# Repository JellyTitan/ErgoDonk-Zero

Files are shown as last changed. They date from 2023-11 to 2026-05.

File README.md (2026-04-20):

# ErgoDonk Zero Keyboard

ErgoDonk Zero is a 6×9+6 keys split ortholinear keyboard with encoder & solenoid support, hotswap sockets for MX or Choc v1 low profile switches, and uses the RP2040 "Zero" MCU.

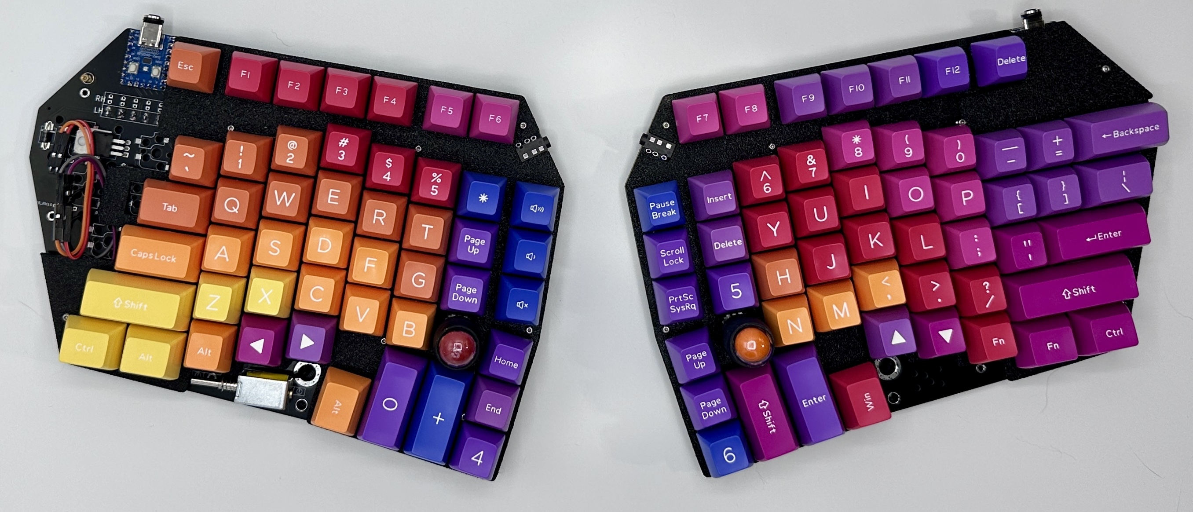
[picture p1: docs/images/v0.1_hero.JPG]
Ergodonk simple zero v0.1


> [!IMPORTANT]
> The hardware is under active development! Documentation, QMK PR, and VIA PR's are the bulk of the remaining work. The remaining tasks can be seen at [ergodonk.com/status](https://www.ergodonk.com/status)
> Build guide and other supporting documentation can be found at [ergodonk.com](https://www.ergodonk.com)

***

## BUILD GUIDE

The build guide can be found at [ergodonk.com](https://www.ergodonk.com/).

***

## PCB 

PCB ordering guide can be found at [ergodonk.com/build/pcb-ordering](https://www.ergodonk.com/build/pcb-ordering).

ErgoDonk Zero [KiCad files](https://github.com/JellyTitan/ErgoDonk-Zero/tree/main/PCB).\
ErgoDonk Zero [Gerber files](https://github.com/JellyTitan/ErgoDonk-Zero/tree/main/PCB/gerbers).

***

## CASES

3d printable case and keyplate can be found [on printables](https://www.printables.com/model/738066-ergodonk-zero-case).
Acrylic plate case can be found [here](https://github.com/JellyTitan/ErgoDonk-Zero/tree/main/Case).

***

## CREDITS

The ErgoDonk Zero was designed by [Ryan Neff](https://github.com/JellyTitan). Many of the footprints came from the well-regarded foostan [kbd library](https://github.com/foostan/kbd).

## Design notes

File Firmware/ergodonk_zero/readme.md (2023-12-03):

# ergodonk_zero

ergodonk_zero

*A short description of the keyboard/project*

* Keyboard Maintainer: [Ryan Neff](https://github.com/Ryan Neff)
* Hardware Supported: *The PCBs, controllers supported*
* Hardware Availability: *Links to where you can find this hardware*

Make example for this keyboard (after setting up your build environment):

    make ergodonk_zero:default

Flashing example for this keyboard:

    make ergodonk_zero:default:flash

See the [build environment setup](https://docs.qmk.fm/#/getting_started_build_tools) and the [make instructions](https://docs.qmk.fm/#/getting_started_make_guide) for more information. Brand new to QMK? Start with our [Complete Newbs Guide](https://docs.qmk.fm/#/newbs).

## Bootloader

Enter the bootloader in 3 ways:

* **Bootmagic reset**: Hold down the key at (0,0) in the matrix (usually the top left key or Escape) and plug in the keyboard
* **Physical reset button**: Briefly press the button on the back of the PCB - some may have pads you must short instead
* **Keycode in layout**: Press the key mapped to `QK_BOOT` if it is available

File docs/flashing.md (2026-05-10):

---
layout: page
title: Flashing QMK Firmware
description: How to flash the ErgoDonk Zero keyboard with QMK firmware. Covers drag-and-drop UF2 flashing, reset procedure, and building custom firmware.
permalink: flashing
nav_order: 3
# has_children: true
# Structured data: renders _includes/structured_data/flashing_howto.html into <head> via _includes/head_custom.html.
# Remove or rename this key to disable.
schema: flashing-howto
---

# Flashing QMK Firmware
{: .no_toc }

{: .warning}
> Earlier versions of the ErgoDonk Zero required flashing each half with unique files. As of May 2026, each hand is flashed with the same file. The left hand is now the primary side. If you want to connect your USB cable to the right side, you'll need to use a specific `.uf2` file listed below.

After the first 'drag and drop' flash, you can tweak your keymaps further using [VIA](https://www.caniusevia.com/). ErgoDonk Zero is not yet merged into the main VIA repo. Until then, you can [use the via config manually](VIA.md).

<hr>

## Table of contents
{: .no_toc .text-delta }

1. TOC
{:toc}

## Drag and drop flashing (the easy way)

The rp2040 supports 'drag and drop' flashing with a UF2 file on Mac or PC. This is the recommended approach if you're not familiar with compiling QMK firmware yourself. After the first 'drag and drop' flash, you can tweak your keymaps further using [VIA](https://www.caniusevia.com/).

These instructions are a summary of the [official explanation found in the QMK docs](https://docs.qmk.fm/#/flashing?id=raspberry-pi-rp2040-uf2).

To flash with 'drag 'n drop':
1. Make sure halves are not connected together with TRS cable.
1. Connect one half to USB.
1. Enter the bootloader using any of the following methods. These are dependent on where your RP2040 Zero came from.
    * Hold down `BOOT` and tap `RESET`.
    * Hold the `BOOT` button while plugging in the USB cable.
    * Double tapping the `RESET` button on the RP2040. ([Double tap reset is enabled by default on the RP2040](https://github.com/qmk/qmk_firmware/blob/master/docs/platformdev_rp2040.md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)).
    * **Bootmagic reset** (works after you have flashed once): Hold down the `d` key when plugging in the left half, or hold `j` when plugging in the right half. This will also clear the EEPROM.
1. Copy the .uf2 file to the new USB disk. The files can be found in the [ErgoDonk Zero repo](https://github.com/JellyTitan/ErgoDonk-Zero/tree/main/Firmware/drag_and_drop). *Each hand will be flashed with the same file.* There are a few different variants you have to choose from when starting out:
    * [`ergodonk_zero_via.uf2`](https://github.com/JellyTitan/ErgoDonk-Zero/blob/main/Firmware/drag_and_drop/ergodonk_zero_via.uf2){:target="_blank"} Default configuration with VIA support included. Choose this if this is your first time.
    * [`ergodonk_zero_default.uf2`](https://github.com/JellyTitan/ErgoDonk-Zero/blob/main/Firmware/drag_and_drop/ergodonk_zero_default.uf2){:target="_blank"} Default configuration, the same as in QMK. No VIA support.
    * [`ergodonk_zero_jellytitan.uf2`](https://github.com/JellyTitan/ErgoDonk-Zero/blob/main/Firmware/drag_and_drop/ergodonk_zero_jellytitan.uf2){:target="_blank"} My personal configuration, has VIA support and some fancy macros.
    * [`ergodonk_zero_via_rh.uf2`](https://github.com/JellyTitan/ErgoDonk-Zero/blob/main/Firmware/drag_and_drop/ergodonk_zero_via_rh.uf2){:target="_blank"} Default QMK configuration with VIA support and right hand set as primary. Solenoid not supported with right hand as primary.
    * On Mac after the file is dropped, the 'Keyboard setup assistant' may be triggered. You can ignore and quit the assistant.
1. Unplug the side you just flashed, and repeat the process with the other side.
1. Disconnect both halves from USB. 
1. Connect both halves together using the TRS cable. 
1. Connect the left half to USB. (If you chose a right hand variant, connect the right half to USB).
1. Test everything using VIA. (Earlier versions of VIA were downloaded and installed. The latest version, VIA 3, is accessed through the web interface).

## Compile QMK for flashing (the hard way)

If you want to build your own firmware, ErgoDonk Zero uses [QMK Firmware][qmk_firmware]. Support is not in the main QMK repository yet. **@todo: Update this url with official PR**. Instead use the [jellytitan/qmk_firmware](https://github.com/JellyTitan/qmk_firmware/tree/ergodonk_zero){:target="_blank"} fork and the `ergodonk_zero` branch.

To flash:
- Clone [https://github.com/jellytitan/qmk_firmware](https://github.com/jellytitan/qmk_firmware){:target="_blank"}
- Switch to the `ergodonk_zero` branch with `git checkout ergodonk_zero`
- Make sure your QMK environment [is set up][qmkintro].
- Make sure halves are _not_ connected together with TRS cable.
- Connect one half to USB, flash the firmware. Always follow the current instructions in the QMK documentation! The command might look something like this: `make ergodonk_zero:default:flash`. Use the reset button to reset the keyboard when you are asked to in console. 
- Connect the second half and flash it in the same way as the previous one.
- Disconnect the USB cable. Connect both halves together with TRS cable.
- Connect USB cable to the **left** side.
- Enjoy!

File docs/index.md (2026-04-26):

---
layout: page
title: ErgoDonk Zero Keyboard
description: ErgoDonk Zero is an open source split ortholinear keyboard with hotswap MX/Choc support, solenoid, encoder, and RP2040 Zero MCU. A great first ergo build.
nav_order: 1
image: /images/v0.1_hero-1200w.webp
# Structured data: renders _includes/structured_data/home_creativework.html into <head> via _includes/head_custom.html.
# Remove or rename this key to disable.
schema: home-creativework
---

{% comment %}
  Local build command: bundle exec jekyll serve 
  Image aspect ratio should be 3:5 unless there is an intentional deviation.
  Adds lightbox to links around images:
  https://jekyllcodex.org/without-plugin/lightbox/

  The images are in a non-markdown format to create responsive image variants at build time. 
  You can use markdown syntax, it will work fine. It's just not as performant.

{% endcomment %}

{% assign img1 = site.data.image_manifest["images/v0.1_hero.JPG"] %}
{% assign img2 = site.data.image_manifest["images/sa_heights.png"] %}
{% assign img3 = site.data.image_manifest["images/ErgoDonk_row_heights.png"] %}

# ErgoDonk Zero Keyboard

ErgoDonk Zero is a 6×9+6 keys split ortholinear keyboard with encoder & solenoid support, hotswap sockets for MX or Choc v1 low profile switches, and uses the RP2040 "Zero" MCU.

The ErgoDonk Zero was designed by [Ryan Neff](https://github.com/JellyTitan). Many of the footprints came from the well-regarded foostan [kbd library](https://github.com/foostan/kbd). 
<figure>
  {% include slider_img_srcset.html 
    src="images/v0.1_hero.JPG" 
    alt="ErgoDonk Zero split keyboard v0.1 hero image" 
    manifest=img1
    eager=true
    fetchpriority="high" 
  %}
</figure>

## Overview
The ErgoDonk Zero was designed to be a good first split ortholinear keyboard. It is inexpensive, the parts are accessible, it's easy to build, and it has a key layout that is still familiar to non-split Qwerty users. 

It can be used with any MX [keycap profile](https://www.reddit.com/r/MechanicalKeyboards/comments/j484j5/keycap_profiles_i_compiled_a_direct_comparison/), but is designed specifically for the ergonomic SA keycap profile. The E0 has been designed to use off-the-shelf keycap sets. The layout leverages the variable height profile of SA keycaps. 

<figure>
  {% include slider_img_srcset.html 
    src="images/sa_heights.png" 
    alt="SA Keycap row heights" 
    manifest=img2 
  %}
</figure>

{% comment %}
@todo get image of the SA profiles from the thumb and sides.
{% endcomment %}

<div>
  <a href="http://www.keyboard-layout-editor.com/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" target="_blank" rel="noopener noreferrer" aria-label="ErgoDonk Zero row heights on keyboard-layout-editor.com (opens in new tab)">
    {% 
        include img_srcset.html 
        src="images/ErgoDonk_row_heights.png" 
        alt="ErgoDonk Zero row heights represented by keyboard-layout-editor.com" 
        manifest=img3
      %}
  </a>
</div>

## Design philosophy
The ErgoDonk Zero is designed with the following goals:
* Comfort & ergonomics
  * Ortholinear.
  * Split.
  * Tiltable. Has tenting puck mounting holes. [SplitKB](https://splitkb.com/products/tenting-puck) or 3d print your own: design by [
Bubbleology](https://www.printables.com/model/235433-tenting-puck-for-keyboard-tripod-mount/comments/943096).
  * Thumb clusters designed to use SA variable height keycaps
* Accessible
  * Uses standard key cap sets. 
  * Can use either MX or Choc V1 low profile key switches.
  * Through-hole components used for easy soldering.
  * "Drag and drop" MCU flashing.
  * Uses VIA for easy customization.
  * [Supports more keys](http://www.keyboard-layout-editor.com/#/gists/ac776db3b0deef94de51943c384cfdfc) than a traditional split ergo, making it a good transition to a smaller split, or for those who really like their "F" keys.
* Low cost
  * The PCB is reversible to reduce manufacturing costs.
  * Uses RP2040 Zero. (Inexpensive clones are readily available for ~$3USD)
  * Does not require expensive split-specific key cap sets.

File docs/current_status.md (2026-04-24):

---
layout: page
title: Current Project Status
description: Current development status for the ErgoDonk Zero keyboard. Hardware is stable at v0.2 — see open punch list items for QMK, VIA, and documentation tasks.
permalink: /status
nav_order: 2
has_children: true
---

# Current Project status

UPDATE: April 2026. After a break, I'm back at it.
While the current hardware iteration is stable and functional, (v0.2) there are some supporting tasks still in progress. Specifically, QMK & VIA commits, documenting case variants. 

## Punch list

### Hardware
* ☐ Create a new logo 
* ☐ Consider creating a choc key plate variant with cutouts for the diodes on the front?
* ☐ Validate the new and old tenting puck holes are good.
* ☐ Try putting a smaller 3v Solenoid on each hand.
* ☐ ~~Create~~ Validate a tip120 bending jig.
* ☐ When using PCBA, all the matrix intersections will get a diode. I think this is what's breaking the handedness by matrix intersection setting in QMK. Consider add a jumper for the RH Backspace key, so that even if PCBA is used, the handedness detection by matrix intersection will still work.
* ☐ Use the Zero LED as a layer indicator. Example qmk_firmware/keyboards/handwired/alcor_dactyl
* ☐ Update case to include hole above layer indicator LED. 
* ☐ Improve Acrylic keyplates. (Maybe one for each hand)?
* ☐ Adjust key labels before production. (There are a few under holes)
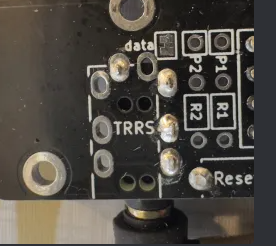
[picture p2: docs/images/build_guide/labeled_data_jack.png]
labeled data jack
* ☐ Add data label to the TRS/TRRS jack for easier debugging. <br>
* ☐ Add dimensions to Acrylic case file names. (Elecrow doesn't autodetect the dimensions).

### Documentation
* ☐ Use the new logo to generate the Favicon
* ☐ Add a page detailing the differences between ErgoDonk and ErgoDonk Zero
* ☐ Document more appealing default key layout.
* ☐ Add notes to the build guide, about how the symbols on the key cap should not correspond to the actual key presses, and the default layout is an adaptation of the Ergodox.
* ☐ Add note about how great those magnetic data cables are.
* ☐ Add note in the build guide about the key layout using the ergonomic height of the SA keys and add images demonstrating. 
* ☐ Add note about the merits of AliExpress vs other vendors.
* ☐ fix hot swap socket graphic with iconography. (Currently two red arrows - maybe a green check and a red 'no')?
* ☐ Strip GEO metadata from all images.
* ☐ Add diode punch outs for the bending jig
* ☐ Add gem to open images in modal. (There are hq images that are presented small-ish).
  
### QMK 
* ☐ Before submitting QMK PR, update version number in `info.json`

### VIA
* ☐ Refactor VIA PR to match the new simplified QMK base keymap
* ☐ [Draft PR](https://github.com/the-via/keyboards/pull/2208) created, blocked by QMK merge.

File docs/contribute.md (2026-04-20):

---
layout: page
title: Contributing
description: How to contribute to the ErgoDonk Zero open source keyboard project. Guidelines for submitting PCB variants, new cases, firmware changes, and documentation updates.
permalink: /contributing
nav_order: 7
# has_children: true
---

# ErgoDonk Zero is open source - feel free to help out!
{: .no_toc }
**The ErgoDonk Zero's PCB & schematics have been intentionally designed to make it easy to swap in alternative switch footprints. Modifications and variants are encouraged!**

## Table of contents
{: .no_toc .text-delta }

1. TOC
{:toc}

## License
* Hardware source files are licensed under [MIT license](https://raw.githubusercontent.com/JellyTitan/ErgoDonk-Zero/main/LICENSE).
* The documentation is licensed under [Creative Commons Attribution 4.0 International (CC BY 4.0) license](https://creativecommons.org/licenses/by/4.0/). This includes all photos and images in this repository and on the website.
* Firmware is part of [QMK firmware](https://qmk.fm/) and has the same license (GPL v2)

## Contribution guidelines

When making hardware contributions, please use "[Semantic versioning](https://semver.org/)".

To avoid 'breaking changes' when creating ErgoDonk Zero variants, please keep the following in mind:
- Changing the outline or moving the locations of the PCB, jack, knob, or switches would break compatibility between cases.
- Changing the schematic pinout would require a different QMK & VIA build and _may_ be considered a breaking change. However, there are several unused pins, please use those for adding new stuff. Currently QMK is migrating to a .json based keyboard config, so pinout changes may be easier in the future.
- Please prototype the variant before making a PR.
- Please create a case if the variant is not compatible with existing cases.
- Please include all footprints, symbols, and 3d models in the repo.
- If you use open source work, please attribute.
- Update the README / documentation of your changes as necessary.

## ErgoDonk Zero Future feature wish list
There are some features that I would like to add if time permits. Open to contributions.
* [ ] Plate mount stabilizers. Currently has PCB mount only, but would like to support both types.
* [ ] Write a PCBA ordering walk through. I pulled images for the process with the ErgoDonk Zero - but never wrote a guide.

## Features to add to future keyboards
* Space 2mm and 4mm case holes evenly around the perimeter for monoblock type cases.
* Consider moving TRS and Zero jack back a bit so they sit flush with the edge of the board. This would make it easier to use 'monoblock' cases.
* Be sure to rotate the thumb cluster keys when building a LED variant.

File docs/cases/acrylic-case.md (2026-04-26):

---
layout: page
title: Acrylic
description: Acrylic sandwich case for the ErgoDonk Zero keyboard. Includes BOM with standoff sizes, DXF files for laser cutting, and sourcing notes for Elecrow orders.
parent: Case Options
permalink: /cases/acrylic-case
nav_order: 1
image: /images/acrylic_case/acrylic_tilted_hero-1200w.webp
---

{% assign img1 = site.data.image_manifest["images/acrylic_case/acrylic_tilted_hero.jpeg"] %}
{% assign img2 = site.data.image_manifest["images/acrylic_case/knob_close_up.jpeg"] %}
{% assign img3 = site.data.image_manifest["images/acrylic_case/acrylic_handsome_stack.jpeg"] %}
{% comment %}
  Tables on this page use static HTML instead of markdown pipe syntax because
  kramdown does not process Liquid includes ({% include %}) inside markdown table cells.

  When multiple images appear together in a single <td>, they must be wrapped in a <p>
  tag. The slider lightbox identifies image groups by their shared parent element —
  without the wrapper, left/right navigation between adjacent images will not work.
{% endcomment %}
{% assign img4 = site.data.image_manifest["images/acrylic_case/keyplate.png"] %}
{% assign img5 = site.data.image_manifest["images/acrylic_case/backplate.png"] %}
{% assign img6 = site.data.image_manifest["images/acrylic_case/solenoid_cover_plate_LH.jpeg"] %}
{% assign img7 = site.data.image_manifest["images/acrylic_case/solenoid_blank_cover_plate_RH.jpeg"] %}
{% assign img8 = site.data.image_manifest["images/acrylic_case/solenoid_cover.png"] %}
{% assign img9 = site.data.image_manifest["images/acrylic_case/acrylic_lh_mcu_cover.jpeg"] %}
{% assign img10 = site.data.image_manifest["images/acrylic_case/LH_MCU_cover.png"] %}
{% assign img11 = site.data.image_manifest["images/acrylic_case/acrylic_rh_mcu_cover.jpeg"] %}
{% assign img12 = site.data.image_manifest["images/acrylic_case/RH_MCU_cover.png"] %}
{% assign img13 = site.data.image_manifest["images/acrylic_case/m2_6mm_standoff.JPG"] %}
{% assign img14 = site.data.image_manifest["images/acrylic_case/m2_12mm_standoff.JPG"] %}
{% assign img15 = site.data.image_manifest["images/acrylic_case/m2_16mm_standoff.png"] %}
{% assign img16 = site.data.image_manifest["images/acrylic_case/m2_9mm_standoff.png"] %}
{% assign img17 = site.data.image_manifest["images/acrylic_case/bumper_locations.JPG"] %}

# Acrylic case

{: .info}
>  Files are in the [GitHub repo (Cases/Acrylic/production_ready)](https://github.com/JellyTitan/ErgoDonk-Zero/tree/main/Cases/Acrylic/production_ready).

<hr>
<p class="image-grid-3">
{% include slider_img_srcset.html src="images/acrylic_case/acrylic_tilted_hero.jpeg" alt="Acrylic ErgoDonk Zero case, tilted hero shot" manifest=img1 eager=true fetchpriority="high" %} 
{% include slider_img_srcset.html src="images/acrylic_case/knob_close_up.jpeg" alt="Acrylic ErgoDonk Zero case, close-up of the rotary encoder knob" manifest=img2 eager=true fetchpriority="low" %} 
{% include slider_img_srcset.html src="images/acrylic_case/acrylic_handsome_stack.jpeg" alt="Acrylic ErgoDonk Zero case, both halves stacked" manifest=img3 eager=true fetchpriority="low"  %}   
</p>

<hr>

## Details

These don't retain the switches as tightly as the 3d printed cases, but they look fantastic. 

Rather than purchase multiple size female-female 2mm standoffs, using an '[assortment box](https://www.amazon.com/gp/product/B07B9X1KY6)' is much easier.

The production ready files for upload can be found in the "production_ready" folder. They are zipped .dxf files. I recommend 3mm thickness. Some online vendors ask you to manually input the dimensions for pricing. Dimensions can be found in the BOM remarks below.

<hr>

## BOM

<table>
  <thead>
    <tr>
      <th scope="col">Name</th>
      <th scope="col">Count</th>
      <th scope="col">Remarks</th>
      <th scope="col">Potential Storefront</th>
      <th scope="col">Image</th>
    </tr>
  </thead>
  <tbody>
    <tr>
      <td>keyplates</td>
      <td>2</td>
      <td>Use the same file for both sides: <code>Ergodonk_Zero_v0.2_keyplate.dxf.zip</code><br> Dimensions: <code>217mm x 157mm</code></td>
      <td><a href="https://www.elecrow.com/">Elecrow</a></td>
      <td>
        {% include slider_img_srcset_thumb.html
            src="images/acrylic_case/keyplate.png"
            alt="Acrylic ErgoDonk Zero key plate"
            manifest=img4
        %}
      </td>
    </tr>
    <tr>
      <td>backplates</td>
      <td>2</td>
      <td>Use the same file for both sides: <code>Ergodonk_Zero_v0.2.1_bottom_plate.dxf.zip</code><br> Dimensions: <code>217mm x 157mm</code></td>
      <td><a href="https://www.elecrow.com/">Elecrow</a></td>
      <td>
        {% include slider_img_srcset_thumb.html
            src="images/acrylic_case/backplate.png"
            alt="Acrylic ErgoDonk Zero back plate"
            manifest=img5
        %}
      </td>
    </tr>
    <tr>
      <td>Solenoid cover</td>
      <td>2</td>
      <td>Use the same file for both sides: <code>Ergodonk_Zero_v0.2_Solenoid_cover.dxf.zip</code><br> Dimensions: <code>55mm x 25mm</code></td>
      <td><a href="https://www.elecrow.com/">Elecrow</a></td>
      <td>
        <p>
          {% include slider_img_srcset_thumb.html
              src="images/acrylic_case/solenoid_cover_plate_LH.jpeg"
              alt="Left hand acrylic ErgoDonk Zero solenoid cover plate"
              manifest=img6
          %}
          {% include slider_img_srcset_thumb.html
              src="images/acrylic_case/solenoid_blank_cover_plate_RH.jpeg"
              alt="Right hand acrylic ErgoDonk Zero blank solenoid cover plate"
              manifest=img7
          %}
          {% include slider_img_srcset_thumb.html
              src="images/acrylic_case/solenoid_cover.png"
              alt="Acrylic ErgoDonk Zero solenoid cover plate diagram"
              manifest=img8
          %}
        </p>
      </td>
    </tr>
    <tr>
      <td>Left Hand MCU cover</td>
      <td>1</td>
      <td>Left hand only. Notice this covers empty sockets that are not used on the left hand. If you don't like seeing those, select an opaque acrylic. <br> <code>Ergodonk_Zero_v0.2_LH_MCU_Cover.dxf.zip</code><br> Dimensions: <code>78mm x 97mm</code></td>
      <td><a href="https://www.elecrow.com/">Elecrow</a></td>
      <td>
        <p>
          {% include slider_img_srcset_thumb.html
              src="images/acrylic_case/acrylic_lh_mcu_cover.jpeg"
              alt="Left hand Acrylic ErgoDonk Zero MCU cover plate"
              manifest=img9
          %}
          {% include slider_img_srcset_thumb.html
              src="images/acrylic_case/LH_MCU_cover.png"
              alt="Left hand Acrylic ErgoDonk Zero MCU cover plate"
              manifest=img10
          %}
        </p>
      </td>
    </tr>
    <tr>
      <td>Right Hand MCU cover</td>
      <td>1</td>
      <td>Right hand only: <code>Ergodonk_Zero_v0.2_RH_MCU_Cover.dxf.zip</code><br> Dimensions: <code>78mm x 40mm</code></td>
      <td><a href="https://www.elecrow.com/">Elecrow</a></td>
      <td>
        <p>
          {% include slider_img_srcset_thumb.html
              src="images/acrylic_case/acrylic_rh_mcu_cover.jpeg"
              alt="Right hand Acrylic ErgoDonk Zero MCU cover plate"
              manifest=img11
          %}
          {% include slider_img_srcset_thumb.html
              src="images/acrylic_case/RH_MCU_cover.png"
              alt="Right hand Acrylic ErgoDonk Zero MCU cover plate"
              manifest=img12
          %}
        </p>
      </td>
    </tr>
    <tr>
      <td>M2 5mm screws</td>
      <td>56</td>
      <td>Any old M2 will do. I prefer 'button head' for aesthetics. 4mm or 6mm works too, but 6mm may bottom out.</td>
      <td><a href="https://www.amazon.com/gp/product/B07ZH6GRK2">Amazon</a><br><a href="https://www.aliexpress.us/item/3256805706765925.html">AliExpress</a></td>
      <td>X</td>
    </tr>
    <tr>
      <td>M2 6mm female-female standoffs</td>
      <td>16</td>
      <td>Connects the front plate to the back plate, runs <em>through</em> the pcb. Aluminum versions are available, but I've found they tend to arrive 'greasy' or oxidized, so I recommend the brass versions. Left hand uses 7, right hand uses 9.</td>
      <td><a href="https://www.amazon.com/gp/product/B07B9X1KY6">Amazon</a><br><a href="https://www.aliexpress.us/item/3256804317893173.html">AliExpress</a></td>
      <td>
        {% include slider_img_srcset_thumb.html
            src="images/acrylic_case/m2_6mm_standoff.JPG"
            alt="Acrylic ErgoDonk Zero MCU key plate attached to back plate with 6mm M2 female-female standoffs"
            manifest=img13
        %}
      </td>
    </tr>
    <tr>
      <td>M2 12mm female-female standoffs</td>
      <td>6</td>
      <td>Connects the MCU cover plate to the back plate, runs <em>through</em> the pcb and the key plate. Left hand uses 4, right hand uses 2.</td>
      <td><a href="https://www.amazon.com/gp/product/B07B9X1KY6">Amazon</a><br><a href="https://www.aliexpress.us/item/3256804317893173.html">AliExpress</a></td>
      <td>
        {% include slider_img_srcset_thumb.html
            src="images/acrylic_case/m2_12mm_standoff.JPG"
            alt="Acrylic ErgoDonk Zero MCU cover plate attached with 12mm M2 female-female standoffs"
            manifest=img14
        %}
      </td>
    </tr>
    <tr>
      <td>M2 16mm female-female standoffs</td>
      <td>3</td>
      <td>Connects the left hand solenoid cover plate to the back plate, runs <em>through</em> the pcb and the key plate.</td>
      <td><a href="https://www.amazon.com/gp/product/B07B9X1KY6">Amazon</a><br><a href="https://www.aliexpress.us/item/3256804317893173.html">AliExpress</a></td>
      <td>
        {% include slider_img_srcset_thumb.html
            src="images/acrylic_case/m2_16mm_standoff.png"
            alt="Left hand Acrylic ErgoDonk Zero solenoid cover plate attached with 16mm M2 female-female standoffs"
            manifest=img15
        %}
      </td>
    </tr>
    <tr>
      <td>M2 9mm female-female standoffs</td>
      <td>3</td>
      <td>Connects the right hand solenoid cover plate to the back plate, runs <em>through</em> the pcb and the key plate. 10mm is fine too.</td>
      <td><a href="https://www.amazon.com/gp/product/B07B9X1KY6">Amazon</a><br><a href="https://www.aliexpress.us/item/3256804317893173.html">AliExpress</a></td>
      <td>
        {% include slider_img_srcset_thumb.html
            src="images/acrylic_case/m2_9mm_standoff.png"
            alt="Right hand Acrylic ErgoDonk Zero solenoid cover plate attached with 16mm M2 female-female standoffs"
            manifest=img16
        %}
      </td>
    </tr>
    <tr>
      <td>2mm adhesive Rubber bumper feet.</td>
      <td>10</td>
      <td>These keep the board from sliding on the desk. Put 5 on the bottom side of each hand to keep from sliding on the desk.</td>
      <td><a href="https://www.amazon.com/ROCHU-Self-Adhesive-Rubber-Bumpons-Furniture/dp/B073SVKFYJ">Amazon</a></td>
      <td>
        {% include slider_img_srcset_thumb.html
            src="images/acrylic_case/bumper_locations.JPG"
            alt="Bumper feet locations"
            manifest=img17
        %}
      </td>
    </tr>
  </tbody>
</table>

<hr>

## About these plates
This case was created by exporting svg layers directly from KiCad. The Svg's were imported into Fusion360 with a 3.7795% scale. (Not sure why the KiCad exports are so small - but that multiplier seems to get them where they need to go). From Fusion360, the outlines are exported as a .dxf. The .dxf's have been zipped because the only vendor I've tested these with is Elecrow. If you need another file type, you can find the initial svg's in the 'source' folder.

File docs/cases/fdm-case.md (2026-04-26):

---
layout: page
title: 3D Printable FDM Case
parent: Case Options
permalink: /cases/fdm-case
description: 3D printable FDM case for the ErgoDonk Zero keyboard. STL files for MX switches with keyplate, monobody cover, and optional backplate. Also available on Printables.
nav_order: 3
image: /images/fdm_case/fdm_donk_1.webp
# published: false
---

{% assign img1 = site.data.image_manifest["images/fdm_case/fdm_donk_1.webp"] %}
{% assign img2 = site.data.image_manifest["images/fdm_case/fdm_donk_2.webp"] %}
{% assign img3 = site.data.image_manifest["images/fdm_case/fdm_donk_3.webp"] %}

# 3d printable ErgoDonk Zero case

{: .info}
> Files are in the [GitHub repo (Cases/3d_printable_case)](https://github.com/JellyTitan/ErgoDonk-Zero/tree/main/Cases/3d_printable_case).
> This is also posted on [Printables](https://www.printables.com/model/738066-ergodonk-zero-case). You'll find the latest discussion there.

<hr>
<p class="image-grid-3">
{% include slider_img_srcset.html src="images/fdm_case/fdm_donk_1.webp" alt="3d printed ErgoDonk Zero case" manifest=img1 eager=true fetchpriority="high" %}
{% include slider_img_srcset.html src="images/fdm_case/fdm_donk_2.webp" alt="Close up of right hand ErgoDonk Zero 3d printed case" manifest=img2 eager=true fetchpriority="low" %}
{% include slider_img_srcset.html src="images/fdm_case/fdm_donk_3.webp" alt="Back of 3d printed ErgoDonk Zero case without the optional back plate." manifest=img3 eager=true fetchpriority="low" %}
</p>

<hr>

## Details
Designed for use with MX switches. 

Right and Left hand cases are unique and not interchangeable. 

The keyplate is mirrored for the right and left hand. They are split into separate files with a LH/RH suffix to prevent any confusion. They should be printed with the notches up, and the side that shows through the keys is against the build plate. They are oriented that way in the .stl & gcode files.

You can add print helper objects to keep the edges from curling. There is a ‘sacrificial’ support below the bridge that connects the island in the middle of the thumb cluster. Snap that off by hand. (It's highlighted in the image with the yellow arrow).

The backplate of the case is optional.

Use 8mm screws if the backplate is used. If no back plate is used, go with 4mm screws.

The fusion 360 source files for the ErgoDonk-Zero can be found on [printables](https://www.printables.com/model/738066-ergodonk-zero-case/files). 

<hr>

## About these plates
The key plates for this case were created by exporting svg layers directly from KiCad. The Svg's were imported into Fusion360 with a 3.7795% scale. (Not sure why the KiCad exports are so small - but that multiplier seems to get them where they need to go). The svg sketches were fixed up, then extruded to 3mm.

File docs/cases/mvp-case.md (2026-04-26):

---
layout: page
title: Minimalist Keyplate Case
description: Minimalist ErgoDonk Zero case using only a 3D-printed keyplate. Works with or without a backplate — great for showing off a bare PCB with minimal hardware.
parent: Case Options
permalink: /cases/mvp-case
nav_order: 4
image: /images/mvp_case/mvp_case_both-1200w.webp
# published: false
---

{% assign img1 = site.data.image_manifest["images/acrylic_case/keyplate.png"] %}
{% assign img2 = site.data.image_manifest["images/acrylic_case/bumper_locations.JPG"] %}
{% comment %}
  Local build command: bundle exec jekyll serve 
  Image aspect ratio should be 3:5
  Adds lightbox to links around images:
  https://jekyllcodex.org/without-plugin/lightbox/

   - @todo - need to optimize images - way too big.

  Tables on this page use static HTML instead of markdown pipe syntax because
  kramdown does not process Liquid includes ({% include %}) inside markdown table cells.

  When multiple images appear together in a single <td>, they must be wrapped in a <p>
  tag. The slider lightbox identifies image groups by their shared parent element —
  without the wrapper, left/right navigation between adjacent images will not work.
{% endcomment %}

# Minimalist ErgoDonk Zero case

For those that like the look of a bare pcb with the minimum viable case. Also known as a "naked case".

{: .warning}
>  Beware - this case collects cat hair like it's going out of style. Expect a tear-down cleaning at least yearly. 
<hr>
{% assign p1 = site.data.image_manifest["images/mvp_case/mvp_case_both.JPG"] %}
{% assign p2 = site.data.image_manifest["images/mvp_case/mvp_case_left_closeup.JPG"] %}
{% assign p3 = site.data.image_manifest["images/mvp_case/mvp_case_back.JPG"] %}
<p class="image-grid-3">
{% include slider_img_srcset.html
   src="images/mvp_case/mvp_case_both.JPG"
   alt="ErgoDonk Zero minimalist case, both hands"
   eager=true
   fetchpriority="high" 
   manifest=p1 %}

   {% include slider_img_srcset.html
   src="images/mvp_case/mvp_case_left_closeup.JPG"
   alt="ErgoDonk Zero minimalist case, left hand close-up"
   eager=true
   fetchpriority="low"
   manifest=p2 %}

   {% include slider_img_srcset.html
   src="images/mvp_case/mvp_case_back.JPG"
   alt="Minimal ErgoDonk case with only a keyplate"
   eager=true
   fetchpriority="low"
   manifest=p3 %}
</p>
<hr>

## Details

You can get away with only a 3d printed keyplate. You can add some rubber bumpers on the underside of the pcb if you're feeling fancy. You could even get away without the key plate, but the switches will likely rock in their sockets. This setup has been my daily driver for the last year, and it's been lovely. In the pictures above, the left hand is the 'thickaronie' keyplate, while the right hand is a 3d print of the acrylic keyplate. I didn't bother with bumpers on the underside because I'm on a non-conductive desk. I'm happy to report that no keys popped out, and nothing short circuited.

The 3d printed keyplate is the easiest method. You can find the source files for the keyplates in [this repo](https://github.com/JellyTitan/ErgoDonk-Zero/tree/main/Cases/3d_printable_case) or on [printables](https://www.printables.com/model/738066-ergodonk-zero-case). 

You could also print the source file for the acrylic key plate, and use it as a template to cut a keyplate from cardboard.[8.5x11 & A4 pdf's of the keyplate](https://github.com/JellyTitan/ErgoDonk-Zero/tree/main/Cases/mvp_case) can be found in the github repo. Be sure to print at 100%, and test one key hole before cutting out the whole thing. Many printers default to 96% to offset the printer margins.
<figure>
{% assign p4 = site.data.image_manifest["images/mvp_case/mvp_case_print_settings.png"] %}
{% include img_srcset.html
   src="images/mvp_case/mvp_case_print_settings.png"
   alt="Print dialog with scale percentage highlighted"
   manifest=p4
%}
<figcaption>Don't forget to check print size!</figcaption>
</figure>
Rubber bumpers on the bottom can be subbed out for bumps of hot glue, or omitted entirely if you're using a desk mat that isn't conductive. If you go that route, you might want to clean up your flux and nip your solder joints flat so you don't tear up your desk.

## BOM

<table>
  <thead>
    <tr>
      <th scope="col">Name</th>
      <th scope="col">Count</th>
      <th scope="col">Remarks</th>
      <th scope="col">Potential Storefront</th>
      <th scope="col">Image</th>
    </tr>
  </thead>
  <tbody>
    <tr>
      <td>Left &amp; right hand keyplates</td>
      <td>1</td>
      <td>Use the 2 <a href="https://www.printables.com/model/738066-ergodonk-zero-case">ErgoDonk Zero keyplate files found on printables</a>.</td>
      <td></td>
      <td>
        {% include slider_img_srcset_thumb.html
            src="images/acrylic_case/keyplate.png"
            alt="Acrylic ErgoDonk Zero key plate"
            manifest=img1
        %}
      </td>
    </tr>
    <tr>
      <td>2mm adhesive Rubber bumper feet.</td>
      <td>10</td>
      <td>These keep the board from sliding on the desk. Put 5 on the bottom side of each hand to keep from sliding on the desk.</td>
      <td><a href="https://www.amazon.com/ROCHU-Self-Adhesive-Rubber-Bumpons-Furniture/dp/B073SVKFYJ">Amazon</a></td>
      <td>
        {% include slider_img_srcset_thumb.html
            src="images/acrylic_case/bumper_locations.JPG"
            alt="Bumper feet locations"
            manifest=img2
        %}
      </td>
    </tr>
  </tbody>
</table>

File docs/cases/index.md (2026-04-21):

---
layout: page
title: Case Options
permalink: /cases
description: "ErgoDonk Zero case options: acrylic sandwich, FDM 3D-printed, or bare PCB with keyplate."
nav_order: 6
has_children: true
image: /images/acrylic_case/acrylic_tilted_hero-1200w.webp
---

{% assign img1 = site.data.image_manifest["images/acrylic_case/acrylic_tilted_hero.jpeg"] %}
{% assign img2 = site.data.image_manifest["images/fdm_case/fdm_donk_cases_hero.jpeg"] %}
{% assign img3 = site.data.image_manifest["images/mvp_case/mvp_case_both.JPG"] %}

# ErgoDonk Zero Cases

<p class="image-grid-3">
{% include slider_img_srcset.html src="images/acrylic_case/acrylic_tilted_hero.jpeg" alt="Acrylic ErgoDonk Zero case" manifest=img1 eager=true fetchpriority="high" %} 
{% include slider_img_srcset.html src="images/fdm_case/fdm_donk_cases_hero.jpeg" alt="Ergodonk zero 3d printed case" manifest=img2 eager=true fetchpriority="low" %}
{% include slider_img_srcset.html src="images/mvp_case/mvp_case_both.JPG" alt="ErgoDonk with a naked minimalist case" manifest=img3 eager=true fetchpriority="low" %}
</p>
 - Key plates are strongly recommended, but not technically required. If you use 3 pin MX keys, the thumb keys tend to fall out if you don't use a key plate.
 - Plates can be made from acrylic, or 3d printed.
 - The 3d printed or acrylic key plates combined with a backplate make a nice 'sandwich' case. 
 - You can cover up the sandwich case with the 3d printed 'monobody' cover.
 - Spacers are intended to pass through the main pcb and screw onto the bottom plates, top plates, and MCU & Solenoid plates. 
 - Having a standoff kit is helpful when assembling the keyplates. [M2 Brass Standoff Kit](https://www.amazon.com/gp/product/B07B9X1KY6)
 - Acrylic key plates should only be used for MX switches. (The choc switches retention nubs only allow 1.5mm or 1.6mm plates, which aren't recommended with acrylic).

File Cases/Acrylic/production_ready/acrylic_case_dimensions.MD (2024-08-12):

# ErgoDonk Zero Acrylic case

Ordering and assembly instructions can be found [here](https://www.ergodonk.com/cases/acrylic-case).

Plate dimensions for quick reference:

 | Name | Count | Remarks | Potential Storefront |
|-|-|-|-|
| keyplates   | 2 | Use the same file for both sides: `Ergodonk_Zero_v0.2_keyplate.dxf.zip`<br> Dimensions: `217mm x 157mm` |[Elecrow](https://www.elecrow.com/)|
| backplates  | 2 | Use the same file for both sides: `Ergodonk_Zero_v0.2.1_bottom_plate.dxf.zip`<br> Dimensions: `217mm x 157mm` |[Elecrow](https://www.elecrow.com/)|
| Solenoid cover | 2 | Use the same file for both sides: `Ergodonk_Zero_v0.2_Solenoid_cover.dxf.zip`<br> Dimensions: `55mm x 25mm` |[Elecrow](https://www.elecrow.com/)|
| Left Hand MCU cover | 1 | Left hand only: `Ergodonk_Zero_v0.2_LH_MCU_Cover.dxf.zip`<br> Dimensions: `78mm x 97mm` |[Elecrow](https://www.elecrow.com/)|
|Right Hand MCU cover | 1 | Right hand only: `Ergodonk_Zero_v0.2_RH_MCU_Cover.dxf.zip`<br> Dimensions: `78mm x 40mm` |[Elecrow](https://www.elecrow.com/)|

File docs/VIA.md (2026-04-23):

---
layout: page
title: VIA Keymap Configuration
description: How to configure ErgoDonk Zero keymaps using VIA. Covers loading the custom JSON definition, authorizing your device, and remapping keys without reflashing firmware.
permalink: via
nav_order: 5
image: /images/VIA/via_3-878w.webp
# Structured data: renders _includes/structured_data/via_howto.html into <head> via _includes/head_custom.html.
# Remove or rename this key to disable.
schema: via-howto
---

{% assign img1 = site.data.image_manifest["images/VIA/via_1.png"] %}
{% assign img2 = site.data.image_manifest["images/VIA/via_2.png"] %}
{% assign img3 = site.data.image_manifest["images/VIA/via_3.png"] %}
{% assign img4 = site.data.image_manifest["images/VIA/via_4.png"] %}

# VIA

Until the ErgoDonk Zero layout is merged into the official VIA repo, you'll need to load the VIA definition manually.

{: .warning}

> Editing with VIA will only work after you've flashed the ErgoDonk Zero at least once. See [flashing](flashing.md) for first flash instructions.

<ol markdown="1">
<li markdown="1">
Visit https://usevia.app/
</li>
<li markdown="1">
Open the "Settings" tab by clicking on the gear icon at the top of the page.
</li>
<li markdown="1">
Enable "Show Design tab".
<figure>
{% include img_srcset.html src="images/VIA/via_1.png" alt="VIA show design tab switch" eager=true fetchpriority="high" manifest=img1 %}
</figure>
</li>
<li markdown="1">
Now you should see a paintbrush icon at the top of the screen. Click on that to open the "Design tab".
</li>
<li markdown="1">
Download the ErgoDonk Zero via config file: [ergodonk_zero.json](https://raw.githubusercontent.com/JellyTitan/ErgoDonk-Zero/main/Firmware/via/ergodonk_zero.json). (Right click and 'Save As' to download the .json file).<br>
Once you have the file locally, Click "Load" to upload `ergodonk_zero.json`.<br> (The ErgoDonk Zero PR for VIA can't be submitted until the QMK PR is submitted and approved. That PR is waiting and ready to go: [VIA PR for ErgoDonk Zero](https://github.com/JellyTitan/via-keyboards/tree/ergodonk_zero)).
<figure>
{% include img_srcset.html src="images/VIA/via_2.png" alt="VIA uploading config" eager=true fetchpriority="high" manifest=img2 %}
</figure>
</li>
<li markdown="1">
After the definition is loaded, you may be asked to authorize a connection to your device. If the auth request doesn't pop up automatically, click on the 'configure' icon at the top of the page, then click on 'Authorize Device +'.
<figure>
{% include img_srcset.html src="images/VIA/via_3.png" alt="VIA device authorization" manifest=img3 %}
</figure>
</li>
<li markdown="1">
Clicking on the "Configure" tab will let you modify your layout.
<figure>
{% include img_srcset.html src="images/VIA/via_4.png" alt="VIA Configure tab" manifest=img4 %}
</figure>
</li>
</ol>

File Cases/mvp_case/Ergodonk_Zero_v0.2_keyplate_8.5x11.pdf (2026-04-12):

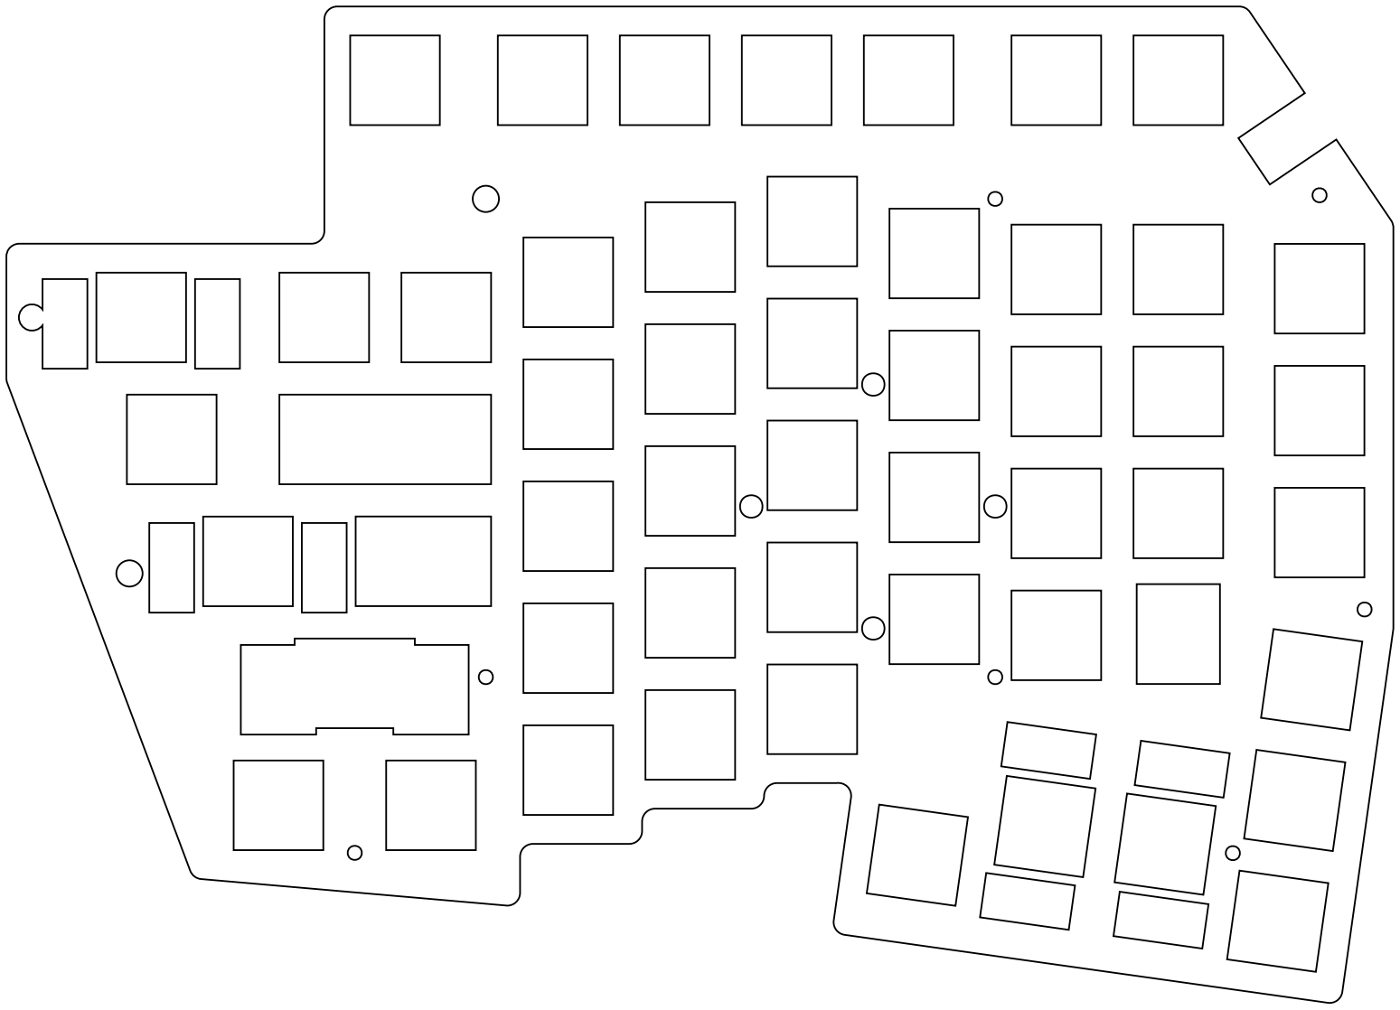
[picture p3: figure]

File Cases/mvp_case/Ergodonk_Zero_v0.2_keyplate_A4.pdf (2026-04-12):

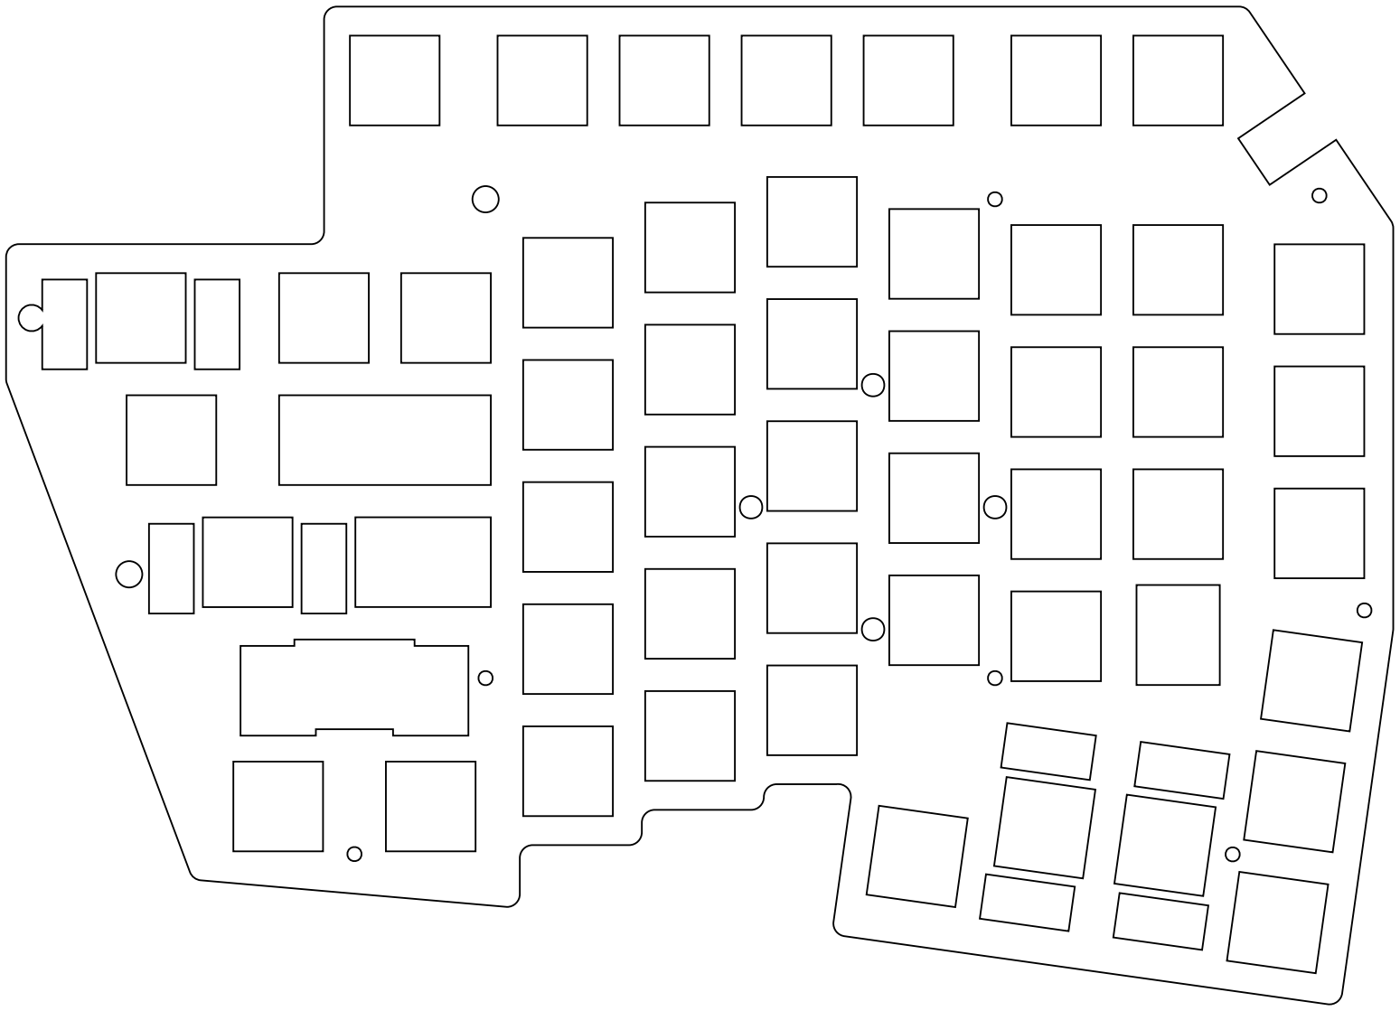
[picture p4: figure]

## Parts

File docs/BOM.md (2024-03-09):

---
layout: page
title: BOM
description: Bill of Materials and sourcing notes
# parent: Build
nav_order: 3
---

## Bill of materials (BOM)

### Required Parts

| Name | Count | Remarks | Potential Storefront | Image |
| ---- | ----- | --- | --- | ----- |
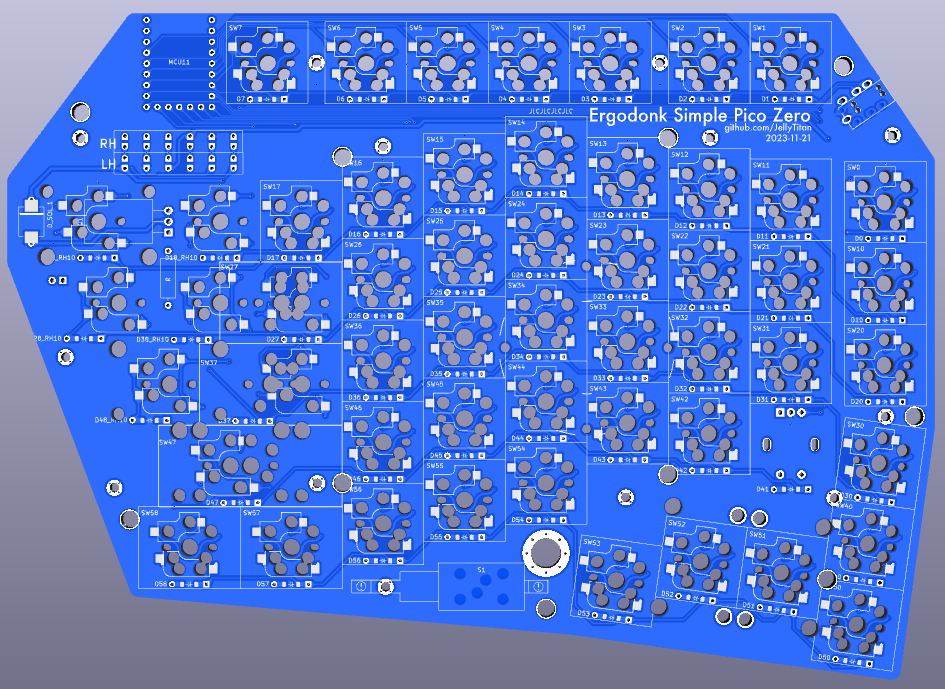
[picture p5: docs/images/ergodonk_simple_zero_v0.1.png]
| PCB | 2 | The PCB should be 1.6mm thick. I used JLCPCB's default settings only customizing the PCB color, and selecting 'lead free'. | Manufacturers such as JLCPCB, PCBWay, and Elecrow. [Price comparison tool](https://pcbshopper.com/) |  |
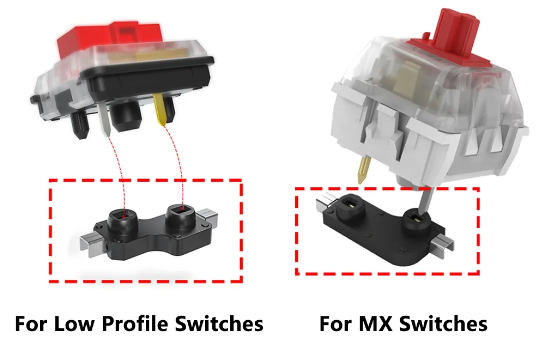
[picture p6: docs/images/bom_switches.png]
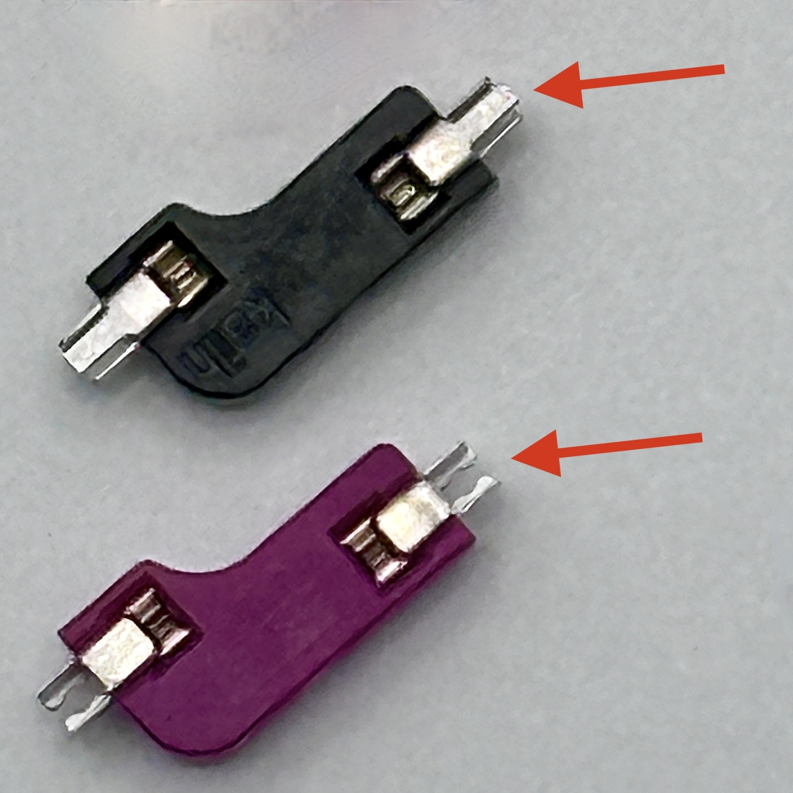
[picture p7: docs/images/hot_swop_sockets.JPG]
troublesome tab on kailh hot swop sockets
| Hot-swap Sockets | 101 | The PCB requires sockets. Switches cannot be soldered directly to the board. <br> Either MX or Choc low profile sockets.  <br> When shopping for MX sockets, try to avoid the variant that has a metal tab in the center of the socket. This makes it harder to get the soldering iron in there. I've only encountered this tab when buying black MX sockets in bulk (500+) from AliExpress. I've _not_ encountered that problem with Kailh & Durock colored sockets. In the image to the right, the black socket has the troublesome tab. | [Amazon MX]( https://www.amazon.com/DUROCK-Mechanical-Keyboard-Switches-Hot-Swap/dp/B0B4WCKWLZ/ )  <br> [Aliexpress MX & Choc](https://www.aliexpress.us/item/3256803687338432.html) |  <br>  |
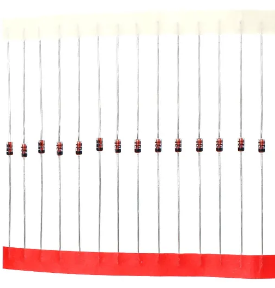
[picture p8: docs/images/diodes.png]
| Diodes | 103 | Surface mount SOD-123 1N4148, or through-hole 1N4148 diode. These are common, any old one should do. Through hole is usually easier to solder. | SMD:  <br> [AliExpress](https://www.aliexpress.us/item/2251832663565152.html) <br> [JLCPCB](https://jlcpcb.com/partdetail/3368026-1N4148SOD123/C2972760) <br> Through-hole: [AliExpress](https://www.aliexpress.us/item/2251832473773777.html) <br> [Amazon](https://www.amazon.com/100-Pieces-1N4148-Switching-High-Speed/dp/B079KJ91JZ) |  |
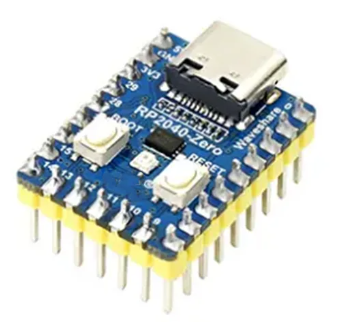
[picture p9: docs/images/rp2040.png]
| Raspberry Pi Zero | 2 | There's tons of clones available. Getting the version with the header pins pre-soldered saves you some time, but the pins are long so you'll have to nip off the excess and the pins may bend during shipping. Consider getting the versions without the soldered pins, and using [low profile header pins](#optional---low-profile-header-pins) instead of the header pins it comes with. | [Amazon](https://www.amazon.com/RP2040-Zero-High-Performance-Microcontroller-Castellated-Boards-2pcs/dp/B0B2Z3YWB9/) <br> [AliExpress](https://www.aliexpress.us/item/3256805808673201.html) |  
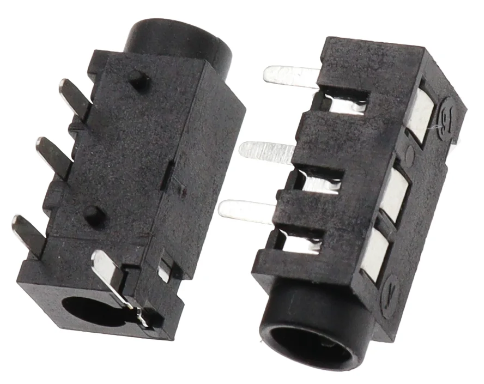
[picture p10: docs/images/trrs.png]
| TRRS Jacks | 2 | PJ-320A | [AliExpress](https://www.aliexpress.us/item/2255800474897706.html) |   |
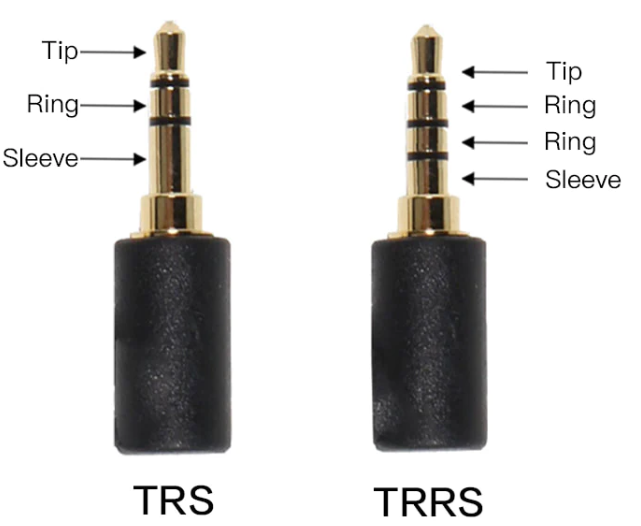
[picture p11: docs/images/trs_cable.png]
| TRRS or TRS (3.5mm "Headphone" Cable) | 1 | Either TRRS "4 pole" or TRS "3 pole" will work. These are often referred to as 3.5mm audio cables, or 'aux' cables.  | [Aliexpress](https://www.aliexpress.us/item/3256804197001011.html) <br> [Amazon](https://www.amazon.com/gp/product/B072TYSV61)|   | 
| MX Style Switches or Choc V1 low profile switches. | 101 | For MX switches, 3-pin or 5-pin will work. For the Choc low profile switches, only V1 is supported.| |
| Key Caps | 101 | Look for keycap sets for "[100% full size](https://thegamingsetup.com/wp-content/uploads/Keyboard-Size-Guide-The-Gaming-Setup-scaled.webp)" keyboards. <br> <br> **Choc V1 Switches**: Choc Switches don't have many keycap options available. <br> <br> **MX swtiches**: The ErgoDonk Zero was designed with the SA [keycap profile](https://www.reddit.com/media?url=https%3A%2F%2Fi.redd.it%2Fkld2wynulsq51.png) in mind. The default switch layout on the PCB makes use of the different SA row heights. If you intend to move the keys about, XDA profile is recommended.  | [Choc V1 AliExpress](https://www.aliexpress.us/item/2251832794671800.html) <br> [MX 'SA' AliExpress](https://www.aliexpress.us/item/3256805853319024.html) <br> [MX SA Amazon](https://www.amazon.com/Ducky-Doubleshot-Keyboards-Compatible-Standard/dp/B08WXBVQ4W/?th=1) <br> [MX XDA AliExpress](https://www.aliexpress.us/w/wholesale-xda-keycaps.html)|
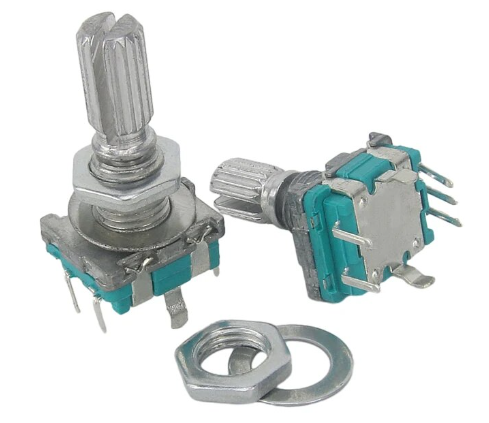
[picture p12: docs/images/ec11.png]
| Rotary Encoders and Caps | 2 | EC-11 Rotary Encoder. 20mm stem is the most common, and a 6mm shaft is standard. Either "D" shaft or round shaft will work. If you're partial to fancy knobs, you should pick a shaft that matches your knob. 6mm shafts are used for guitar knobs, so you've got plenty of options. SA Profile keycaps can be quite tall, so you may want to use tall knobs as well. Some EC11's include a washer and nut, but you won't be using either the washer or nut. | [Amazon](https://www.amazon.com/gp/product/B07D3DF8TK) <br> [AliExpress 20mm](https://www.aliexpress.us/item/3256802171959870.html) |   |
| M2 8mm FF spacers @todo - these heights & qty are outdated. | 12 | Connects the bottom plate to the key plate, running through the PCB | |
| M2 12mm FF spacers | 6 | Connects the bottom plate to the OLED plate, running through the PCB and the keyplate. @todo - is it really 12mm? | |
| M2x5mm screws | 52 | M2 screws. | |
| Case | 1 Left Set, 1 Right Set | Case files are located in the [case folder](./Case). | @todo - regenerate after next prototype validated |
| USB-C Cable | 1 | USB cable for connecting the keyboard to your computer. | | 

<hr>

### Optional - PCB screw in Stabilizers 
Supports up to 8 PCB mounted screw in stabilizers that are 2u in length. Stabilizers often come in sets based on keyboard sizes. A full size 104 key set will usually have 7 2u bars. Note, "PCB mount stabilizers" are not the same as "plate mount stabilizers". Stabilizers can rattle. [There's plenty of mods to 'tune' the stabilizers](https://www.youtube.com/watch?v=4XCErBcn5lc) - but I've given up fighting the rattle and just skip them. YMMV. 

<hr>

### Optional - Solenoid
The solenoid attaches to the PCB below the left palm. It's lovely and loud. Will only work on the left hand.
Based on this [diagram by Adafruit](https://cdn-shop.adafruit.com/product-files/412/solenoid_driver.pdf). 
[QMK Docs for solenoid.](https://docs.qmk.fm/#/feature_haptic_feedback?id=solenoids) 
| Name | Count | Remarks | Potential Storefront |
| - | - |-|-|
| Solenoid | 1 | 4.5v Solenoid - the Amazon Uxcell solenoid is the most reliable one I've found.<br>Some [3V Solenoids](https://www.aliexpress.us/item/3256802092636163.html) from AliExpress will work - but the 'thunk' is not nearly as satisfying. Go with the 4.5v if you can. | [Amazon](https://www.amazon.com/dp/B013DR655A)<br> [AliExpress](https://www.aliexpress.us/item/3256805711149774.html)
 1k Resistor | 1 |   A 2.2k resistor should work as well, but I've not tried it.| [Amazon](https://www.amazon.com/gp/product/B08FHPKF9V)<br>[Aliexpress](https://www.aliexpress.us/item/3256805483572082.html) |
 1N4001 Diode | 1 |  | [Amazon](https://www.amazon.com/gp/product/B079JPMW9H), [AliExpress](https://www.aliexpress.us/item/3256802685977811.html)|
 TIP 120 | 1 | Heatsinks are available for these, but aren't needed.  | [Amazon](https://www.amazon.com/gp/product/B083TQN12B/), [Aliexpress](https://www.aliexpress.us/item/3256803429634601.html) | 
 | M2 4mm screws | 2 | Attaches the Solenoid to the PCB | @todo use the same source as case screws in teh required section. |

<hr>

### Optional - Case plates
 - Key plates are strongly recommended with 3-pin MX switches, but not technically required. The thumb keys tend to fall out if you don't use a key plate. If you're using choc switches or 5-pin MX switches, they stay put well enough to skip the key plate entirely. Key plates should be made from PCB or 3d printed. Acrylic is not recommended becasue the ErgoDonk is so large the acrylic can flex, making it difficult to seat the keys properly. 3d printable keyplates can be found [here]((https://www.printables.com/model/738066-ergodonk-zero-open-back-case)).
 - Bottom plates pair nicely with key plates and can be connected with M2 standoff posts. These are not strictly necessary, as you could use [adhesive rubber bumpers](https://www.amazon.com/gp/product/B074C2XKXH) on the underside of the pcb instead. Acrylic, PCB or 3d prints are good for these.
 - The MCU's and the Solenoid are taller than the key plate, so they have their own separate taller plataes cover plates. Acrylic, PCB or 3d prints are good for these.
 - The left MCU cover plate is different from the right MCU cover plate, because the left MCU cover plate also hides empty keyholes. 
 @todo add images here.
 - Spacers are intended to pass through the main pcb and screw onto the bottom plates, key plates, and MCU cover plates.

### Optional - 3d printed case
This [3d printable ErgoDonk Zero case](https://www.printables.com/model/738066-ergodonk-zero-open-back-case) includes a key plate and a "monobody" case that covers the front of the board and screws onto the back. The Solenoid acoustics on this case are not great. YMMV.<br>
ErgoDonk Zero Monobody case hero shot<br>
ErgoDonk Zero 3d printable monobody case back side ErgoDonk Zero 3d printable key plate ErgoDonk Zero 3d printable monobody case
<hr>

### Optional - low profile header pins
- The header pins that come with the Zero are usually too long. You can either clip them off after soldering, or use [8.5mm low profile header pins ](https://www.aliexpress.us/item/3256805874707460.html) instead.

low profile header pins

<hr>

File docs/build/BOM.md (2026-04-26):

---
layout: page
title: Bill of Materials
description: "Complete bill of materials for the ErgoDonk Zero keyboard. Sourcing notes, quantities, and links for switches, hotswap sockets, diodes, MCU, solenoid, and more."
parent: Build
permalink: build/bom
nav_order: 1
schema: bom-howto
---

{% assign img1 = site.data.image_manifest["images/ergodonk_zero_3d_printable_case.jpeg"] %}
{% assign img2 = site.data.image_manifest["images/ergodonk_zero_3d_printable_case_backside.jpeg"] %}
{% assign img3 = site.data.image_manifest["images/ergodonk_zero_keyplate.jpeg"] %}
{% assign img4 = site.data.image_manifest["images/ergodonk_monobody_case.jpeg"] %}
{% assign img5 = site.data.image_manifest["images/sofle_pico_luxury_pins.png"] %}
{% comment %}
  Tables on this page use static HTML instead of markdown pipe syntax because
  kramdown does not process Liquid includes ({% include %}) inside markdown table cells.

  When multiple images appear together in a single <td>, they must be wrapped in a <p>
  tag. The slider lightbox identifies image groups by their shared parent element —
  without the wrapper, left/right navigation between adjacent images will not work.
{% endcomment %}
{% assign img6 = site.data.image_manifest["images/ergodonk_simple_zero_v0.1.png"] %}
{% assign img7 = site.data.image_manifest["images/bom_switches.png"] %}
{% assign img8 = site.data.image_manifest["images/hot_swop_sockets.JPG"] %}
{% assign img9 = site.data.image_manifest["images/diodes.png"] %}
{% assign img10 = site.data.image_manifest["images/rp2040.png"] %}
{% assign img11 = site.data.image_manifest["images/trrs.png"] %}
{% assign img12 = site.data.image_manifest["images/trs_cable.png"] %}
{% assign img13 = site.data.image_manifest["images/ec11.png"] %}
{% assign img14 = site.data.image_manifest["images/ec11_knob.png"] %}

# Bill of materials (BOM)
{: .no_toc }

## Table of contents
{: .no_toc .text-delta }

1. TOC
{:toc}

## Required Parts

<table>
  <thead>
    <tr>
      <th scope="col">Name</th>
      <th scope="col">Count</th>
      <th scope="col">Remarks</th>
      <th scope="col">Potential Storefront</th>
      <th scope="col">Image</th>
    </tr>
  </thead>
  <tbody>
    <tr>
      <td>PCB</td>
      <td>2</td>
      <td>The PCB should be 1.6mm thick. I used JLCPCB's default settings, only customizing the PCB color, and selecting 'lead free'.</td>
      <td>Manufacturers such as JLCPCB, PCBWay, and Elecrow. <a href="https://pcbshopper.com/">Price comparison tool</a></td>
      <td>
        {% include slider_img_srcset_thumb.html
            src="images/ergodonk_simple_zero_v0.1.png"
            alt="Ergodonk Zero PCB 3d rendering"
            manifest=img6
        %}
      </td>
    </tr>
    <tr>
      <td>Hot-swap Sockets</td>
      <td>101</td>
      <td>The PCB requires sockets. Switches cannot be soldered directly to the board. <br> Either MX or Choc low profile sockets. <br> When shopping for MX sockets, try to avoid the variant that has a metal tab in the center of the socket. This makes it harder to get the soldering iron in there. I've only encountered this tab when buying black MX sockets in bulk (500+) from AliExpress. I've <em>not</em> encountered that problem with Kailh &amp; Durock colored sockets. In the image to the right, the black socket has the troublesome tab.</td>
      <td><a href="https://www.amazon.com/DUROCK-Mechanical-Keyboard-Switches-Hot-Swap/dp/B0B4WCKWLZ/">Amazon MX</a> <br> <a href="https://www.aliexpress.us/item/3256803687338432.html">Aliexpress MX &amp; Choc</a></td>
      <td>
        <p>
          {% include slider_img_srcset_thumb.html
              src="images/bom_switches.png"
              alt="Choc and MX switches with their respective sockets"
              manifest=img7
          %}
          {% include slider_img_srcset_thumb.html
              src="images/hot_swop_sockets.JPG"
              alt="troublesome tab on kailh hot swap sockets"
              manifest=img8
          %}
        </p>
      </td>
    </tr>
    <tr>
      <td>Diodes</td>
      <td>103</td>
      <td>Surface mount SOD-123 1N4148, or through-hole 1N4148 diode. These are common; any old one should do. Through hole is usually easier to solder.</td>
      <td>SMD: <br> <a href="https://www.aliexpress.us/item/2251832663565152.html">AliExpress</a> <br> <a href="https://jlcpcb.com/partdetail/3368026-1N4148SOD123/C2972760">JLCPCB</a> <br> Through-hole: <a href="https://www.aliexpress.us/item/2251832473773777.html">AliExpress</a> <br> <a href="https://www.amazon.com/100-Pieces-1N4148-Switching-High-Speed/dp/B079KJ91JZ">Amazon</a></td>
      <td>
        {% include slider_img_srcset_thumb.html
            src="images/diodes.png"
            alt="through hole diodes"
            manifest=img9
        %}
      </td>
    </tr>
    <tr>
      <td>RP2040 Zero</td>
      <td>2</td>
      <td>There are tons of clones available. Getting the version with the header pins pre-soldered saves you some time, but the pins are long, so you'll have to nip off the excess and the pins may bend during shipping. Consider getting the versions without the soldered pins, and using <a href="#optional---low-profile-header-pins">low profile header pins</a> instead of the header pins it comes with.</td>
      <td><a href="https://www.amazon.com/RP2040-Zero-High-Performance-Microcontroller-Castellated-Boards-2pcs/dp/B0B2Z3YWB9/">Amazon</a> <br> <a href="https://www.aliexpress.us/item/3256805808673201.html">AliExpress</a></td>
      <td>
        {% include slider_img_srcset_thumb.html
            src="images/rp2040.png"
            alt="RP2040 Zero Microcontroller"
            manifest=img10
        %}
      </td>
    </tr>
    <tr>
      <td>TRRS Jacks</td>
      <td>2</td>
      <td>PJ-320A</td>
      <td><a href="https://www.aliexpress.us/item/2255800474897706.html">AliExpress</a></td>
      <td>
        {% include slider_img_srcset_thumb.html
            src="images/trrs.png"
            alt="TRRS jacks"
            manifest=img11
        %}
      </td>
    </tr>
    <tr>
      <td>TRRS or TRS (3.5mm "Headphone" Cable)</td>
      <td>1</td>
      <td>Either TRRS "4 pole" or TRS "3 pole" will work. These are often referred to as 3.5mm audio cables, or 'aux' cables.</td>
      <td><a href="https://www.aliexpress.us/item/3256804197001011.html">Aliexpress</a> <br> <a href="https://www.amazon.com/gp/product/B072TYSV61">Amazon</a></td>
      <td>
        {% include slider_img_srcset_thumb.html
            src="images/trs_cable.png"
            alt="Tip ring sleeve (TRS) cable"
            manifest=img12
        %}
      </td>
    </tr>
    <tr>
      <td>MX Style Switches or Choc V1 low profile switches.</td>
      <td>101</td>
      <td>For MX switches, 3-pin or 5-pin will work. For the Choc low profile switches, only V1 is supported.</td>
      <td></td>
      <td></td>
    </tr>
    <tr>
      <td>Key Caps</td>
      <td>101</td>
      <td>Look for keycap sets for "<a href="https://thegamingsetup.com/wp-content/uploads/Keyboard-Size-Guide-The-Gaming-Setup-scaled.webp">100% full size</a>" keyboards. <br><br> <strong>Choc V1 Switches</strong>: Choc Switches don't have many keycap options available. <br><br> <strong>MX switches</strong>: The ErgoDonk Zero was designed with the SA <a href="https://www.reddit.com/media?url=https%3A%2F%2Fi.redd.it%2Fkld2wynulsq51.png">keycap profile</a> in mind. The default switch layout on the PCB makes use of the different SA row heights. If you intend to move the keys about, XDA profile is recommended.</td>
      <td><a href="https://www.aliexpress.us/item/2251832794671800.html">Choc V1 AliExpress</a> <br> <a href="https://www.aliexpress.us/item/3256805853319024.html">MX 'SA' AliExpress</a> <br> <a href="https://www.amazon.com/Ducky-Doubleshot-Keyboards-Compatible-Standard/dp/B08WXBVQ4W/?th=1">MX SA Amazon</a> <br> <a href="https://www.aliexpress.us/w/wholesale-xda-keycaps.html">MX XDA AliExpress</a></td>
      <td></td>
    </tr>
    <tr>
      <td>Rotary Encoders and Caps</td>
      <td>2</td>
      <td>EC-11 Rotary Encoder. The 20mm stem is the most common, and a 6mm shaft is standard. Either "D" shaft or round shaft will work. If you're partial to fancy knobs, you should pick a shaft that matches your knob. 6mm shafts are used for guitar knobs, so you've got plenty of options. SA Profile keycaps can be quite tall, so you may want to use tall knobs as well. Some EC11s include a washer and nut, but you won't be using either the washer or nut.</td>
      <td><a href="https://www.amazon.com/gp/product/B07D3DF8TK">Amazon</a> <br> <a href="https://www.aliexpress.us/item/3256802171959870.html">AliExpress 20mm</a></td>
      <td>
        <p>
          {% include slider_img_srcset_thumb.html
              src="images/ec11.png"
              alt="ec11 rotary encoder"
              manifest=img13
          %}
          {% include slider_img_srcset_thumb.html
              src="images/ec11_knob.png"
              alt="ec11 rotary encoder knob"
              manifest=img14
          %}
        </p>
      </td>
    </tr>
    <tr>
      <td>USB-C Cable</td>
      <td>1</td>
      <td>USB cable for connecting the keyboard to your computer.</td>
      <td></td>
      <td></td>
    </tr>
  </tbody>
</table>

<hr>

## Optional parts

### Optional - PCB screw in Stabilizers 
Supports up to 8 PCB mounted screw-in stabilizers that are 2u in length. Stabilizers often come in sets based on keyboard sizes. A full-size, 104-key set will usually have 7 2u bars. Note: "PCB mount stabilizers" are not the same as "plate mount stabilizers". Stabilizers can rattle. [There are plenty of mods to 'tune' the stabilizers](https://www.youtube.com/watch?v=4XCErBcn5lc) - but I've given up fighting the rattle and just skip them. YMMV. 

<hr>

### Optional - Solenoid
The solenoid attaches to the PCB below the left palm. It's lovely and loud. Will only work on the left hand.
Based on this [diagram by Adafruit](https://cdn-shop.adafruit.com/product-files/412/solenoid_driver.pdf). 
[QMK Docs for solenoid.](https://docs.qmk.fm/#/feature_haptic_feedback?id=solenoids) 

<table>
  <thead>
    <tr>
      <th scope="col">Name</th>
      <th scope="col">Count</th>
      <th scope="col">Remarks</th>
      <th scope="col">Potential Storefront</th>
    </tr>
  </thead>
  <tbody>
    <tr>
      <td>Solenoid</td>
      <td>1</td>
      <td>4.5v Solenoid - the Amazon Uxcell solenoid is the most reliable one I've found.<br>Some <a href="https://www.aliexpress.us/item/3256802092636163.html">3V Solenoids</a> from AliExpress will work - but the 'thunk' is not nearly as satisfying. Go with the 4.5v if you can.</td>
      <td><a href="https://www.amazon.com/dp/B013DR655A">Amazon</a><br> <a href="https://www.aliexpress.us/item/3256805711149774.html">AliExpress</a></td>
    </tr>
    <tr>
      <td>1k Resistor</td>
      <td>1</td>
      <td>A 2.2k resistor should work as well, but I've not tried it.</td>
      <td><a href="https://www.amazon.com/gp/product/B08FHPKF9V">Amazon</a><br><a href="https://www.aliexpress.us/item/3256805483572082.html">Aliexpress</a></td>
    </tr>
    <tr>
      <td>1N4001 Diode</td>
      <td>1</td>
      <td></td>
      <td><a href="https://www.amazon.com/gp/product/B079JPMW9H">Amazon</a>, <a href="https://www.aliexpress.us/item/3256802685977811.html">AliExpress</a></td>
    </tr>
    <tr>
      <td>TIP 120</td>
      <td>1</td>
      <td>Heatsinks are available for these, but aren't needed.</td>
      <td><a href="https://www.amazon.com/gp/product/B083TQN12B/">Amazon</a>, <a href="https://www.aliexpress.us/item/3256803429634601.html">Aliexpress</a></td>
    </tr>
    <tr>
      <td>M2 4mm screws</td>
      <td>2</td>
      <td>Attaches the Solenoid to the PCB</td>
      <td></td>
    </tr>
  </tbody>
</table>

<hr>

### Optional - Case plates
 - Key plates are strongly recommended with 3-pin MX switches, but not technically required. The thumb keys tend to fall out if you don't use a key plate. If you're using choc switches or 5-pin MX switches, they stay put well enough to skip the key plate entirely. Key plates should be made from PCB or 3d printed. Acrylic is not recommended because the ErgoDonk is so large, the acrylic can flex, making it difficult to seat the keys properly. 3d printable keyplates can be found on [Printables](https://www.printables.com/model/738066-ergodonk-zero-open-back-case).
 - Bottom plates pair nicely with key plates and can be connected with M2 standoff posts. These are not strictly necessary, as you could use [adhesive rubber bumpers](https://www.amazon.com/gp/product/B074C2XKXH) on the underside of the PCB instead. Acrylic, PCB or 3d prints are good for these.
 - The MCUs and the solenoid are taller than the key plate, so they have their own separate taller cover plates. Acrylic, PCB or 3d prints are good for these.
 - The left MCU cover plate is different from the right MCU cover plate, because the left MCU cover plate also hides empty keyholes. 
 {% comment %}
 @todo add images here.
 {% endcomment %}
 - Spacers are intended to pass through the main pcb and screw onto the bottom plates, key plates, and MCU cover plates.

### Optional - 3d printed case
This [3d printable ErgoDonk Zero case](https://www.printables.com/model/738066-ergodonk-zero-open-back-case) includes a key plate and a "monobody" case that covers the front of the board and screws onto the back. The solenoid acoustics on this case are not great. YMMV.
<p>
{% include slider_img_srcset.html src="images/ergodonk_zero_3d_printable_case.jpeg" alt="ErgoDonk Zero Monobody case hero shot" manifest=img1 %}
</p>
<p class="image-grid-3">
    {% include slider_img_srcset.html 
        src="images/ergodonk_zero_3d_printable_case_backside.jpeg" 
        alt="ErgoDonk Zero 3d printable monobody case back side" 
        manifest=img2
    %}
    {% include slider_img_srcset.html 
        src="images/ergodonk_zero_keyplate.jpeg" 
        alt="ErgoDonk Zero 3d printed 'thickaronie' keyplate" 
        manifest=img3
    %}
    {% include slider_img_srcset.html 
        src="images/ergodonk_monobody_case.jpeg" 
        alt="ErgoDonk Zero 3d printable monobody case" 
        manifest=img4
    %}
</p>

### Optional - low profile header pins
- The header pins that come with the Zero are usually too long. You can either clip them off after soldering, clip them flush before soldering, or use [8.5mm low profile header pins ](https://www.aliexpress.us/item/3256805874707460.html) instead.

<figure>
{% include img_srcset.html src="images/sofle_pico_luxury_pins.png" alt="low profile header pins" manifest=img5 %}
<figcaption>Optional low-profile header pins.</figcaption>
</figure>

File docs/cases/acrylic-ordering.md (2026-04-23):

---
layout: page
title: Acrylic Case Ordering Guide
description: How to order the ErgoDonk Zero acrylic case from Elecrow. Step-by-step guide with DXF downloads, dimensions for each plate, pricing notes, and quantity recommendations.
parent: Case Options
permalink: /cases/acrylic-ordering-guide
nav_order: 2
# published: false
# Structured data: renders _includes/structured_data/acrylic_ordering_howto.html into <head> via _includes/head_custom.html.
# Remove or rename this key to disable.
schema: acrylic-ordering-howto
---

# Acrylic case ordering guide

How to order a custom cut acrylic case from a vendor. This is helpful info if it's your first time ordering a laser cut acrylic. Keep in mind, nobody can guarantee that there are not going to be some problems. If this is your first time, it might be more difficult to deal with any issues along the way.

Most custom fabrication vendors have a similar ordering process. For acrylic I use [Elecrow](https://www.elecrow.com/acrylic-cutting.html) because they are usually the most cost effective. The minimum order quantity (MOQ) is 5 pieces. Pricing is based on dimensions. Some vendors will auto-detect the dimensions when you upload a file for production, and some don't. Anything under 100x100mm is often eligible for 'promotional pricing'. This _should_ apply to the MCU covers. Some acrylic colors cost more than others. 
As of July 2024, it was ~$65 total to get 1 MOQ (5) of each plate. (That's 2.5 ErgoDonk Zero sets). That breaks down to about $5 each for the 2 MCU covers, $5 for the Solenoid covers, and $50 for the key plate and the back plate, all in 3mm transparent acrylic.

| Case part | Width | Height| Download |
| ----:  |  :----:  |  :----: | :-----  |
|Key plate |217mm |157mm | [Ergodonk_Zero_v0.2_keyplate.dxf.zip](https://github.com/JellyTitan/ErgoDonk-Zero/blob/main/Cases/Acrylic/production_ready/Ergodonk_Zero_v0.2_keyplate.dxf.zip) |
|Back plate |217mm |157mm |[Ergodonk_Zero_v0.2.1_bottom_plate.dxf.zip](https://github.com/JellyTitan/ErgoDonk-Zero/blob/main/Cases/Acrylic/production_ready/Ergodonk_Zero_v0.2.1_bottom_plate.dxf.zip)|
|Solenoid cover |55mm |25mm |[Ergodonk_Zero_v0.2_Solenoid_cover.dxf.zip](https://github.com/JellyTitan/ErgoDonk-Zero/blob/main/Cases/Acrylic/production_ready/Ergodonk_Zero_v0.2_Solenoid_cover.dxf.zip)|
|Left Hand MCU cover |78mm |97mm |[Ergodonk_Zero_v0.2_LH_MCU_Cover.dxf.zip](https://github.com/JellyTitan/ErgoDonk-Zero/blob/main/Cases/Acrylic/production_ready/Ergodonk_Zero_v0.2_LH_MCU_Cover.dxf.zip)|
|Right Hand MCU cover |78mm |40mm |[Ergodonk_Zero_v0.2_RH_MCU_Cover.dxf.zip](https://github.com/JellyTitan/ErgoDonk-Zero/blob/main/Cases/Acrylic/production_ready/Ergodonk_Zero_v0.2_RH_MCU_Cover.dxf.zip)|

<small>*If the download links aren't working, check [the repo](https://github.com/JellyTitan/Sofle-Pico/tree/main/Sofle_Pico/Case/Acrylic_case) for the latest version*</small>

Elecrow requests zipped `.dxf` files and a .`pdf`. You can ignore the request for `pdf`. 

1. Download the acrylic case zipped `.dxf` files from the links above or directly from [the repo](https://github.com/JellyTitan/ErgoDonk-Zero/tree/main/Cases/Acrylic/production_ready).
2. Start at the [elecrow acrylic ordering page](https://www.elecrow.com/acrylic-cutting.html), and upload or drag and drop the `dxf.zip` file. (You'll have to add each plate to the order separately, there is no bulk upload option.)
3. Manually enter the dimensions to update pricing.
4. Adjust quantity, or leave at the default of 5.
5. Select 3mm for the acrylic.
6. The remainder of the checkout process is standard ecommerce stuff. 
   
elecrow acrylic order page

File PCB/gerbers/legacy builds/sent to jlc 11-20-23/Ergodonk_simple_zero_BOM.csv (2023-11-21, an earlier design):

Comment | Designator | Footprint | JLCPCB Part #（optional）
D | D58,D17,D55,D46,D40,D15,D54,D56,D5,D13,D32,D26,D7,D2,D21,D37,D42,D33,D11,D27,D12,D25,D34,D4,D50,D51,D0,D1,D47,D6,D24,D3,D16,D35,D43,D45,D22,D48_RH10,D20,D38_RH10,D14,D31,D44,D52,D36,D41,D28_RH10,D23,D18_RH10,D08_RH10,D30,D10,D57,D53 | D_SOD-123_DO-35_Hybrid_DoubleSided_ergodonk_simple_zero | C2972760

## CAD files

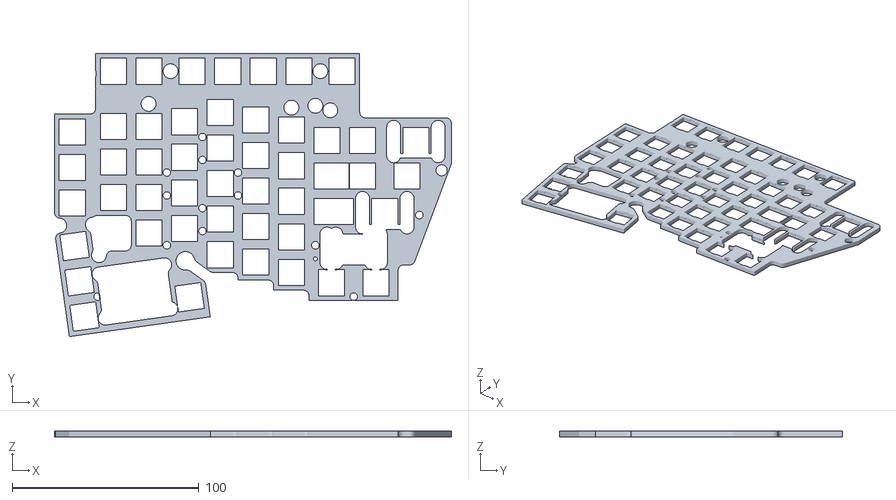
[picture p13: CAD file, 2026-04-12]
Cases/3d_printable_case/Thickaronie_keyplate_LH.stl
212.5 x 151.6 x 3.00

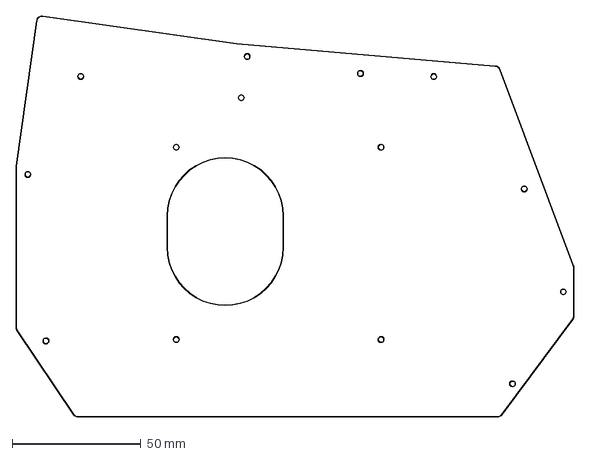
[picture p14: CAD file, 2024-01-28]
Cases/Acrylic/source/Ergodonk_Zero_v0.2.1_bottom_plate.dxf
216.6 x 155.7 mm

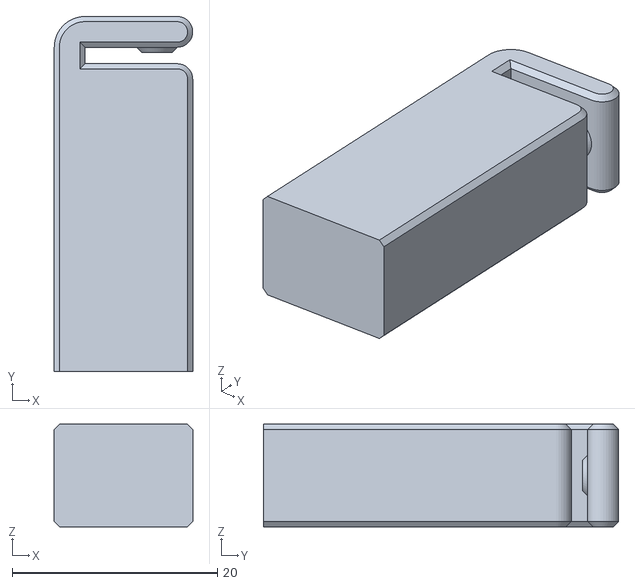
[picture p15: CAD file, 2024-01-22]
workholding_feet/ergodonk_zero_workholding_feet.stl
13.5 x 34.6 x 10.0

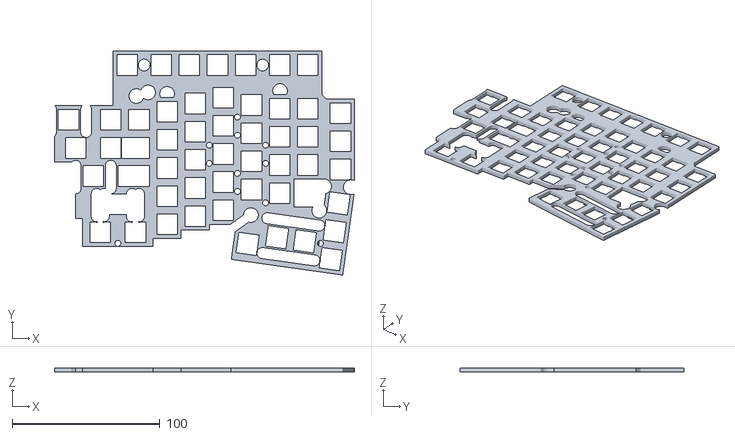
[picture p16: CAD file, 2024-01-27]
Cases/Acrylic/source/Thickaronie_keyplate.stl
203.0 x 151.6 x 3.00

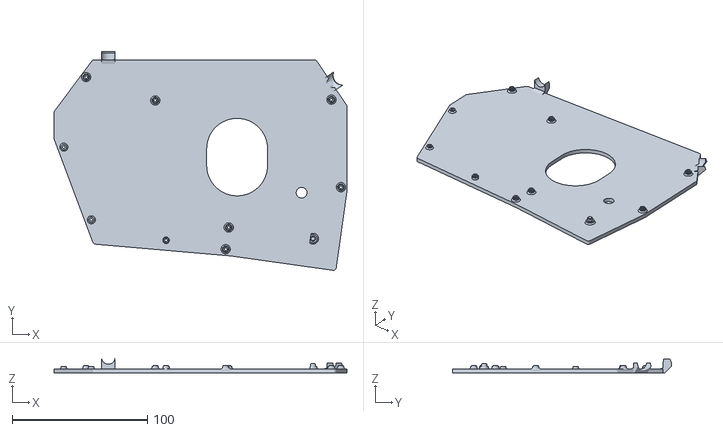
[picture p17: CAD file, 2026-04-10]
Cases/3d_printable_case/lh_bottom_plate.stl
216.5 x 161.6 x 10.6

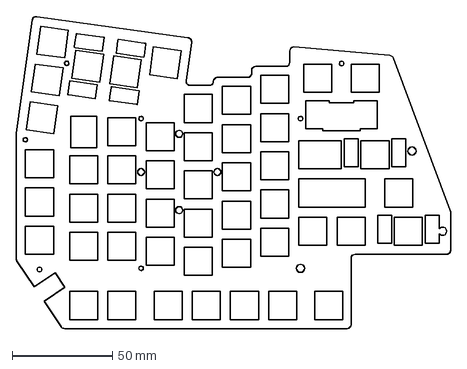
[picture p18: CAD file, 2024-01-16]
Cases/Acrylic/source/Ergodonk_Zero_v0.2_keyplate.dxf
216.5 x 155.7 mm

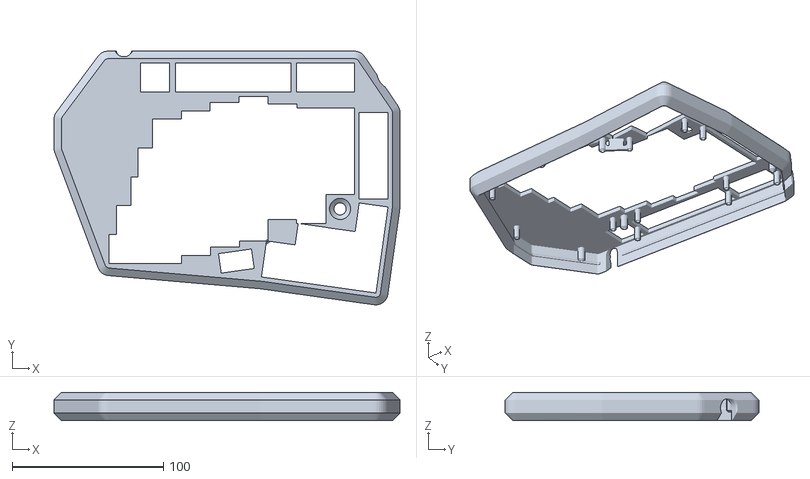
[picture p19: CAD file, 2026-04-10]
Cases/3d_printable_case/lh-ergodonk-monobody.stl
228.5 x 167.6 x 18.6

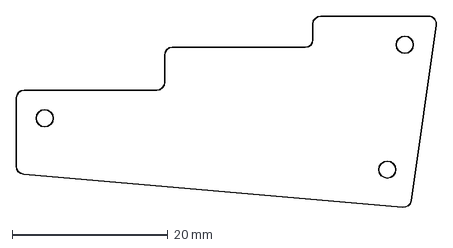
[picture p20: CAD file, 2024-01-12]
Cases/Acrylic/source/Ergodonk_Zero_v0.2_Solenoid_cover.dxf
54.0 x 24.6 mm

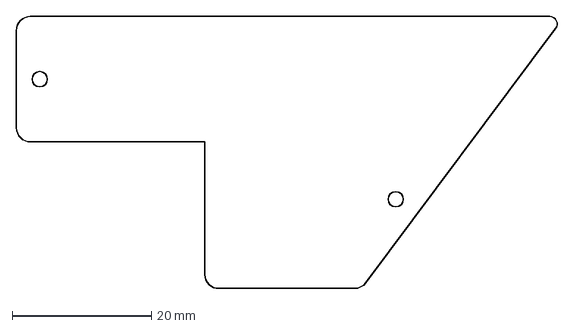
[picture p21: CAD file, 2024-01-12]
Cases/Acrylic/source/Ergodonk_Zero_v0.2_RH_MCU_Cover.dxf
77.7 x 39.1 mm

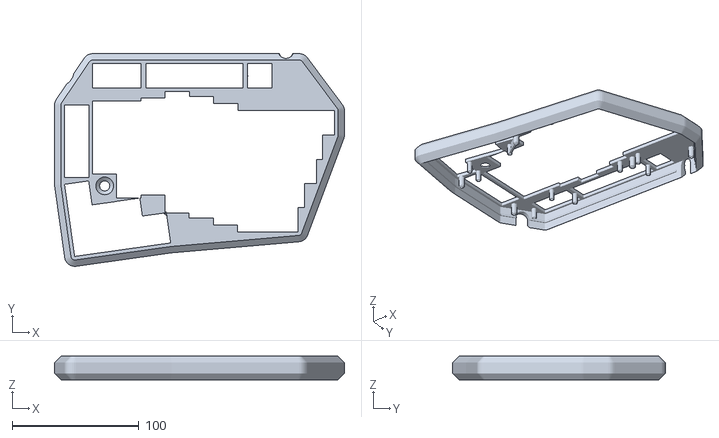
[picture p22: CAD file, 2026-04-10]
Cases/3d_printable_case/rh-ergodonk-monobody.stl
228.5 x 167.6 x 18.6

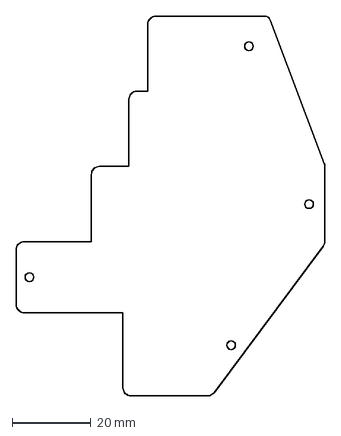
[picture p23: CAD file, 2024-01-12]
Cases/Acrylic/source/Ergodonk_Zero_v0.2_LH_MCU_Cover.dxf
78.2 x 96.2 mm

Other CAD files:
Cases/3d_printable_case/Thickaronie_keyplate_RH.stl
Cases/3d_printable_case/rh_bottom_plate.stl
workholding_feet/ErgoDonk Solering jig v19.f3d

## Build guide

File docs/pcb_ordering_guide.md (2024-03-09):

---
layout: page
title: PCB Ordering
# permalink: /pcb-ordering
description: ErgoDonk Zero PCB ordering guide
# parent: Build
nav_order: 4
---
# PCB Ordering Guide.

How to order this board from a PCB vendor - helpful info if it's your first time ordering a PCB.

Most PCB vendors have a similar ordering process. I use [JLCPCB](https://jlcpcb.com/) because they are usually the most cost effective. I've had good luck with [Elecrow](https://www.elecrow.com/) too. [You can find PCB price comparison tools online.](https://pcbshopper.com/) When comparing pricing, be sure to enter the board dimensions, and set the minimum quantity to 5. The ErgoDonk zero is 217mm X 156mm. Usually anything under 100x100mm is really inexpensive - so be sure to use actual dimensions when pricing. Most manufacturers have a 5 board minimum, so this is a safe quantity to start with.

Usually the minimum quantity to order is 5 boards. The ErgoDonk Zero been designed to be double sided, so a batch of 5 boards gets you 2 & 1/2 sets.

The production files are known as "gerbers", and they are usually uploaded as a `.zip` file. (It's essentially a collection of files for each layer of the board, like holes, graphics, traces etc.) 

The Gerbers for the ErgoDonk Zero can be found as a zipped file in the "Releases" section on the right hand side of the [Github repo](https://github.com/JellyTitan/ErgoDonk-Zero). 

@todo add image and name of release

The homepage of JLCPCB has a drag & drop upload. Drag the gerber `.zip` and drop it on the "add gerber file" box.

JLCPCB Home

While the file is uploading, it will take you to an options screen. Once the board size is detected<sup>1</sup>, the price<sup>2</sup> will update accordingly.
Changing the pcb color<sup>3</sup> may impact production time and price.
Shipping estimates<sup>4</sup> can vary widely, so be sure to check those. (You'll see these options again during checkout).

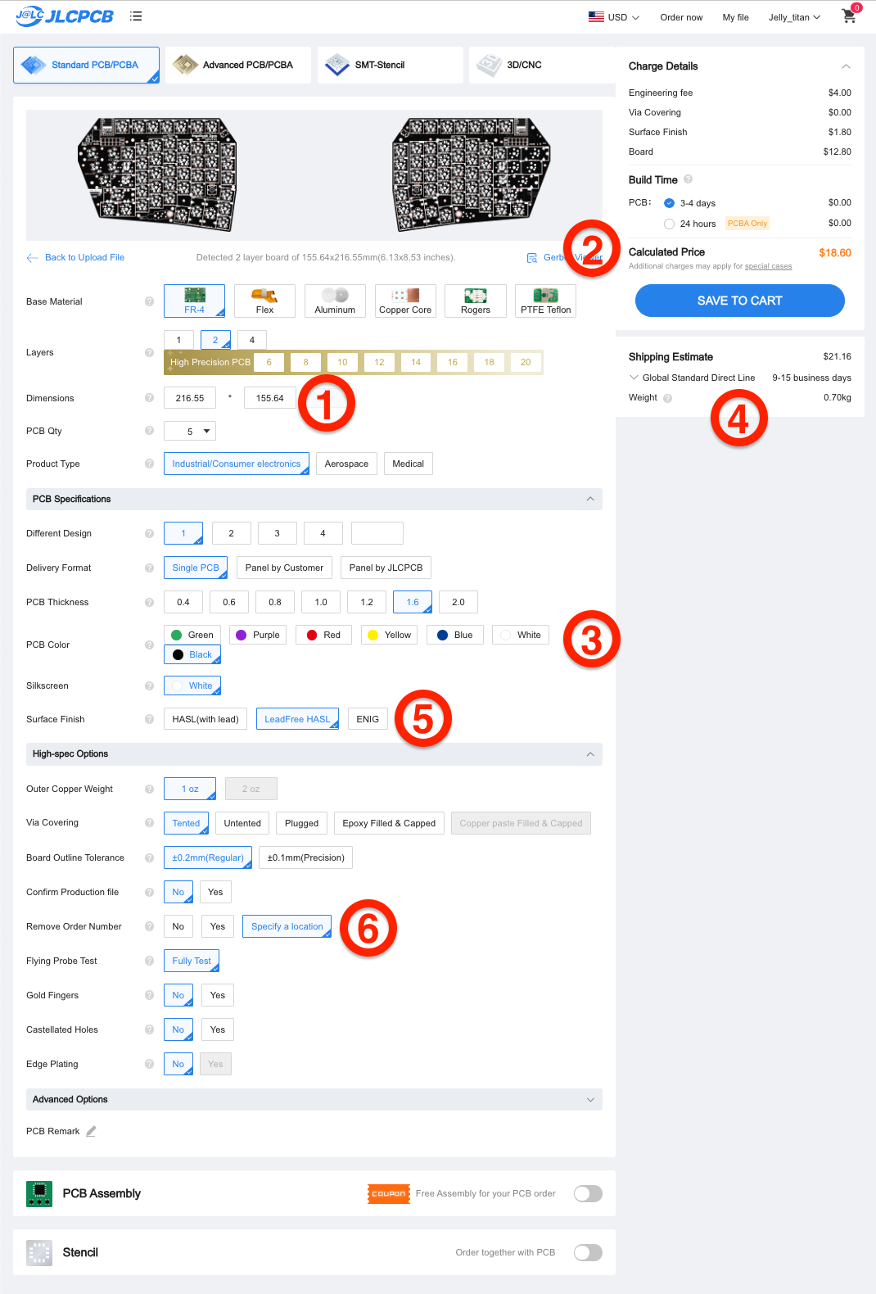
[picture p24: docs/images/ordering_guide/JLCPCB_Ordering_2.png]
JLCPCB Home


It's worth noting, the default pcb surface finish contains Lead. For boards in cases, this is usually not a problem. If you're going to rock a naked board, consider going with "lead free"<sup>5</sup> for a few bucks more. The more popular colors like green and black tend to cost less for the lead free option.

By default, all JLC boards have a part number printed on them. (Most people won't notice them unless your looking for them). You can pay extra to have them removed. ErgoDonk Zero supports the option to "Specify a location"<sup>6</sup>. (Essentially this is a line of text on the PCB that will JLC will substitute with their part number.) There is no additional charge for specifying the location. 

The remainder of the checkout process is standard e-commerce stuff. After you pay for your order, it will be reviewed before going into production. They will let you know if the file has any issues.

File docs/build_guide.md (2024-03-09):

---
layout: page
title: Build Guide
description: ErgoDonk Zero keyboard build guide.
# permalink: /build
parent: Build
nav_order: 5
# image: /images/build_guide_pico/sofle_pico_MCU_heroshot.png
---

## Tools and materials

- soldering iron and solder
- no-clean flux makes soldering easier
- solder wick or desoldering pump to correct mistakes
- good tweezers
- flush cutters to trim diode legs
- masking, kapton or electrical tape
- isopropyl-alcohol for cleaning
- Optional - magnetic 'third hand' PCB work holding fixture. (I'm partial to the little cones) 
- Optional - multimeter for troubleshooting. 
- Optional - [magnifier headband](https://www.amazon.com/Headband-Magnifier-eSynic-Rechargeable-Detachable/dp/B08W55R47Z).

## Build Guide / Assembly steps
This guide includes all optional components. 

There's a few common soldering methods used with through-hole components. In this guide, we'll be using the third method - "work holding". Accordingly, the docs will not reference flipping the PCB over for soldering legs.

1. **The bendy method**: Push the legs through the holes, then bend the legs slightly outward on the bottom side to keep the component in the hole when the PCB is flipped over. Solder on the side of the board opposite from the side the component was inserted.
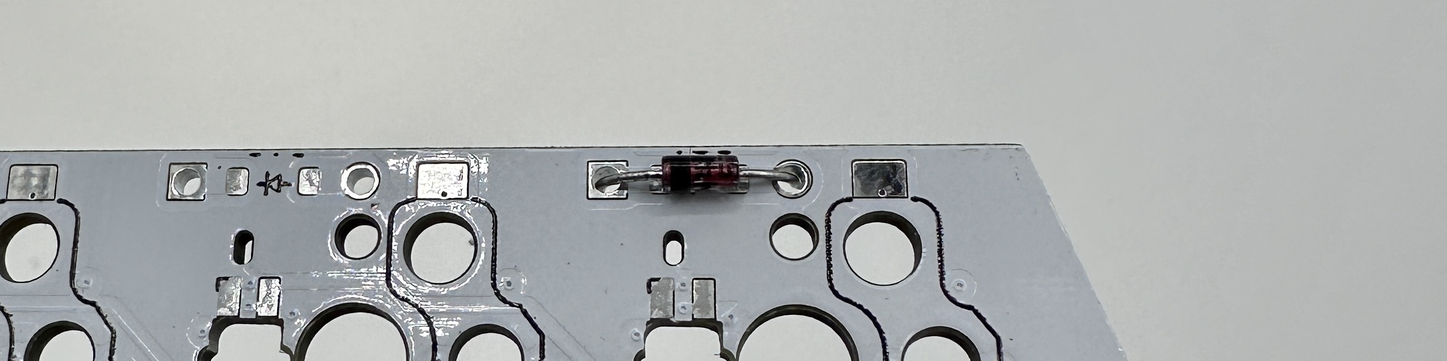
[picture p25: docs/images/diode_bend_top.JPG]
pcb with diode inserted from the top
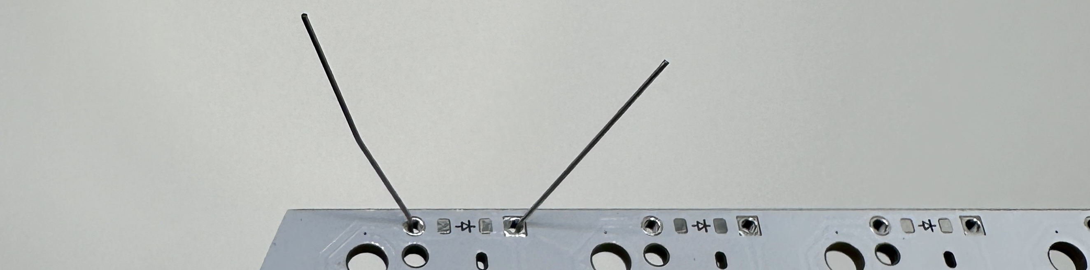
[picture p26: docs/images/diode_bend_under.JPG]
pcb with bent diode legs
<br>  
1. **The tape method**: Push the legs through the holes and put a piece of kapton tape over the component to keep it in place when the board is flipped. Solder on the side of the board opposite from the side the component was inserted.
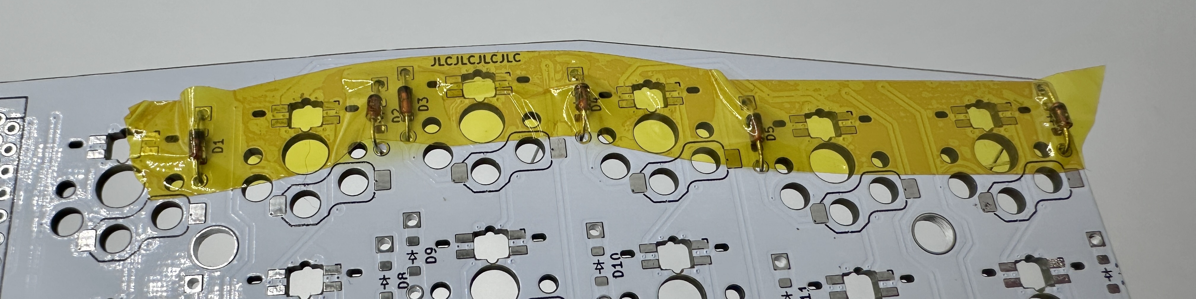
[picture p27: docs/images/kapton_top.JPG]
pcb with diodes held in place by kapton tape
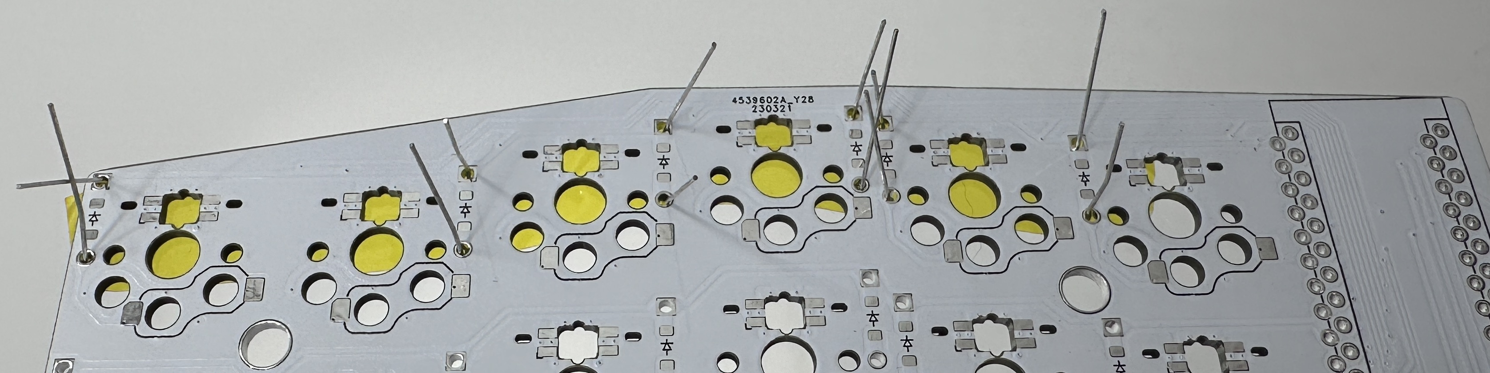
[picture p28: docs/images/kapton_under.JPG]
underside of pcb with diodes held in place by kapton tape
<br>  
1. **Work holding**: Use helping hands or work holding jig to keep the PCB lifted off the work surface. Insert components through the holes, _do not_ flip the pcb, and solder on the side the components are inserted. <br> This is the recommended method.<br>If you have access to a 3d printer, you can print disposable [work holding legs designed specifically for the ErgoDonk Zero PCB](https://www.printables.com/model/733164-ergodonk-zero-pcb-holding-feet). <br> <Br>
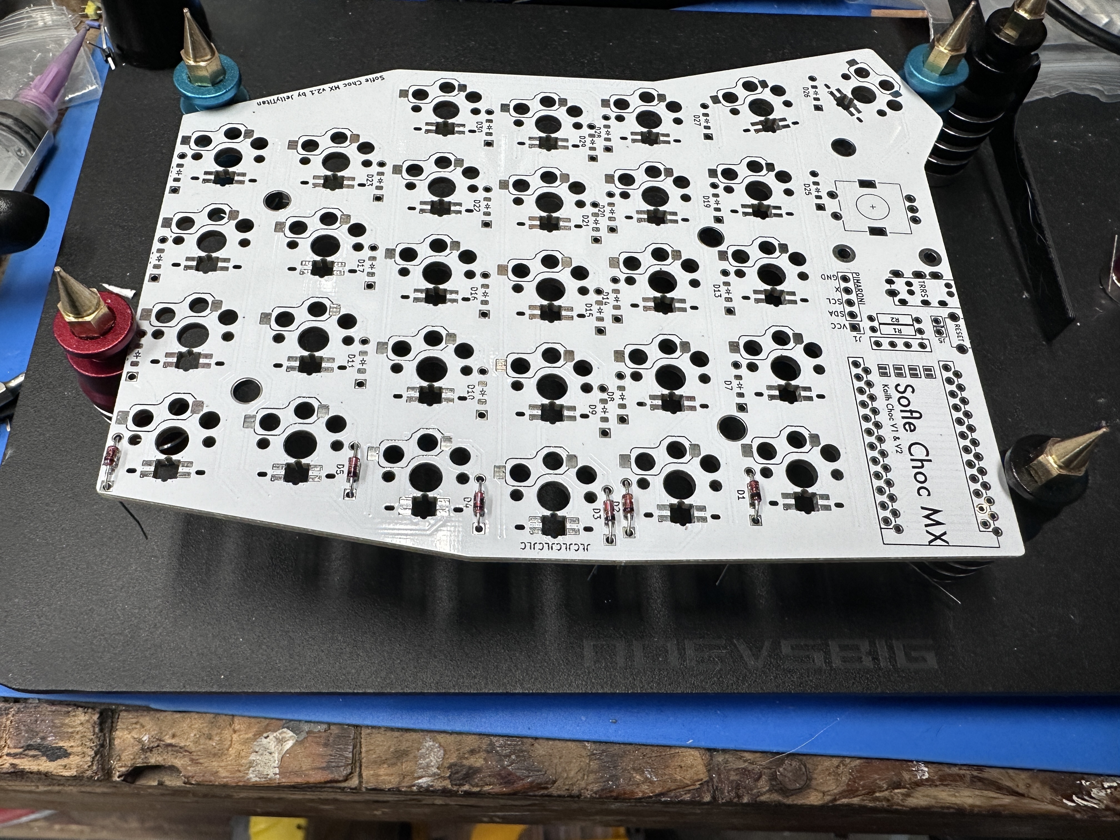
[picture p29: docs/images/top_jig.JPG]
pcb in workholding jigs with diodes inserted from the top
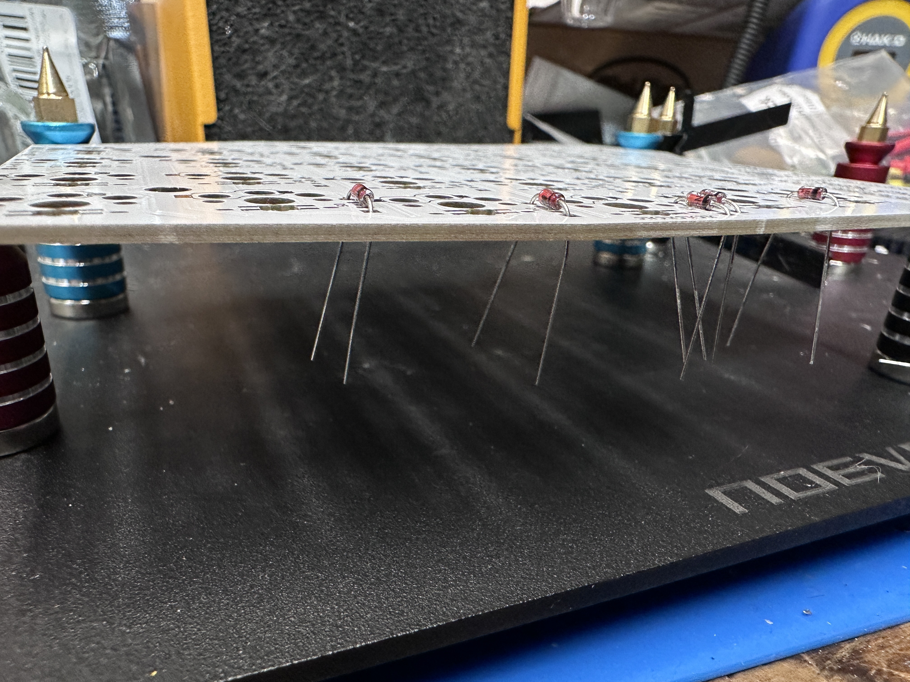
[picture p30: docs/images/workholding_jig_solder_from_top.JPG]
pcb in workholding jigs with diodes protruding
**[Magnetic work holding thingies](https://www.aliexpress.us/item/2255800735314797.html)** <br> <br> <br>**[3d Printable work holding feet](https://www.printables.com/model/733164-ergodonk-zero-pcb-holding-feet)**<br>
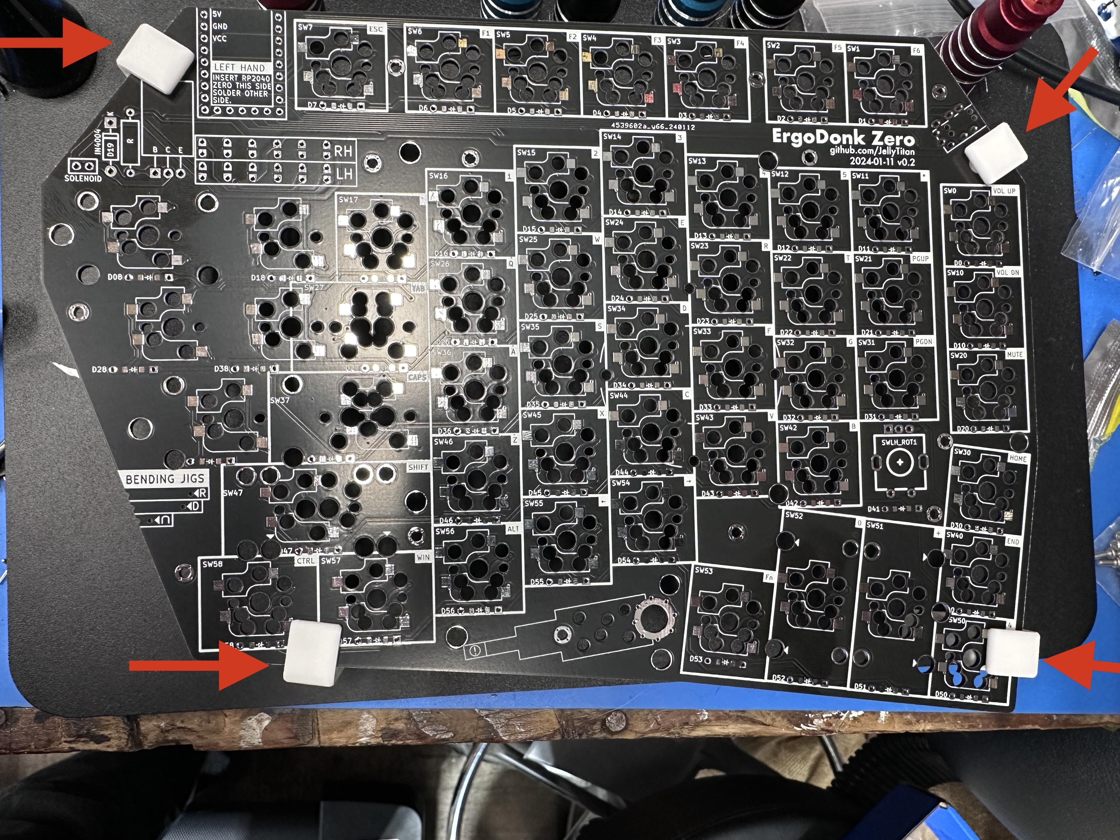
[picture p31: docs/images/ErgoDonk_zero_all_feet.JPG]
Disposable 3d printable work holding legs for the ErgoDonk Zero
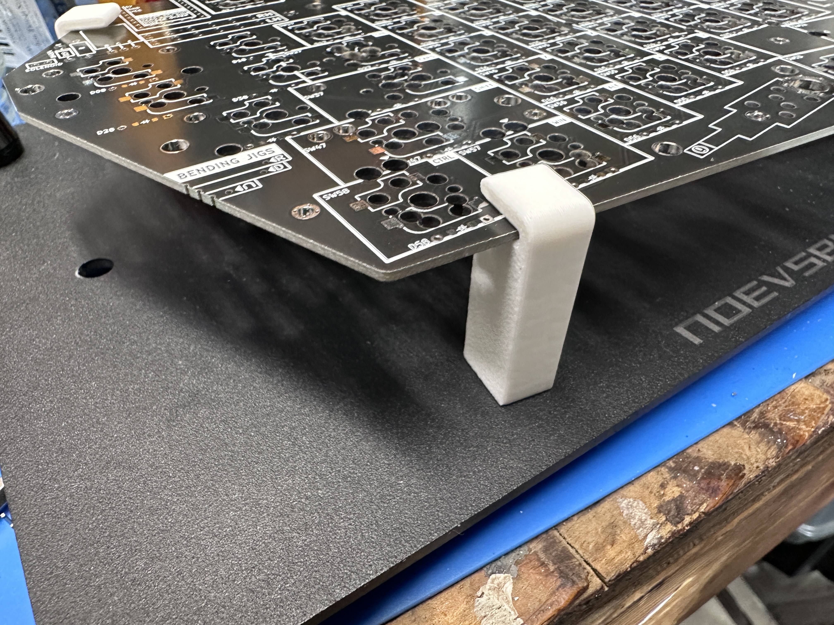
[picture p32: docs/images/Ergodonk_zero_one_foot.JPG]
Close up of a disposable 3d printable work holding leg for the ErgoDonk Zero
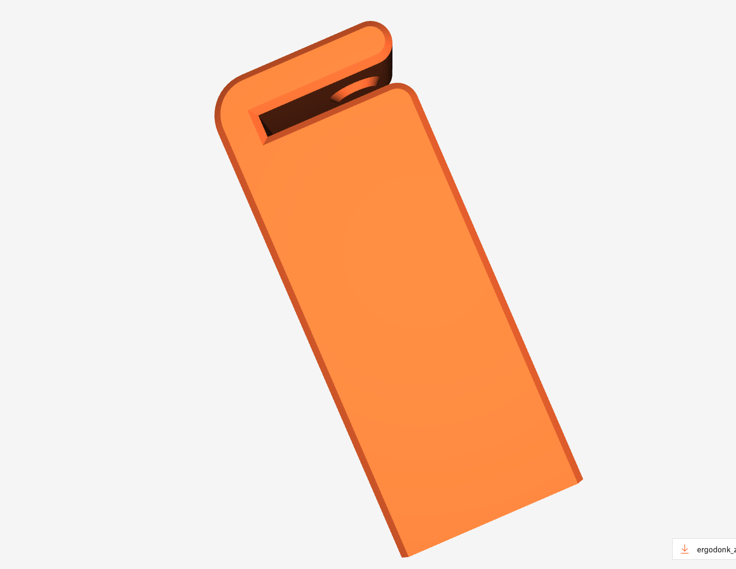
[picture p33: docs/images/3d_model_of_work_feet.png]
3d model of a disposable 3d printable work holding leg for the ErgoDonk Zero
  

<hr>

### Prepare

Make sure you know which side you are working on, and don't make two left hand sides by mistake. Stick a piece of tape on the front side of both PCBs to help remember.
@todo Update image.
Sofle V3

The assembly order does not matter. This guide is written in the order I like to install components, starting with the components on the back, shortest to tallest:
 - diodes
 - switch sockets

Then install the components on the front:
 - Jumpers
 - RP2040 Zero MCU
 - TRRS connector
 - Solenoid components
 - Rotary encoder

<hr>

### Diodes

Diodes, surface mount or through-hole, should be installed on the back of the board. This allows for easy access after the keyplate is installed, and allows for the use of choc keyplates and stabilizers.

If you are hand soldering, through hole diodes are recommended because they are easier. If you damage a pad on one side, you can install the diode on the opposite side.

If you are using PCBA with surface mount diodes, either the front or the back will technically work, but surface mount diodes on the front will prevent the use of a choc keyplate.

There is one diode per key, and one for the rotary encoder. The right hand has more than the left hand.

When inserting diodes into the backs of the boards, you only need to insert diodes into the footprints that have an accompanying switch socket outline. For example, in this image, we are looking at the backside of the left hand board. The left hand does not have a switch 18, so there is no socket outline, and so no diode would be needed. If you do add a diode where it is not needed, there is no negative impact.<br>
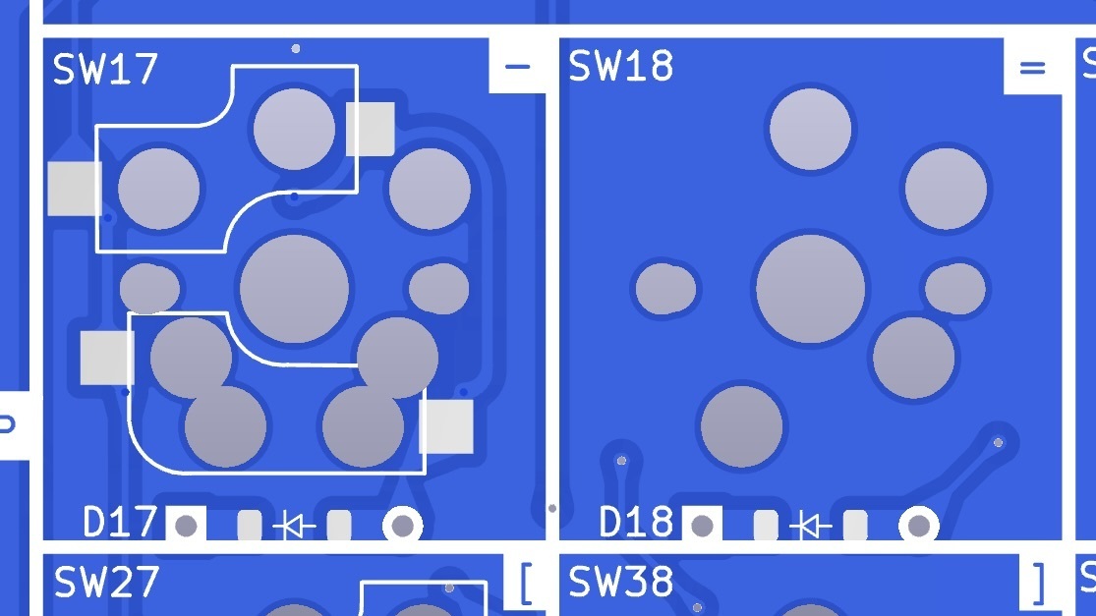
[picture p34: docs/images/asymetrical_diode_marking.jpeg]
Through hole diode orientation
<br>

For surface mount diodes, a common soldering method method is to tin one pad, place the diode on, apply the soldering iron to the diode leg until it melts the solder underneath and sinks flush with the PCB. Then come back and solder the other leg. Alternately, you can use a rework station heat gun and solder paste. (I prefer this method for smds).
<br>SMD Orientation:<br>
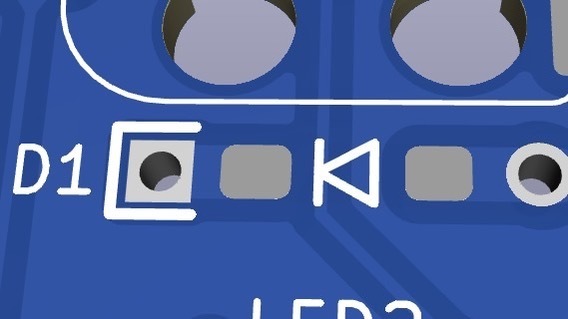
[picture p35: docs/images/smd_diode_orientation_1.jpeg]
SMD orientation marking example

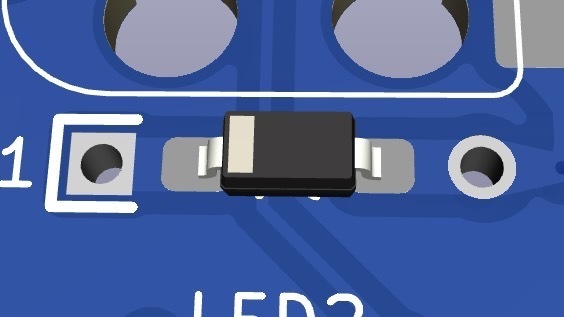
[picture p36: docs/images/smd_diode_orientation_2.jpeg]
SMD orientation example


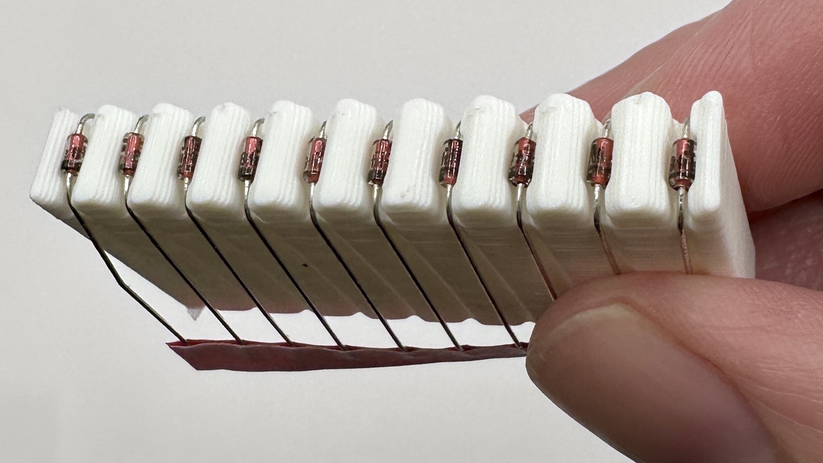
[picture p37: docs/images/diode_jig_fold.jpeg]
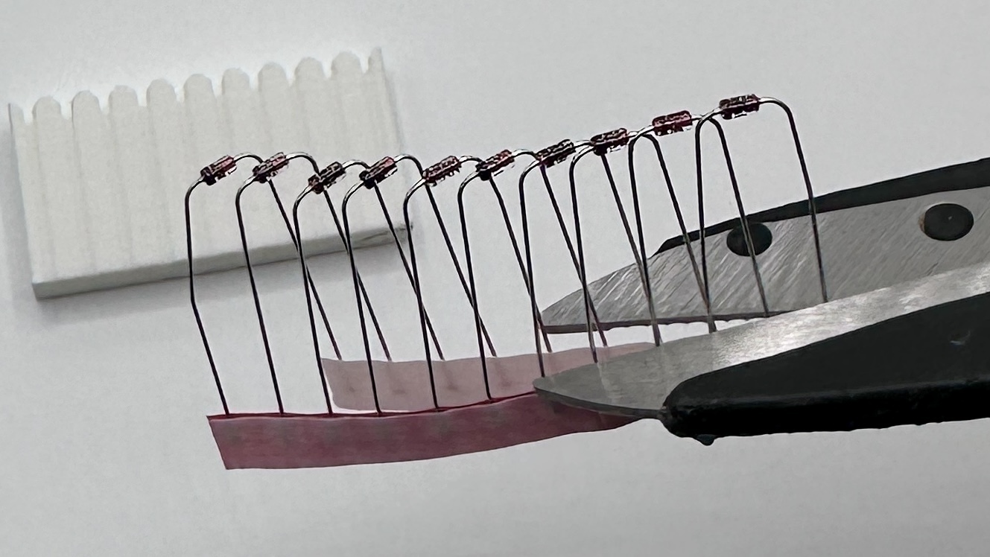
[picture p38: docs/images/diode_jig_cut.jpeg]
For through-hole diodes, pre bending the legs while they are still on the paper strip makes inserting them much easier. You can use a 3d printed diode [bending jig](https://www.printables.com/model/734696-diode-bending-jig-8mm) to make quick uniform bends.<br> 

Alternately, a carpenters pencil is roughly the right size. (The diode holes are 8mm apart, wooden pencils are often 7mm - 8mm).
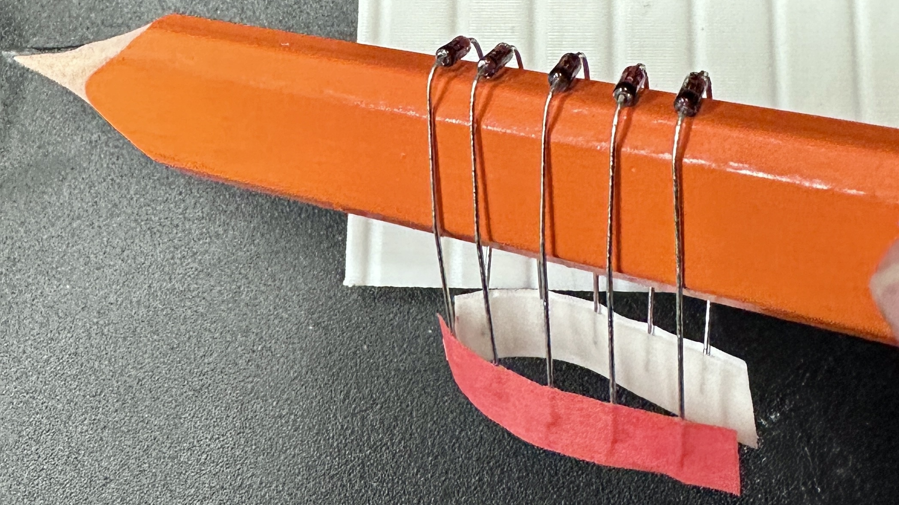
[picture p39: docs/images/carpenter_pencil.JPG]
Using a carpenters pencil as a bending jig


With the PCB eleveated via workholding, insert the bent diodes into the holes on the back of the board. 
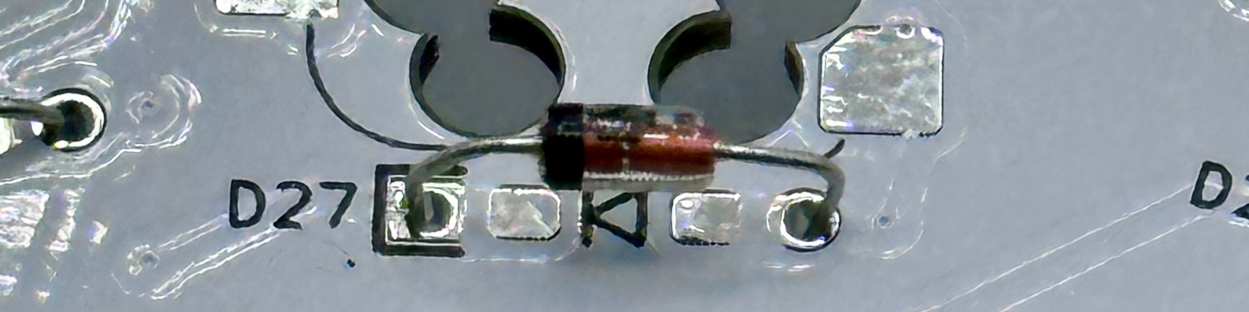
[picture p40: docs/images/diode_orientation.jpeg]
Through hole diode orientation
Diodes _must_ be oriented with the black band in the direction of the "arrow" symbol on the PCB. There is also a black outline around the pad to make it easy to check the diode orientation is correct after the diode has been soldered in place.<br>

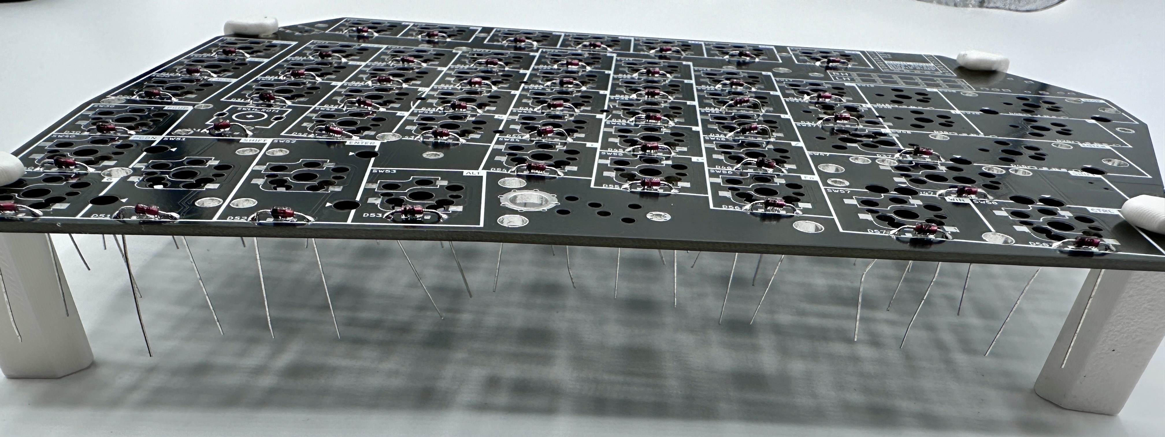
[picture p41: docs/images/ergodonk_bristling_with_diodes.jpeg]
Through hole diode orientation
 
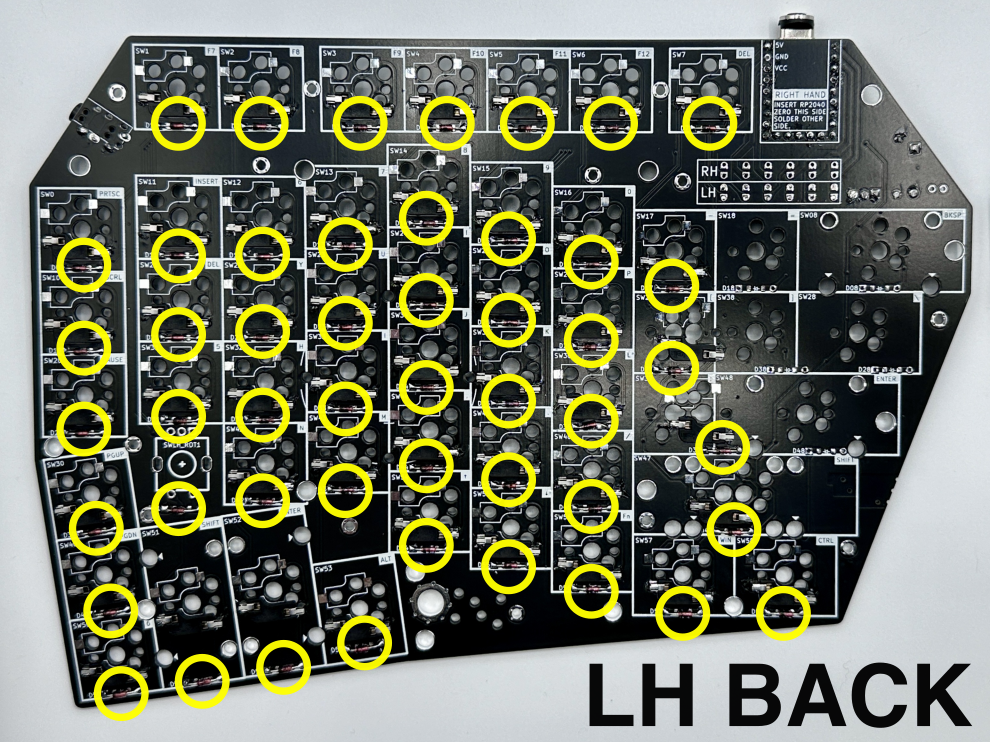
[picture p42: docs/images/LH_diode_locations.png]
Left hand diode locations on the back of the ErgoDonk zero keyboar
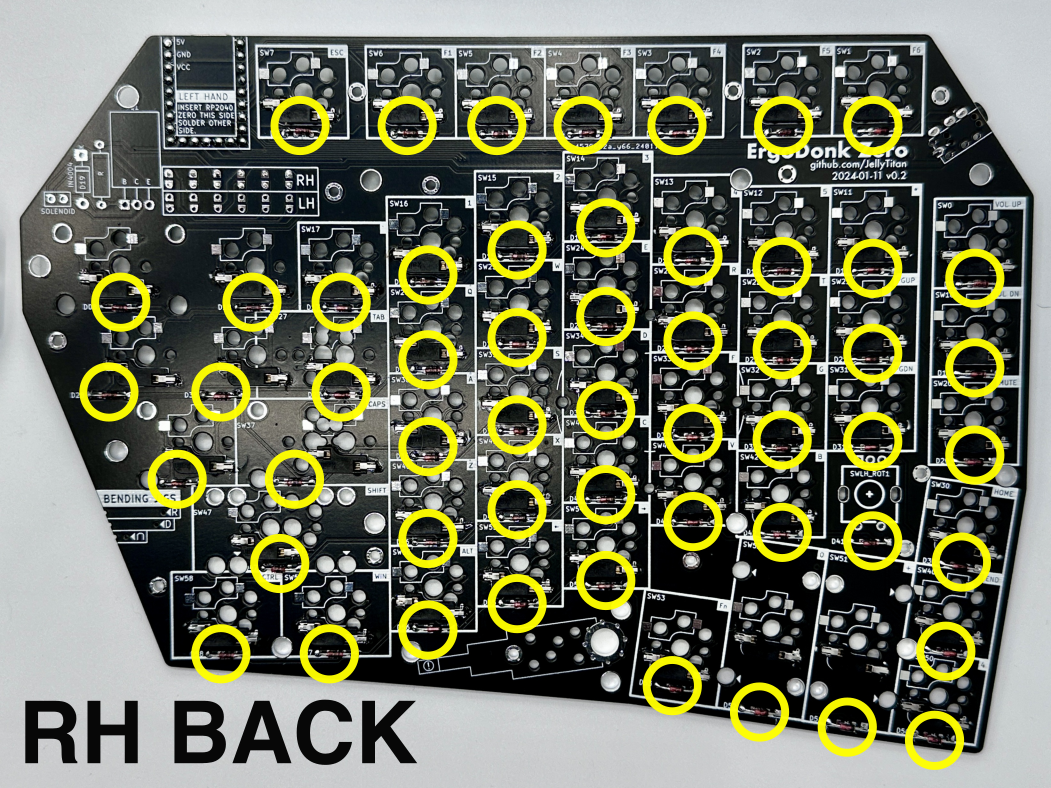
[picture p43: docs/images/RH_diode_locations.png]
Right hand diode locations on the back of the ErgoDonk zero keyboard
  

Solder the legs in place.

Flip over the board, and trim the legs.

When you trim off the diode legs, save 12 for use as jumpers.

<hr>

### Switch Sockets
Switch sockets installed on the back of the PCB facing up towards the front of the PCB. Make sure they are flush with the PCB. 

1. Put all the sockets in place. PCB hole tolerance can vary quite a bit, so some sockets may snap in, while others rest in the holes. If you have some that snap in, be sure to check everything is flush before you start soldering. 
1. Solder _one_ side of each socket by heating the metal connector. Apply solder and look for the solder to wick down to the PCB. You want a solid joint since this may take some mechanical strain from switch installation and removal. The 3d printed workholding feet are really handy here. You can reposition the board as you work to get the best angle for soldering those connectors.
1. Give the board a few good taps to make sure there are no loose sockets.
1. Rotate the board 180 degrees and solder the remaining sides.

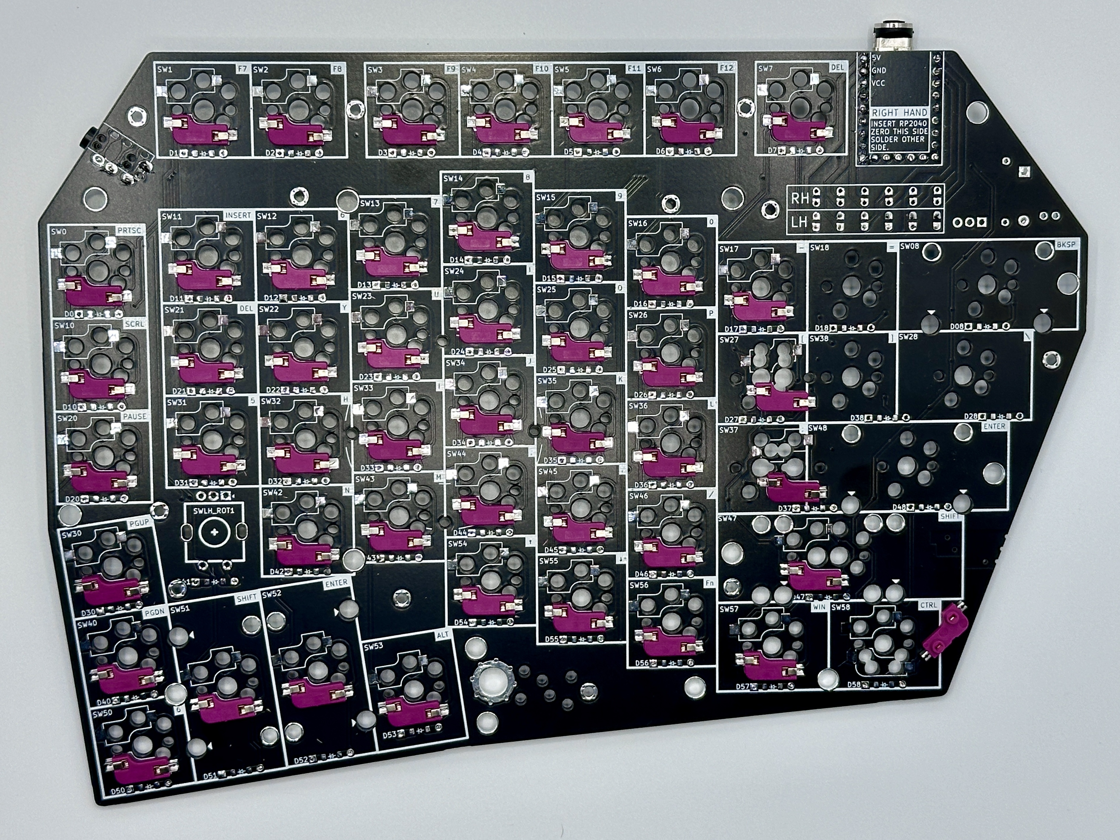
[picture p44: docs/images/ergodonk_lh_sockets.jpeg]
ErgoDonk left hand backside indicating socket placement
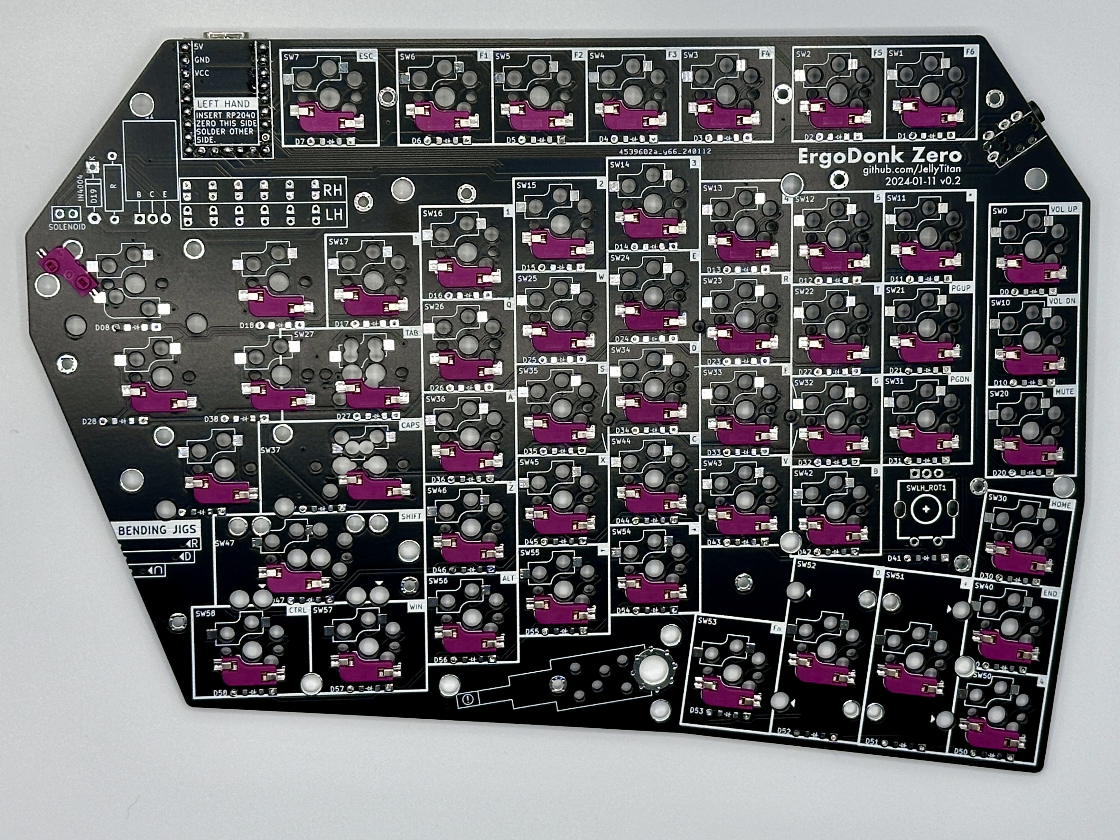
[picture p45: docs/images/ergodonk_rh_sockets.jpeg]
ErgoDonk right hand backside indicating socket placement
 
<hr>

### Jumpers
Because the MCU on both sides shares the same footprint, we need to set jumpers to ensure the power is routed correctly. The set of six jumpers for the right and left hands are marked accordingly. They can be soldered on the front or the back. Soldering on the front is recommended.

You can bridge the jumpers by dragging a blob of solder across the 2 adjacent pads. Modern rosin core solder can make this difficult. As an alternate bridging method, you can bend a diode leg and solder that in place. There is bending jig to make it easy to bend jumpers to the optimal width. The bottom slot on the jig is for the jumpers.

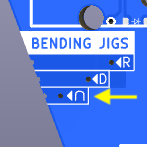
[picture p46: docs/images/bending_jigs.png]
Bending jig location
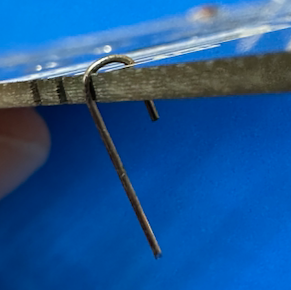
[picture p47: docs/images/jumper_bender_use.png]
Jumper bending jig in use
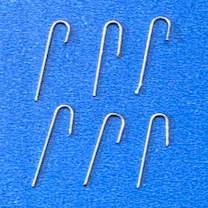
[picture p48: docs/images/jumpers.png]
Six bent jumpers made from diode legs
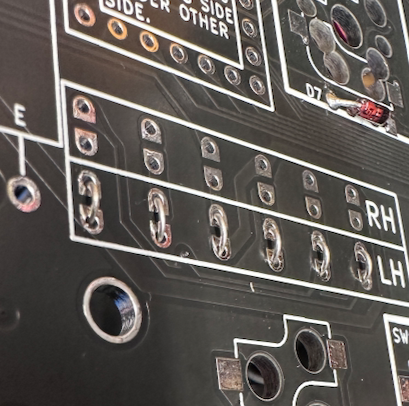
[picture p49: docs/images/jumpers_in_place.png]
Jumpers on the board that have not been soldered.
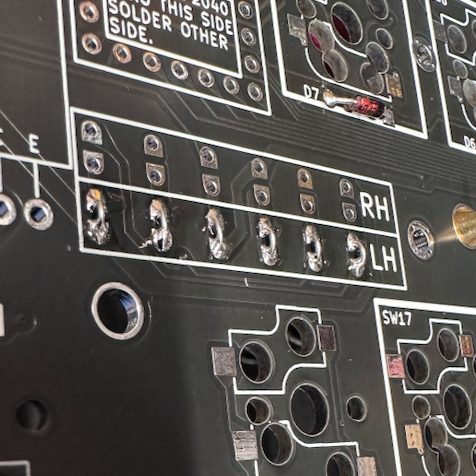
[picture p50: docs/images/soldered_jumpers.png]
Soldered jumpers on the left hand of the ErgoDonk Zero
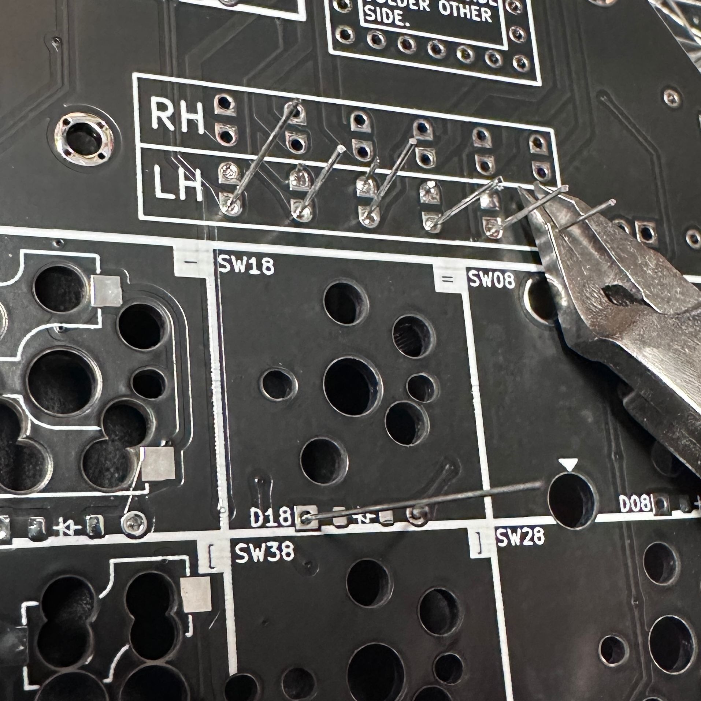
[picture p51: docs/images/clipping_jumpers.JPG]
clipping excess jumpers on the left hand of the ErgoDonk Zero
     

<hr>

### RP2040 Zero MCU
The Zero is installed on the top of the board, buttons facing up.

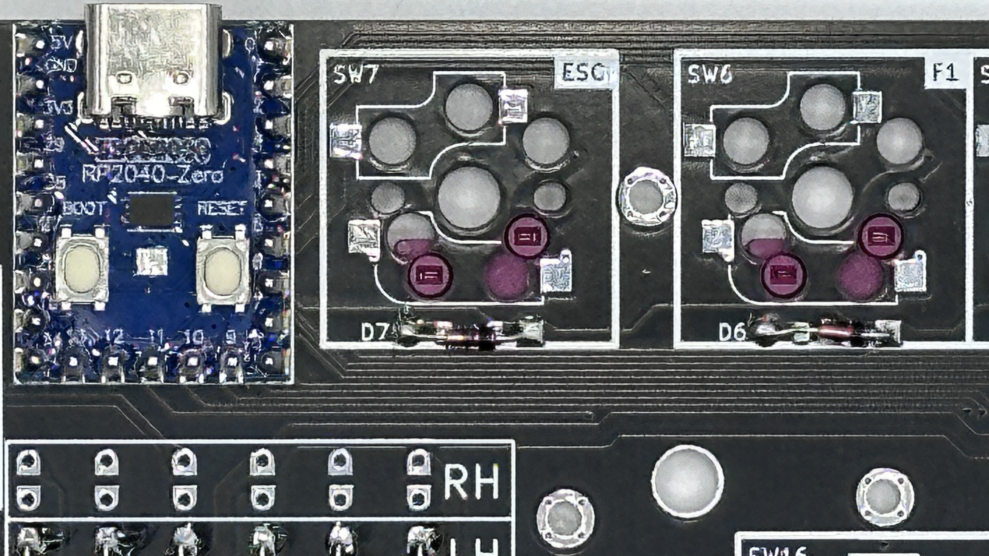
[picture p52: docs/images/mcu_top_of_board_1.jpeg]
RP2040 Zero installed on the top of the left hand board of the ErgoDonk Zero keyboard let me see those buttons baby!
 
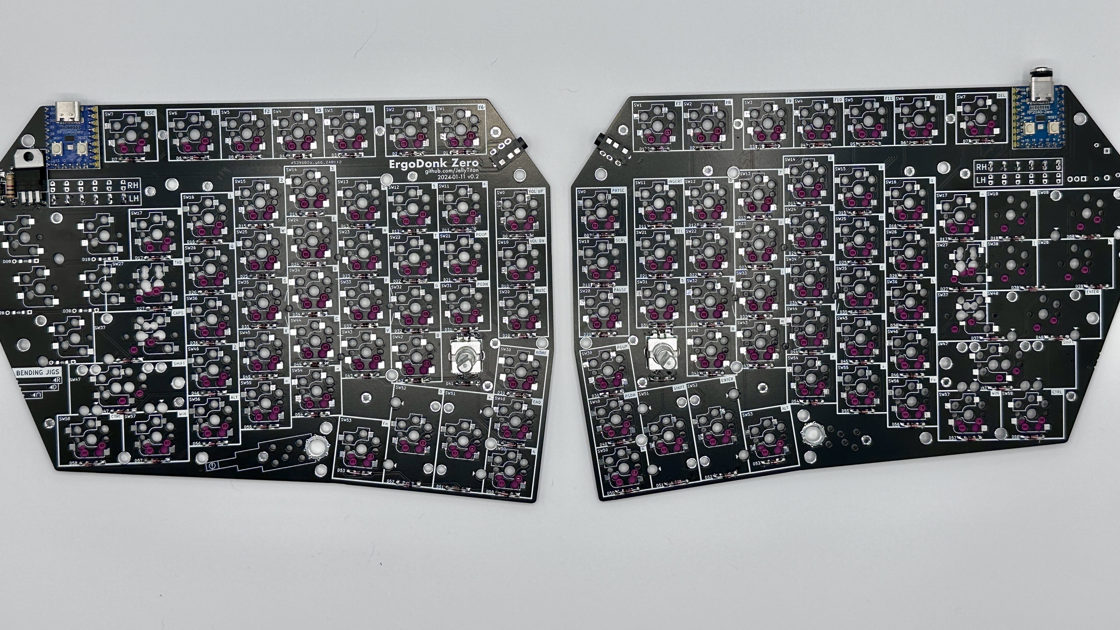
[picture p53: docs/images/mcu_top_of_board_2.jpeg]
RP2040 Zero installed on the top of both sides of the ErgoDonk Zero keyboard Notice the MCU's installed on the top in the outer corners.


* Top of the board: this is the side of the PCB opposite the diodes and switch sockets
* Marked holes: Insert the Zero into the holes with the rectangular outline on the top of the board. 

Install the Zero using the male-male headers that came with the Zero. (Or the low-profile headers, if your feeling fancy)!
1. Insert the headers into the board and the Zero both before soldering. The header pin rows can tilt a little if it's not inserted into both the board and the Zero. The header pins that come with the zero have one longer side. Install the longer side on the PCB because you'll need to trim these, and the trimmed pins look better on the underside of the board. Use a piece of kapton tape to attach the Zero to the PCB while soldering.
If you are using a Zero with pre-soldered headers, you'll likely have to bend the headers a bit to get everything to line up perfectly. Once you get it in, the friction will keep it in place, and you can skip the tape.

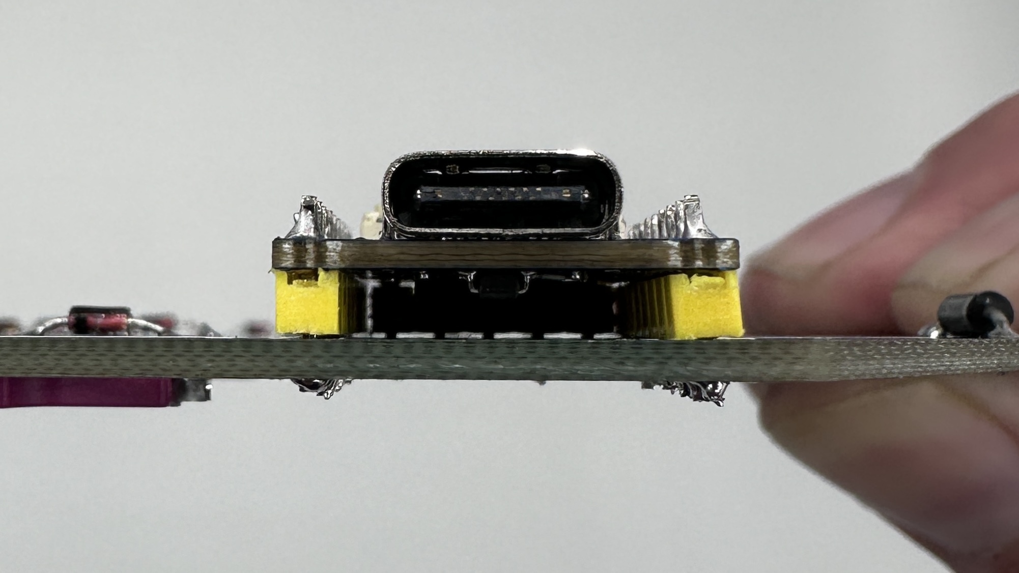
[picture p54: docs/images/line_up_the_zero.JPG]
first pin line up of the MCU
1. Flip the board over. Solder 1 of the outermost pins on each pin header on the PCB. Hold the board up to make sure the pin header is sitting flush with the pcb. If it's not, you can reheat that joint until it is flush.<br> 
1. Solder the remaining pcb/pin header joints on the back.
1. Flip the board over. With the Zero, repeat the process of soldering & checking 1 pin with the pin header and the Zero. 
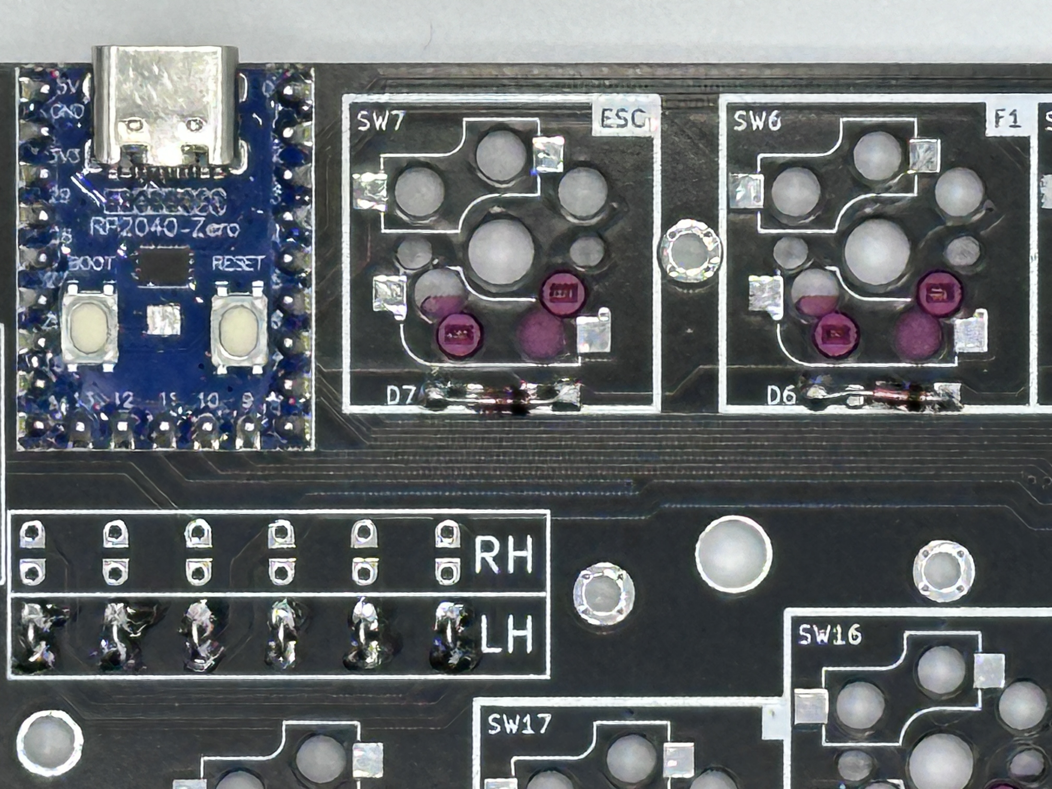
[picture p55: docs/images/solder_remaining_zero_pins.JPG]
RP2040 Zero MCU all pins soldered
1. Solder all the remaining Zero/pin header pins.<br>

<hr>

### TRRS Jacks
Insert the jack into the outline on the front of the board. Some brands of jack will snap into the board, holding them in place. Others may need to be taped down. Then flip the board over and solder on the backside. Solder 1 pin first to check that everything is flush. Adjust as needed. Solder remaining pins.<br>
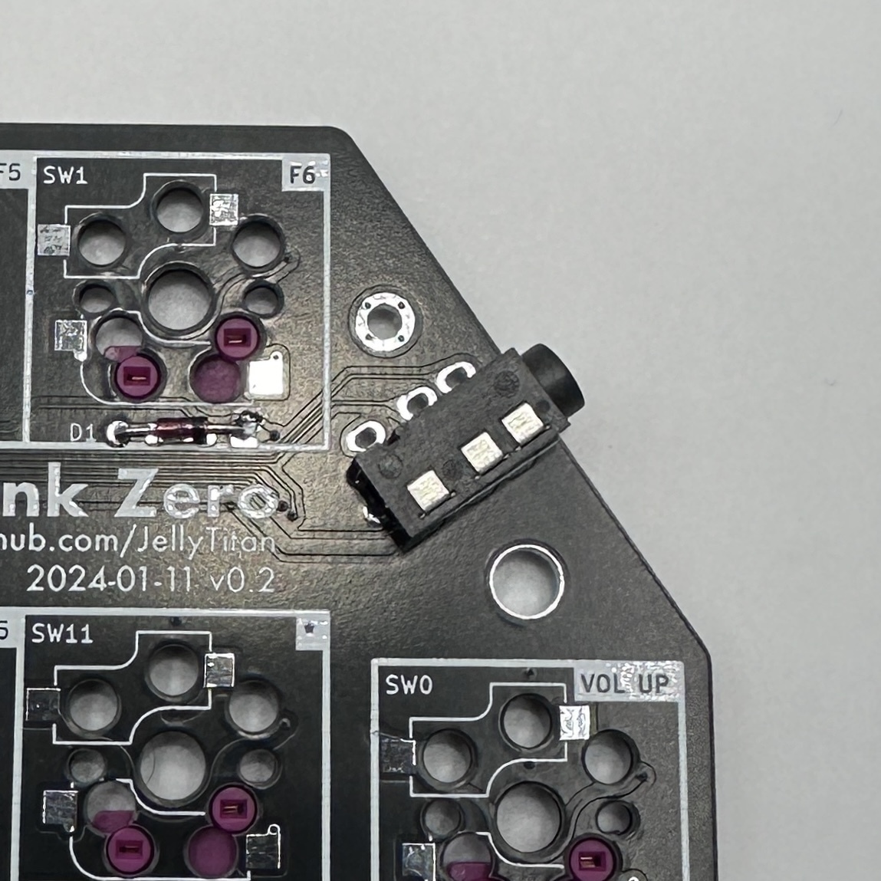
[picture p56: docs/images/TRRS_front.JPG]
TRRS jack from the front
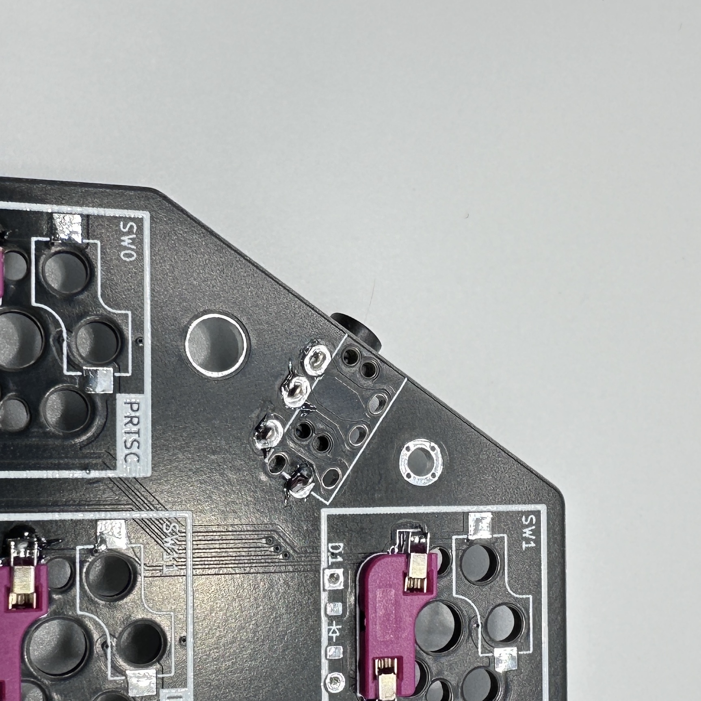
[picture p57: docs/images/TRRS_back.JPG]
TRRS jack from the back
 

<hr>

### Solenoid
The Solenoid is installed on the left hand front of the board _only_. Right hand installation is not supported.

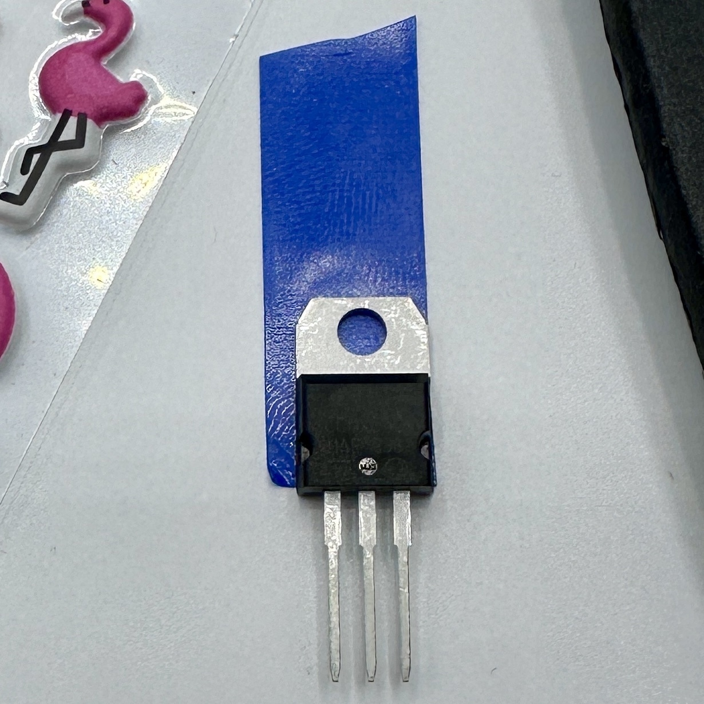
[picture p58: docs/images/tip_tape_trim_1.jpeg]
tip120 with untrimmed tape insulation
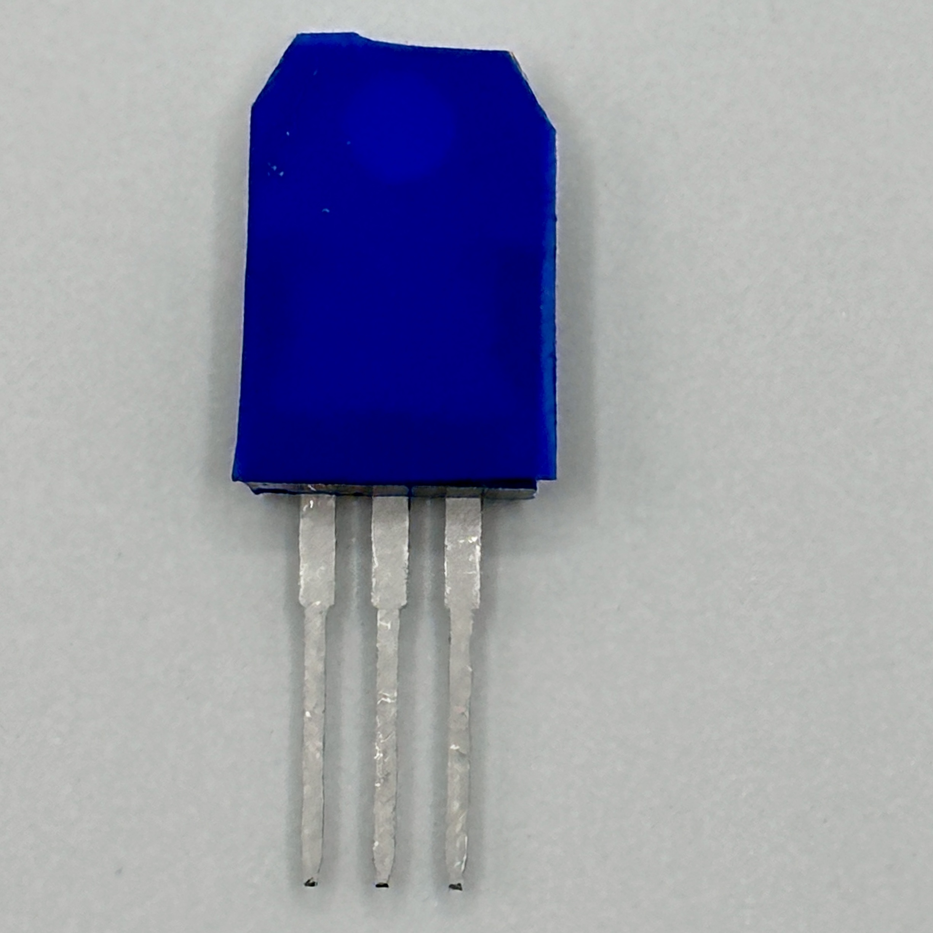
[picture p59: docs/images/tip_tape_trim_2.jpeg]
tip120 with trimmed tape insulation
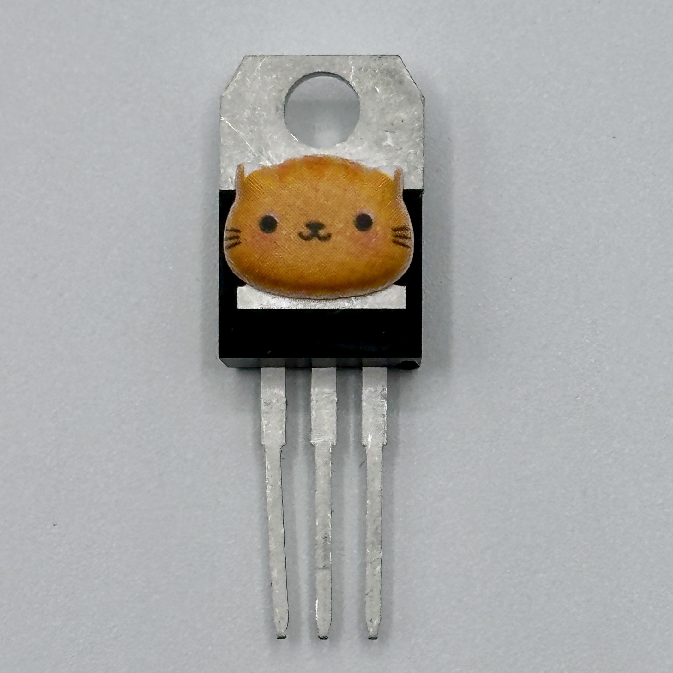
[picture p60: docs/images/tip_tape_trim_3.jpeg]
tip120 with sticker insulation
1. Put a piece of electrical tape on the backside of the tip120 and trim it to the outline. In some applications these get really hot so a heat sink could be attached. Our application will never need that heat sink, but we don’t want that exposed metal against our board. Alternately, You can slap a sticker on there if you’re feeling fancy.<br>    
1. Use the tip120 bending jig to get a 90 degree bend just below the fat part of the pins.
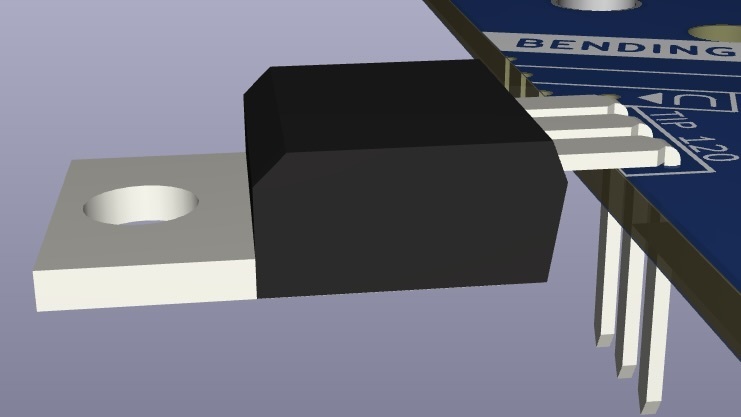
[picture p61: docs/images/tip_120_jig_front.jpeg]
diode bending jig front
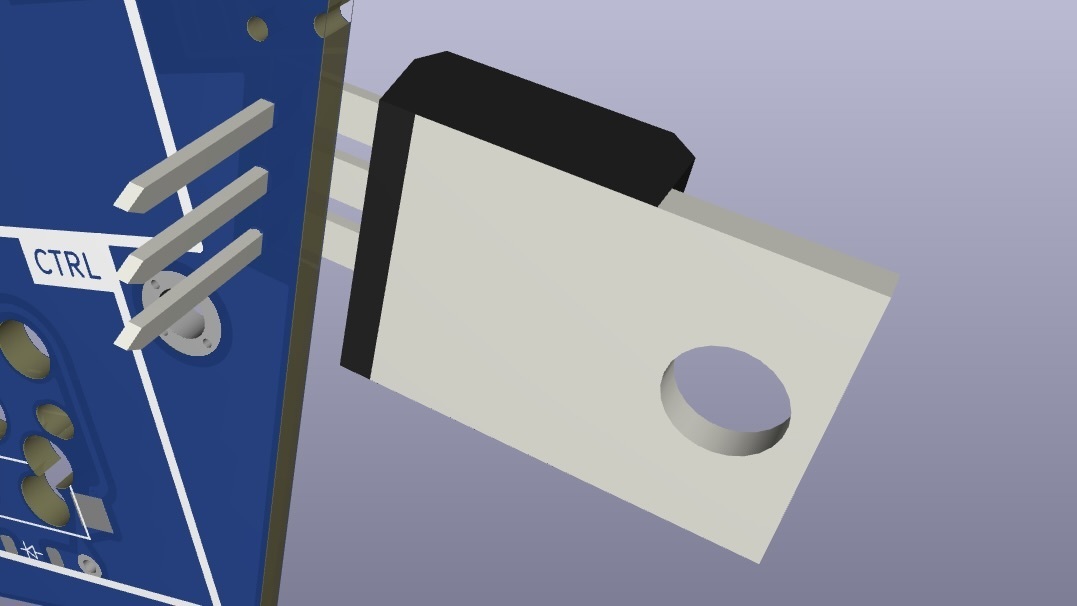
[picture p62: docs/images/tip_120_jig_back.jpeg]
diode bending jig back
<br>  
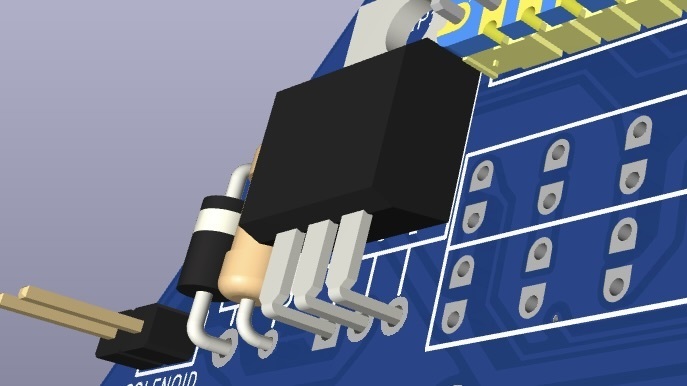
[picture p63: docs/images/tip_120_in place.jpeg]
1. Insert the tip120 into the holes on the front of the board. Solder 1 pin, verify the tip120 is straight before soldering the remaining pins.<br> tip120 render showing the 90 degree bend
1. Bend the legs of the 1k resistor using the bending jig on the left of the board.<br>render demonstrating resistor bending jig
1. Insert the 1k resistor into the holes on the front of the board. Orientation of the resistor does not matter. Solder in place.<br>1k resistor placement indicated 
1. Bend the legs of the 1N4004 Shottky diode using the bending jig on the left of the board.<br>render demonstrating resistor bending jig
1. Insert the 1N4004 Shottky diode into the holes on the front of the board. Be sure to orient the diode with the strip towards the top of the board. Solder in place.<br>1k resistor placement indicated
1. Flip the board and trim the pins sticking out for the components you just installed. <br>trimming pins on the backside
1. Using M2 screws, attach the solenoid to the top of the board. Run the wires through the big hole in the PCB. Tape the wires down with kapton tape. Solder onto the holes marked 'solenoid'. Polarity does not matter, so either wire can go in either hole. Versions after 0.2.1 have an additional solenoid footprint connetion point closer to the solenoid itself. This is to accomodate shorter wires. Either connection point will work. <br>Solenoid attached to the front of the left hand board by 2 M2 screws Solenoid wiring routed along the back of the board Solenoid connection point indicated

<hr>

### Rotary encoders
Saved these for last because they are tallest. Insert into the top of the board, and solder on the backside. Some EC11's have metal tabs on opposite sides that add mechanical stability - no need to solder those tabs.
<br>rotary encoder soldered to the PCB

<hr>

### Final assembly
Installing the stabilizers, keys and case.

1. Install stabilizers. (Optional) The stabilizers are inserted into the front of the board, and screws are inserted on the back of the board. There are an abundance of holes around the pinky keys, so the stabilizer insertion holes have been marked with an arrow on the front of the board. Lay down the stabilizer stickers starting with the arrow side. <br> stabilizer markings stabilizer installed on left hand shift key<br> Notice the thumb clusters stabilizers are 'back-to-back': <br>thumb stabilizers installed
1. Snap switches into the corners of the key plate.
1. Place the PCB on a flat surface. This will save some strain on the solder joints in the next step (though they should be able handle it).
1. Carefully lower the top plate with switches on the main PCB and push into sockets. Ensure pins are aligned.
1. Snap the remaining switches into the top plate pressing into the sockets.
1. Place the encoder knob on the shaft. Tighten the set screw with a hex key. A small screwdriver for glasses may do in a pinch.
1. @todo - update: Slide the four 8mm standoffs through the PCB and align to the holes on the key plate. Attach the standoffs to the keyplate using M2 screws. 
1. Attach the bottom plate to the four standoffs installed in the previous step.
1. Use M2 screws to attach the three 12mm standoffs to the OLED cover plate.
1. Slide the three standoff on the OLED plate through the PCB. Attach those standoffs to the backplate using M2 screws.
1. Put at least 4 adhesive rubber feet in the corners so the keyboard is not moving when you type.

<hr> 

## Warnings and disclaimers
- Don't connect or disconnect the TRRS cable when the keyboard is powered. It may short out. Always disconnect the USB cable first.
- Be gentle with USB-C ports on your micro controllers. They are easy to break.
- Keep in mind that this is a prototype of a DIY keyboard. It’s not a polished product.

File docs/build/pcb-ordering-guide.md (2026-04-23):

---
layout: page
title: PCB Ordering
description: How to order ErgoDonk Zero PCBs from JLCPCB or Elecrow. Covers gerber file upload, board dimensions (217×156mm), color options, lead-free finish, and part number placement.
parent: Build
permalink: /build/pcb-ordering
nav_order: 2
# Structured data: renders _includes/structured_data/pcb_ordering_howto.html into <head> via _includes/head_custom.html.
# Remove or rename this key to disable.
schema: pcb-ordering-howto
---

{% assign img1 = site.data.image_manifest["images/ordering_guide/JLCPCB_Ordering_1.png"] %}
{% assign img2 = site.data.image_manifest["images/ordering_guide/JLCPCB_Ordering_2.png"] %}
# PCB Ordering Guide.

How to order this board from a PCB vendor - helpful info if it's your first time ordering a PCB.

Most PCB vendors have a similar ordering process. I use [JLCPCB](https://jlcpcb.com/) because they are usually the most cost effective. I've had good luck with [Elecrow](https://www.elecrow.com/) too. [You can find PCB price comparison tools online.](https://pcbshopper.com/) When comparing pricing, be sure to enter the board dimensions, and set the minimum quantity to 5. The ErgoDonk zero is 217mm X 156mm. Usually anything under 100x100mm is really inexpensive - so be sure to use actual dimensions when pricing. Most manufacturers have a 5 board minimum, so this is a safe quantity to start with.

Usually the minimum quantity to order is 5 boards. The ErgoDonk Zero has been designed to be double-sided, so a batch of 5 boards gets you 2 & 1/2 sets.

The production files are known as "gerbers", and they are usually uploaded as a `.zip` file. (It's essentially a collection of files for each layer of the board, like holes, graphics, traces etc.) 

The Gerbers for the ErgoDonk Zero can be found as a zipped file in the "Releases" section on the right hand side of the [Github repo](https://github.com/JellyTitan/ErgoDonk-Zero). 
{% comment %}
@todo add image and name of release
{% endcomment %}
The homepage of JLCPCB has a drag & drop upload. Drag the gerber `.zip` and drop it on the "add gerber file" box.

<figure>
    {% include slider_img_srcset.html
        src="images/ordering_guide/JLCPCB_Ordering_1.png"
        alt="jlcpcb button for uploading Gerber files"
        manifest=img1
        eager=true
        fetchpriority="high" 
    %}
</figure>

While the file is uploading, it will take you to an options screen. Once the board size is detected<sup>1</sup>, the price<sup>2</sup> will update accordingly.
Changing the pcb color<sup>3</sup> may impact production time and price.
Shipping estimates<sup>4</sup> can vary widely, so be sure to check those. (You'll see these options again during checkout).
<figure>
    {% include slider_img_srcset.html
        src="images/ordering_guide/JLCPCB_Ordering_2.png"
        alt="JLCPCB Home"
        manifest=img2
        eager=true
        fetchpriority="low" 
    %}
</figure>

{: .warning }
> Warning: The default pcb surface finish contains Lead. For boards in cases, this is usually not a problem. If you're going to rock a naked board, consider going with "lead free"<sup>5</sup> for a few bucks more. The more popular colors like green and black tend to cost less for the lead free option.

By default, all JLC boards have a part number printed on them. (Most people won't notice them unless you're looking for them). You can pay extra to have them removed. ErgoDonk Zero supports the option to "Specify a location"<sup>6</sup>. (Essentially this is a line of text on the PCB that JLC will substitute with their part number.) There is no additional charge for specifying the location. 

The remainder of the checkout process is standard e-commerce stuff. After you pay for your order, it will be reviewed before going into production. They will let you know if the file has any issues.

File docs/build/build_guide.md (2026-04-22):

---
layout: page
title: Build Guide
description: Step-by-step assembly guide for the ErgoDonk Zero split keyboard. Covers diodes, hotswap sockets, MCU headers, solenoid wiring, encoders, and case assembly.
parent: Build
permalink: build/build-guide
nav_order: 4
# Structured data: renders _includes/structured_data/build_guide_howto.html into <head> via _includes/head_custom.html.
# Remove or rename this key to disable. Add the same key to any other page to reuse the same schema.
schema: build-guide-howto
---

{% assign img1 = site.data.image_manifest["images/asymmetrical_diode_marking.jpeg"] %}
{% assign img2 = site.data.image_manifest["images/smd_diode_orientation_1.jpeg"] %}
{% assign img3 = site.data.image_manifest["images/smd_diode_orientation_2.jpeg"] %}
{% assign img4 = site.data.image_manifest["images/diode_jig_fold.jpeg"] %}
{% assign img5 = site.data.image_manifest["images/diode_jig_cut.jpeg"] %}
{% assign img6 = site.data.image_manifest["images/carpenter_pencil.JPG"] %}
{% assign img7 = site.data.image_manifest["images/diode_orientation.jpeg"] %}
{% assign img8 = site.data.image_manifest["images/ergodonk_bristling_with_diodes.jpeg"] %}
{% assign img9 = site.data.image_manifest["images/LH_diode_locations.png"] %}
{% assign img10 = site.data.image_manifest["images/RH_diode_locations.png"] %}
{% assign img11 = site.data.image_manifest["images/ergodonk_lh_sockets.jpeg"] %}
{% assign img12 = site.data.image_manifest["images/ergodonk_rh_sockets.jpeg"] %}
{% assign img13 = site.data.image_manifest["images/bending_jigs.png"] %}
{% assign img14 = site.data.image_manifest["images/jumper_bender_use.png"] %}
{% assign img15 = site.data.image_manifest["images/jumpers.png"] %}
{% assign img16 = site.data.image_manifest["images/jumpers_in_place.png"] %}
{% assign img17 = site.data.image_manifest["images/soldered_jumpers.png"] %}
{% assign img18 = site.data.image_manifest["images/clipping_jumpers.JPG"] %}
{% assign img19 = site.data.image_manifest["images/mcu_top_of_board_1.jpeg"] %}
{% assign img20 = site.data.image_manifest["images/mcu_top_of_board_2.jpeg"] %}
{% assign img21 = site.data.image_manifest["images/line_up_the_zero.JPG"] %}
{% assign img22 = site.data.image_manifest["images/solder_remaining_zero_pins.JPG"] %}
{% assign img23 = site.data.image_manifest["images/TRRS_front.JPG"] %}
{% assign img24 = site.data.image_manifest["images/TRRS_back.JPG"] %}
{% assign img25 = site.data.image_manifest["images/tip_tape_trim_1.jpeg"] %}
{% assign img26 = site.data.image_manifest["images/tip_tape_trim_2.jpeg"] %}
{% assign img27 = site.data.image_manifest["images/tip_tape_trim_3.jpeg"] %}
{% assign img28 = site.data.image_manifest["images/tip_120_jig_front.jpeg"] %}
{% assign img29 = site.data.image_manifest["images/tip_120_jig_back.jpeg"] %}
{% assign img30 = site.data.image_manifest["images/tip_120_in place.jpeg"] %}
{% assign img31 = site.data.image_manifest["images/solenoid_circuit_tip120.jpeg"] %}
{% assign img32 = site.data.image_manifest["images/resistor_bending.jpeg"] %}
{% assign img33 = site.data.image_manifest["images/solenoid_circuit_1k_resitor.jpeg"] %}
{% assign img34 = site.data.image_manifest["images/1N4001_diode_bending.jpeg"] %}
{% assign img35 = site.data.image_manifest["images/solenoid_circuit_1N4001_diode.jpeg"] %}
{% assign img36 = site.data.image_manifest["images/solenoid_pin_nipping.jpeg"] %}
{% assign img37 = site.data.image_manifest["images/Solenoid_on_front.jpeg"] %}
{% assign img38 = site.data.image_manifest["images/Solenoid_wiring_on_back.jpeg"] %}
{% assign img39 = site.data.image_manifest["images/solenoid_circuit_solenoid_connection.jpeg"] %}
{% assign img40 = site.data.image_manifest["images/ec11_soldered.jpeg"] %}
{% assign img41 = site.data.image_manifest["images/stabilizer_markings.jpeg"] %}
{% assign img42 = site.data.image_manifest["images/stabilizer_inserted.JPG"] %}
{% assign img43 = site.data.image_manifest["images/thumb_stabs.JPG"] %}
# ErgoDonk Zero build guide
{: .no_toc }

## Table of contents
{: .no_toc .text-delta }

1. TOC
{:toc}

## Tools and materials
- soldering iron and solder
- no-clean flux makes soldering easier
- solder wick or desoldering pump to correct mistakes
- good tweezers
- flush cutters to trim diode legs
- masking, kapton or electrical tape
- isopropyl-alcohol for cleaning
- Optional - magnetic 'third hand' PCB work holding fixture. (I'm partial to the little cones) 
- Optional - multimeter for troubleshooting. 
- Optional - [magnifier headband](https://www.amazon.com/Headband-Magnifier-eSynic-Rechargeable-Detachable/dp/B08W55R47Z).

## Assembly steps
This guide includes all optional components. 

<hr>

### Prepare

Make sure you know which side you are working on, and don't make two left hand sides by mistake. Stick a piece of tape on the front side of both PCBs to help remember.
{% comment %}
- @ todo add image of taped key plates
{% endcomment %}

The assembly order does not matter. This guide is written in the order I like to install components, starting with the components on the back, shortest to tallest:
 - diodes
 - switch sockets

Then install the components on the front:
 - Jumpers
 - RP2040 Zero MCU
 - TRRS connector
 - Solenoid components
 - Rotary encoder

<hr>

### Diodes

Diodes, surface mount or through-hole, should be installed on the back of the board. This allows for easy access after the keyplate is installed, and allows for the use of choc keyplates and stabilizers.

If you are hand soldering, through hole diodes are recommended because they are easier. If you damage a pad on one side, you can install the diode on the opposite side.

If you are using PCBA with surface mount diodes, either the front or the back will technically work, but surface mount diodes on the front will prevent the use of a choc keyplate.

There is one diode per key, and one for the rotary encoder. The right hand has more than the left hand.

When inserting diodes into the backs of the boards, you only need to insert diodes into the footprints that have an accompanying switch socket outline. For example, in this image, we are looking at the backside of the left hand board. The left hand does not have a switch 18, so there is no socket outline, and so no diode would be needed. If you do add a diode where it is not needed, there is no negative impact.<br>

<figure>
    {% include slider_img_srcset.html src="images/asymmetrical_diode_marking.jpeg" alt="Through hole diode orientation" manifest=img1 %}
<figcaption>No diode is needed where there is no socket outline.</figcaption>
</figure>

For surface mount diodes, a common soldering method is to tin one pad, place the diode on, apply the soldering iron to the diode leg until it melts the solder underneath and sinks flush with the PCB. Then come back and solder the other leg. Alternatively, you can use a rework station heat gun and solder paste. (I prefer this method for SMDs).
<figure class="image-grid-2">
{% include slider_img_srcset.html src="images/smd_diode_orientation_1.jpeg" alt="SMD orientation marking example" manifest=img2 %}
{% include slider_img_srcset.html src="images/smd_diode_orientation_2.jpeg" alt="SMD orientation example" manifest=img3 %}
<figcaption>SMD Orientation</figcaption>
</figure>

For through-hole diodes, pre-bending the legs while they are still on the paper strip makes inserting them much easier. You can use a 3d printed diode [bending jig](https://www.printables.com/model/734696-diode-bending-jig-8mm) to make quick uniform bends.<br>
<figure class="image-grid-2">
{% include slider_img_srcset.html src="images/diode_jig_fold.jpeg" alt="Using a carpenter" manifest=img4 %}
{% include slider_img_srcset.html src="images/diode_jig_cut.jpeg" alt="Using a carpenter" manifest=img5 %}
<figcaption>Diode bending jig in use.</figcaption>
</figure>

Alternatively, a carpenter's pencil is roughly the right size. (The diode holes are 8mm apart, wooden pencils are often 7mm - 8mm).<br>

<figure>
{% include slider_img_srcset.html src="images/carpenter_pencil.JPG" alt="Using a carpenter" manifest=img6 %}
<figcaption>Using a carpenter's pencil as a diode bending jig.</figcaption>
</figure>

With the PCB elevated via workholding, insert the bent diodes into the holes on the back of the board. 
Diodes _must_ be oriented with the black band in the direction of the "arrow" symbol on the PCB. There is also a black outline around the pad to make it easy to check the diode orientation is correct after the diode has been soldered in place.<br>
<figure>
{% include slider_img_srcset.html src="images/diode_orientation.jpeg" alt="Through hole diode orientation" manifest=img7 %}
<figcaption>Through hole diodes.</figcaption>
</figure>
<figure>
{% include slider_img_srcset.html src="images/ergodonk_bristling_with_diodes.jpeg" alt="Through hole diode orientation" manifest=img8 %}
<figcaption>Workholding jigs make room for diode legs.</figcaption>
</figure>
<figure class="image-grid-2">
    {% include slider_img_srcset.html src="images/LH_diode_locations.png" alt="Left hand diode locations on the back of the ErgoDonk zero keyboard" manifest=img9 %}
    {% include slider_img_srcset.html src="images/RH_diode_locations.png" alt="Right hand diode locations on the back of the ErgoDonk zero keyboard" manifest=img10 %}
<figcaption>Diode placement locations indicated by yellow circles.</figcaption>
</figure>

Solder the legs in place.

Flip over the board, and trim the legs.

When you trim off the diode legs, save 12 for use as jumpers.

<hr>

### Switch Sockets
Switch sockets are installed on the back of the PCB facing up towards the front of the PCB. Make sure they are flush with the PCB. 

1. Put all the sockets in place. PCB hole tolerance can vary quite a bit, so some sockets may snap in, while others rest in the holes. If you have some that snap in, be sure to check everything is flush before you start soldering. 
1. Solder _one_ side of each socket by heating the metal connector. Apply solder and look for the solder to wick down to the PCB. You want a solid joint since this may take some mechanical strain from switch installation and removal. The 3d printed workholding feet are really handy here. You can reposition the board as you work to get the best angle for soldering those connectors.
1. Give the board a few good taps to make sure there are no loose sockets.
1. Rotate the board 180 degrees and solder the remaining sides.

<figure class="image-grid-2">
{% include slider_img_srcset.html src="images/ergodonk_lh_sockets.jpeg" alt="ErgoDonk left hand backside indicating socket placement" manifest=img11 %}
{% include slider_img_srcset.html src="images/ergodonk_rh_sockets.jpeg" alt="ErgoDonk right hand backside indicating socket placement" manifest=img12 %}
<figcaption>Switch socket locations</figcaption>
</figure>

<hr>

### Jumpers
Because the MCU on both sides shares the same footprint, we need to set jumpers to ensure the power is routed correctly. The set of six jumpers for the right and left hands are marked accordingly. They can be soldered on the front or the back. Soldering on the front is recommended.

You can bridge the jumpers by dragging a blob of solder across the 2 adjacent pads. Modern rosin core solder can make this difficult. As an alternate bridging method, you can bend a diode leg and solder that in place. There is a bending jig to make it easy to bend jumpers to the optimal width. The bottom slot on the jig is for the jumpers.

<figure class="image-grid-3">
{% include slider_img_srcset.html src="images/bending_jigs.png" alt="Bending jig location" manifest=img13 %}
{% include slider_img_srcset.html src="images/jumper_bender_use.png" alt="Jumper bending jig in use" manifest=img14 %}
{% include slider_img_srcset.html src="images/jumpers.png" alt="Six bent jumpers made from diode legs" manifest=img15 %}
<figcaption>Jumper bending jig demonstration.</figcaption>
</figure>
<br>
<figure class="image-grid-3">
{% include slider_img_srcset.html src="images/jumpers_in_place.png" alt="Jumpers on the board that have not been soldered." manifest=img16 %}
{% include slider_img_srcset.html src="images/soldered_jumpers.png" alt="Soldered jumpers on the left hand of the ErgoDonk Zero" manifest=img17 %}
{% include slider_img_srcset.html src="images/clipping_jumpers.JPG" alt="clipping excess jumpers on the left hand of the ErgoDonk Zero" manifest=img18 %}
<figcaption>Jumpers from left to right, unsoldered, soldered, trimming.</figcaption>
</figure>

<hr>

### RP2040 Zero MCU
The Zero is installed on the top of the board, buttons facing up.

<figure class="image-grid-2">
{% include slider_img_srcset.html src="images/mcu_top_of_board_1.jpeg" alt="RP2040 Zero installed on the top of the left hand board of the ErgoDonk Zero keyboard" manifest=img19 %}
{% include slider_img_srcset.html src="images/mcu_top_of_board_2.jpeg" alt="RP2040 Zero installed on the top of both sides of the ErgoDonk Zero keyboard" manifest=img20 %}
<figcaption>Raspberry Pi Zero installed on ErgoDonk Zero</figcaption>
</figure>

* Top of the board: this is the side of the PCB opposite the diodes and switch sockets
* Marked holes: Insert the Zero into the holes with the rectangular outline on the top of the board. 

Install the Zero using the male-male headers that came with the Zero. (Or the low-profile headers, if you're feeling fancy)!
<ol>
<li>Insert the headers into the board and the Zero both before soldering. The header pin rows can tilt a little if it's not inserted into both the board and the Zero. The header pins that come with the zero have one longer side. Install the longer side on the PCB because you'll need to trim these, and the trimmed pins look better on the underside of the board. Use a piece of kapton tape to attach the Zero to the PCB while soldering.
If you are using a Zero with pre-soldered headers, you'll likely have to bend the headers a bit to get everything to line up perfectly. Once you get it in, the friction will keep it in place, and you can skip the tape.</li>
<li>Flip the board over. Solder 1 of the outermost pins on each pin header on the PCB. Hold the board up to make sure the pin header is sitting flush with the pcb. If it's not, you can reheat that joint until it is flush.
<figure>
{% include slider_img_srcset.html src="images/line_up_the_zero.JPG" alt="first pin line up of the MCU" manifest=img21 %}
<figcaption>Ensure the MCU is flush now to avoid re-soldering later.</figcaption>
</figure></li>
<li>Solder the remaining pcb/pin header joints on the back.</li>
<li>Flip the board over. With the Zero, repeat the process of soldering & checking 1 pin with the pin header and the Zero.</li>
<li>Solder all the remaining Zero/pin header pins.
<figure>
{% include slider_img_srcset.html src="images/solder_remaining_zero_pins.JPG" alt="RP2040 Zero MCU all pins soldered" manifest=img22 %}
<figcaption>MCU soldered nicely.</figcaption>
</figure></li>
</ol>

<hr>

### TRRS Jacks
Insert the jack into the outline on the front of the board. Some brands of jack will snap into the board, holding them in place. Others may need to be taped down. Then flip the board over and solder on the backside. Solder 1 pin first to check that everything is flush. Adjust as needed. Solder remaining pins.<br>

<figure class="image-grid-2">
{% include slider_img_srcset.html src="images/TRRS_front.JPG" alt="TRRS jack from the front" manifest=img23 %}
{% include slider_img_srcset.html src="images/TRRS_back.JPG" alt="TRRS jack from the back" manifest=img24 %}
<figcaption>TRRS jacks seen from top and bottom.</figcaption>
</figure>

<hr>

### Solenoid
The Solenoid is installed on the left hand front of the board _only_. Right hand installation is not supported. *Some of the build guide images show `1N4004` diode label on the board. You can use either `1N4001` or `1N4004`, they will both work.*

<ol>
<li>Put a piece of electrical tape on the backside of the tip120 and trim it to the outline. In some applications these get really hot so a heat sink _could_ be attached. Our application will never need that heat sink, but we don’t want that exposed metal against our board. Alternately, you can slap a sticker on there if you’re feeling fancy.
<figure class="image-grid-3">
{% include slider_img_srcset.html src="images/tip_tape_trim_1.jpeg" alt="tip120 with untrimmed tape insulation" manifest=img25 %}
{% include slider_img_srcset.html src="images/tip_tape_trim_2.jpeg" alt="tip120 with trimmed tape insulation" manifest=img26 %}
{% include slider_img_srcset.html src="images/tip_tape_trim_3.jpeg" alt="tip120 with sticker insulation" manifest=img27 %}
<figcaption>Tip120 insulation installation. Puffy cat sticker not required, but recommended.</figcaption>
</figure></li>
<li>Use the tip120 bending jig to get a 90 degree bend just below the fat part of the pins.
<figure class="image-grid-2">
{% include slider_img_srcset.html src="images/tip_120_jig_front.jpeg" alt="diode bending jig front" manifest=img28 %}
{% include slider_img_srcset.html src="images/tip_120_jig_back.jpeg" alt="diode bending jig back" manifest=img29 %}
<figcaption>Tip120 bending jig demonstration.</figcaption>
</figure></li>
<li>Insert the tip120 into the holes on the front of the board. Solder 1 pin, verify the tip120 is straight before soldering the remaining pins.
<figure class="image-grid-2">
{% include slider_img_srcset.html src="images/tip_120_in place.jpeg" alt="tip120 render showing the 90 degree bend" manifest=img30 %}
{% include slider_img_srcset.html src="images/solenoid_circuit_tip120.jpeg" alt="tip120 render showing the 90 degree bend" manifest=img31 %}
<figcaption>Tip120 placement and soldering.</figcaption>
</figure></li>
<li>Bend the legs of the 1k resistor using the bending jig on the left of the board.
<figure>
{% include slider_img_srcset.html src="images/resistor_bending.jpeg" alt="render demonstrating resistor bending jig" manifest=img32 %}
<figcaption>Diode bending jig demonstration.</figcaption>
</figure></li>
<li>Insert the 1k resistor into the holes on the front of the board. Orientation of the resistor does not matter. Solder in place.
<figure>
{% include slider_img_srcset.html src="images/solenoid_circuit_1k_resitor.jpeg" alt="1k resistor placement indicated" manifest=img33 %}
<figcaption>Solenoid resistor placement.</figcaption>
</figure></li>
<li>Bend the legs of the 1N4001 Schottky diode using the bending jig on the left of the board.
<figure>
{% include slider_img_srcset.html src="images/1N4001_diode_bending.jpeg" alt="render demonstrating resistor bending jig" manifest=img34 %}
<figcaption>Schottky diode bending jig.</figcaption>
</figure></li>
<li>Insert the 1N4001 Schottky diode into the holes on the front of the board. Be sure to orient the diode with the strip towards the top of the board. Solder in place.
<figure>
{% include slider_img_srcset.html src="images/solenoid_circuit_1N4001_diode.jpeg" alt="Schottky diode placement indicated" manifest=img35 %}
<figcaption>1N4001 Schottky diode placement.</figcaption>
</figure></li>
<li>Flip the board and trim the pins sticking out for the components you just installed.
<figure>
{% include slider_img_srcset.html src="images/solenoid_pin_nipping.jpeg" alt="trimming pins on the backside" manifest=img36 %}
<figcaption>Flush-cutting diode legs.</figcaption>
</figure></li>
<li>Using M2 screws, attach the solenoid to the top of the board. Run the wires through the big hole in the PCB. Tape the wires down with kapton tape. Solder onto the holes marked ‘solenoid’. Polarity does not matter, so either wire can go in either hole. Versions after 0.2.1 have an additional solenoid footprint connection point closer to the solenoid itself. This is to accommodate shorter wires. Either connection point will work.
<figure class="image-grid-3">
{% include slider_img_srcset.html src="images/Solenoid_on_front.jpeg" alt="Solenoid attached to the front of the left hand board by 2 M2 screws" manifest=img37 %}
{% include slider_img_srcset.html src="images/Solenoid_wiring_on_back.jpeg" alt="Solenoid wiring routed along the back of the board" manifest=img38 %}
{% include slider_img_srcset.html src="images/solenoid_circuit_solenoid_connection.jpeg" alt="Solenoid connection point indicated" manifest=img39 %}
<figcaption>Solenoid attachment.</figcaption>
</figure></li>
</ol>

<hr>

### Rotary encoders
Saved these for last because they are tallest. Insert into the top of the board, and solder on the backside. Some EC11s have metal tabs on opposite sides that add mechanical stability - no need to solder those tabs.
<br>
<figure>
{% include slider_img_srcset.html src="images/ec11_soldered.jpeg" alt="rotary encoder soldered to the PCB" manifest=img40 %}
<figcaption>Rotary encoder installation.</figcaption>
</figure>

<hr>

### Final assembly
Installing the stabilizers, keys and case.

<ol>
  <li>Install stabilizers. (Optional) The stabilizers are inserted into the front of the board, and screws are inserted on the back of the board. There are an abundance of holes around the pinky keys, so the stabilizer insertion holes have been marked with an arrow on the front of the board. Lay down the stabilizer stickers starting with the arrow side.
  <figure class="image-grid-2">
  {% include slider_img_srcset.html src="images/stabilizer_markings.jpeg" alt="stabilizer markings" manifest=img41 %}
  {% include slider_img_srcset.html src="images/stabilizer_inserted.JPG" alt="stabilizer installed on left hand shift key" manifest=img42 %}
  <figcaption>Stabilizer installation.</figcaption>
  </figure>
  <figure>
  {% include slider_img_srcset.html src="images/thumb_stabs.JPG" alt="thumb stabilizers installed" manifest=img43 %}
  <figcaption>Notice the thumb clusters stabilizers are back-to-back.</figcaption>
  </figure></li>
  <li>Snap switches into the corners of the key plate.</li>
  <li>Place the PCB on a flat surface. This will save some strain on the solder joints in the next step (though they should be able handle it).</li>
  <li>Carefully lower the top plate with switches on the main PCB and push into sockets. Ensure pins are aligned.</li>
  <li>Snap the remaining switches into the top plate pressing into the sockets.</li>
  <li>Place the encoder knob on the shaft. Tighten the set screw with a hex key. A small screwdriver for glasses may do in a pinch.</li>
  <li>@todo - update: Slide the four 8mm standoffs through the PCB and align to the holes on the key plate. Attach the standoffs to the keyplate using M2 screws.</li>
  <li>Attach the bottom plate to the four standoffs installed in the previous step.</li>
  <li>Use M2 screws to attach the three 12mm standoffs to the OLED cover plate.</li>
  <li>Slide the three standoff on the OLED plate through the PCB. Attach those standoffs to the backplate using M2 screws.</li>
  <li>Put at least 4 adhesive rubber feet in the corners so the keyboard is not moving when you type.</li>
</ol>

<hr> 

## Warnings and disclaimers
- Don't connect or disconnect the TRRS cable when the keyboard is powered. It may short out. Always disconnect the USB cable first.
- Be gentle with USB-C ports on your microcontrollers. They are easy to break.
- Keep in mind that this is a DIY keyboard. It’s not a polished product.
- If you find any errors or omissions in this build guide, please feel free to contribute. [See contributing page for more details.](../contributing)

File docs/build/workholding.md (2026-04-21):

---
layout: page
title: Soldering & Workholding
description: Suggested work holding and assembly methods 
parent: Build
permalink: /build/workholding
nav_order: 3
image: /images/workholding_jig_solder_from_top-1200w.webp
---

{% assign img1 = site.data.image_manifest["images/diode_bend_top.JPG"] %}
{% assign img2 = site.data.image_manifest["images/diode_bend_under.JPG"] %}
{% assign img3 = site.data.image_manifest["images/kapton_top.JPG"] %}
{% assign img4 = site.data.image_manifest["images/kapton_under.JPG"] %}
{% assign img5 = site.data.image_manifest["images/top_jig.JPG"] %}
{% assign img6 = site.data.image_manifest["images/workholding_jig_solder_from_top.JPG"] %}
{% assign img7 = site.data.image_manifest["images/ErgoDonk_zero_all_feet.JPG"] %}
{% assign img8 = site.data.image_manifest["images/Ergodonk_zero_one_foot.JPG"] %}
{% assign img9 = site.data.image_manifest["images/3d_model_of_work_feet.png"] %}

# Soldering and workholding

There are a few common soldering methods used with through-hole components. In this guide, we'll be using the third method - "work holding". Accordingly, the docs will not reference flipping the PCB over for soldering legs.

## The bendy method
Push the legs through the holes, then bend the legs slightly outward on the bottom side to keep the component in the hole when the PCB is flipped over. Solder on the side of the board opposite from the side the component was inserted.
<div class="image-grid-2">
    {% include slider_img_srcset.html src="images/diode_bend_top.JPG" alt="pcb with diode inserted from the top" manifest=img1 eager=true fetchpriority="high" %} 
    {% include slider_img_srcset.html src="images/diode_bend_under.JPG" alt="pcb with bent diode legs" manifest=img2 eager=true fetchpriority="high" %}
</div>
<hr>
## The tape method
Push the legs through the holes and put a piece of kapton tape over the component to keep it in place when the board is flipped. Solder on the side of the board opposite from the side the component was inserted.
<div class="image-grid-2"> 
    {% include slider_img_srcset.html src="images/kapton_top.JPG" alt="pcb with diodes held in place by kapton tape" manifest=img3 eager=true fetchpriority="low" %} 
    {% include slider_img_srcset.html src="images/kapton_under.JPG" alt="underside of pcb with diodes held in place by kapton tape" manifest=img4 eager=true fetchpriority="low" %} 
</div>
<hr>
## Work holding
Use helping hands or work holding jig to keep the PCB lifted off the work surface. Insert components through the holes, _do not_ flip the pcb, and solder on the side the components are inserted. This is the recommended method.

If you have access to a 3d printer, you can print disposable [work holding legs designed specifically for the ErgoDonk Zero PCB](https://www.printables.com/model/733164-ergodonk-zero-pcb-holding-feet).

### [Magnetic work holding thingies](https://www.aliexpress.us/item/2255800735314797.html)
<div class="image-grid-2">
{% include slider_img_srcset.html src="images/top_jig.JPG" alt="pcb in workholding jigs with diodes inserted from the top" manifest=img5 %} 
{% include slider_img_srcset.html src="images/workholding_jig_solder_from_top.JPG" alt="pcb in workholding jigs with diodes protruding" manifest=img6 %}
</div>

### [3d Printable work holding feet](https://www.printables.com/model/733164-ergodonk-zero-pcb-holding-feet)

<div class="image-grid-3">
{% include slider_img_srcset.html src="images/ErgoDonk_zero_all_feet.JPG" alt="Disposable 3d printable work holding legs for the ErgoDonk Zero" manifest=img7 %}
{% include slider_img_srcset.html src="images/Ergodonk_zero_one_foot.JPG" alt="Close up of a disposable 3d printable work holding leg for the ErgoDonk Zero" manifest=img8 %} 
{% include slider_img_srcset.html src="images/3d_model_of_work_feet.png" alt="3d model of a disposable 3d printable work holding leg for the ErgoDonk Zero" manifest=img9 %}
</div>

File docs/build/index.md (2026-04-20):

---
layout: page
title: Build
description: "Build guide index for the ErgoDonk Zero keyboard. Covers the full process: bill of materials, PCB ordering, workholding setup, and step-by-step assembly."
permalink: /build
nav_order: 2
has_children: true

---

# ErgoDonk Zero Build Guide

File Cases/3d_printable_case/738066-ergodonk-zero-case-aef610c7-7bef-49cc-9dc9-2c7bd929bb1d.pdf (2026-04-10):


18.46 hrs

6 pcs

f

0.30 mm

k

0.40 mm

h

PLA

347 g

d

Prusa
MK3/S/S+

## Summary

Case for the ErgoDonk Zero keyboard

Hobby & Makers (https://printables.com/model?categoryId=48) > Tools (https://printables.com/model?categoryId=49)

Tags: | ergonomic | splitkeyboard | ortholinear | ergodonk

Cases for the ErgoDonk Zero keyboard. (https://github.com/JellyTitan/ErgoDonk-Zero)

Tested with PCB v0.2.

Should only be used with MX switches.

Right and Left hand cases are unique and not interchangeable.
The keyplate stl is designed for the left hand, and for the right hand should be mirrored before printing.

You can add print helper objects to keep the edges from curling. There is a ‘sacrificial’ support below the bridge that connects the island in the middle of the thumb cluster. Snap that off by hand. (It's highlighted in the image

JellyTitan (https://printables.com/@JellyTitan)

## ErgoDonk Zero case

VIEW IN BROWSER (https://printables.com/model/738066-ergodonk-zero-case)

updated 17. 3. 2024 | published 17. 3. 2024

## Model files

## Print files

with the yellow arrow).
Use 8mm screws if the backplate is used. If no back plate is used, go with 4mm screws.

h PLA k 0.40 mm f 0.30 mm 2.36 hrs 34 g d Prusa MK3/S/S+

h PLA k 0.40 mm f 0.30 mm 2.36 hrs 34 g d Prusa MK3/S/S+

thickaronie_keyplate.stl

lh_bottom_plate.stl

lh-ergodonk-monobody.stl

rh_bottom_plate.stl

rh-ergodonk-monobody.stl

rh_thickplate_03mm_pla_mk3s_2h21m.gcode

lh_thickplate_03mm_pla_mk3s_2h22m.gcode h PLA k 0.40 mm f 0.30 mm 3.45 hrs 72 g d Prusa MK3/S/S+

h PLA k 0.40 mm f 0.30 mm 3.56 hrs 70 g d Prusa MK3/S/S+

h PLA k 0.40 mm f 0.30 mm 3.45 hrs 72 g d Prusa MK3/S/S+

h PLA k 0.40 mm f 0.30 mm 3.28 hrs 65 g d Prusa MK3/S/S+

## License

This work is licensed under a
Creative Commons (4.0 International License)

Attribution (http://creativecommons.org/licenses/by/4.0/)

✖ | Sharing without ATTRIBUTION
✔ | Remix Culture allowed
✔ | Commercial Use
✔ | Free Cultural Works
✔ | Meets Open Definition

rh_bottom_plate_03mm_pla_mk3s_3h27m.gcode

lh-ergodonk-monobody_03mm_pla_mk3s_3h33m.gcode

lh_bottom_plate_03mm_pla_mk3s_3h27m.gcode

rh-ergodonk-monobody_03mm_pla_mk3s_3h17m.gcode

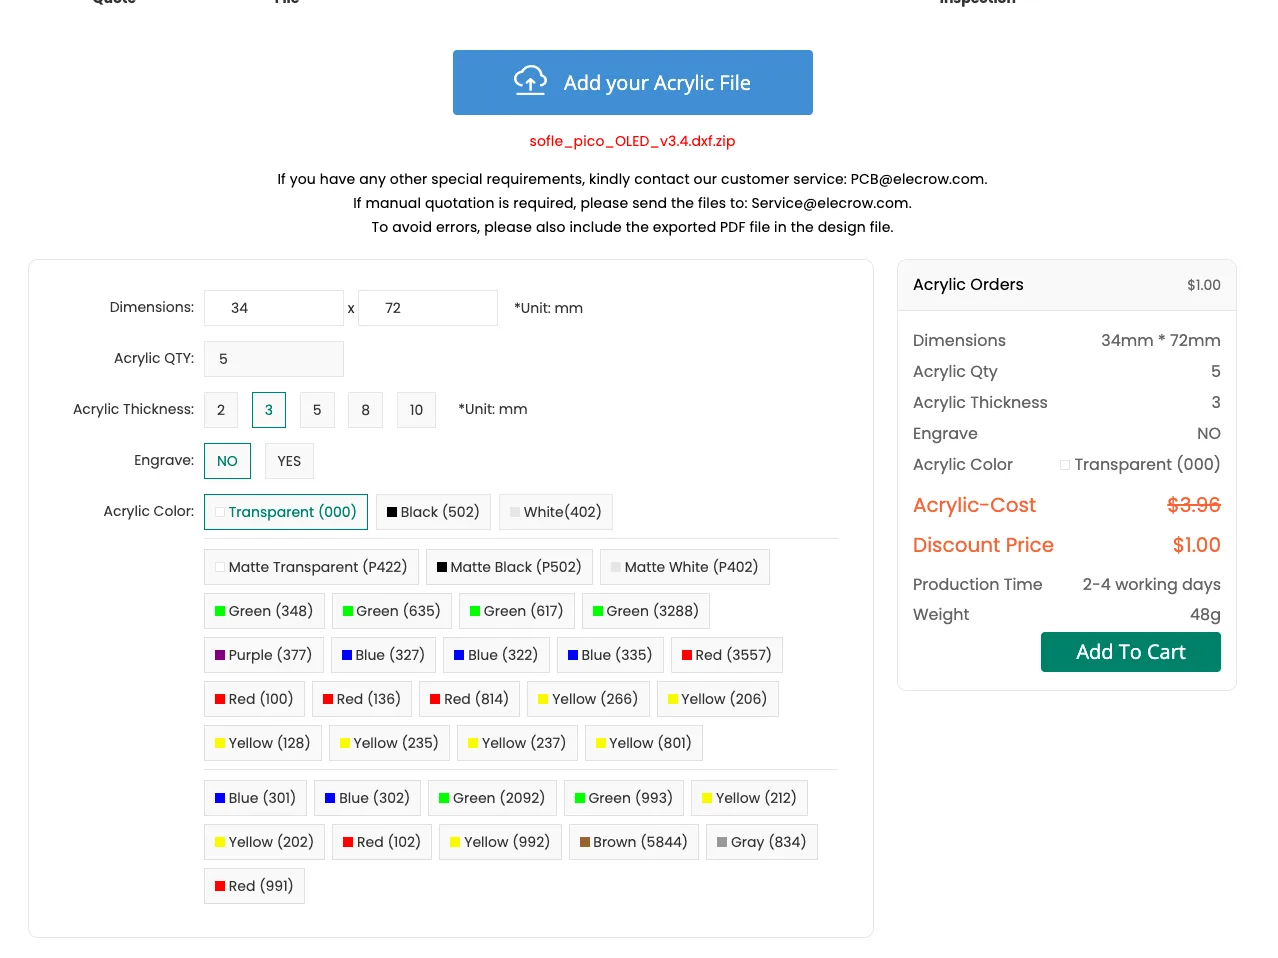
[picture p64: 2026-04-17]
docs/images/acrylic_ordering_guide/acrylic_ordering_guide-1278w.webp

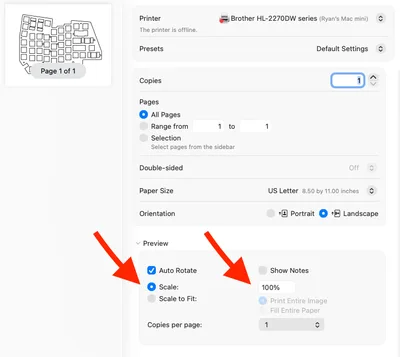
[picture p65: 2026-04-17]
docs/images/mvp_case/mvp_case_print_settings-400w.webp

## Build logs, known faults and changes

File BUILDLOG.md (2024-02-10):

## Build log:
### v0.1
* 11-20-2023 Sent out v0.1 to JLC for production
* Split off from the main ErgoDonk development repo for easier cleanup/maintenance.

### v0.2
* Confirmed v0.1 works as expected.
* Put a GND plane on both sides, wire VCC directly. (with big fat traces)!
* Added jumper jig to help bend jumper bridges.
* Move all traces from pads to the corners to prevent acid traps.
* Fix jumper bay graphics
* Changing pad connections on Polygons to 'Solid' - might be a bit harder to solder, but leads to better connections.
* Added key cap labels to each key.
* Increased key outlines and solenid component silks for improved legibility.
* Added key plate layer with stabilizer cutouts.
* **3.7795** is the keyplate multiplier when creating Fusion 360 imports
* Moved rotary encoder column up 2.5mm to avoid hitting encoder with my freakishly long thumbs.
* Added plates for RH/LH MCU Covers
* Moved mounting holes for MCU Covers
* Moved thumb 2u key diodes down to prevent stabilizer interference.
* Added markings to indicate stabilizer holes per side.
* Fixed protruding 'trace nub' on main footprint

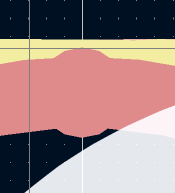
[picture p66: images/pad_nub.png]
pad nub

* Moved all diodes down a bit to make more room for choc keys
* Considered moving TRRS jack below vol buttons. Decided against it, as i like to keep things between the two halves of the keyboard, so keeping the cables higher up is preferred.
* Converted TRRS jack to TRS. 
* Refactored TRRS jack to remove full duplex. Replaced with serial default. Rerouted accordingly - then rolled it all back. I think it's better to leave the config for Full duplex available, but only implement serial communication. The full duplex config will probably be used in other ergodonk variants, and there is no urgent need for freeing up that extra pin.
* Via support added. It's on branch ergodonk_zero: https://github.com/JellyTitan/keyboards/blob/ergodonk_zero/v3/ergodonk_zero/ergodonk_zero.json
* Hid the case mount holes where possible. Where not possible, made them appear balanced & intentional.
* Ordered v0.2 PCB 1-11-2024.
* Ordered v0.2 Acrylic cases 1-12-2024

### v0.2.1
- Created footprints for plates. (key plate, back plate, MCU Covers Left & Right, and Solenoid cover).
- Removed solenoid outline on the LH top silks layer. I like the look better without the outline.
- Fixed unmasked nub on the switch footprint for connecting front/back.
- Added Tip120 bending jig.
- Improved diode markings
- Added additional solenoid connection footprint for solenoids that come with shorter wires.

- [x] Verified the TRRS/TRS jack works as expected. ()
- [x] Convert QMK config to Serial from full duplex.
- [ ] There may be a problem with the leftmost post hole intersecting the stabilizer:
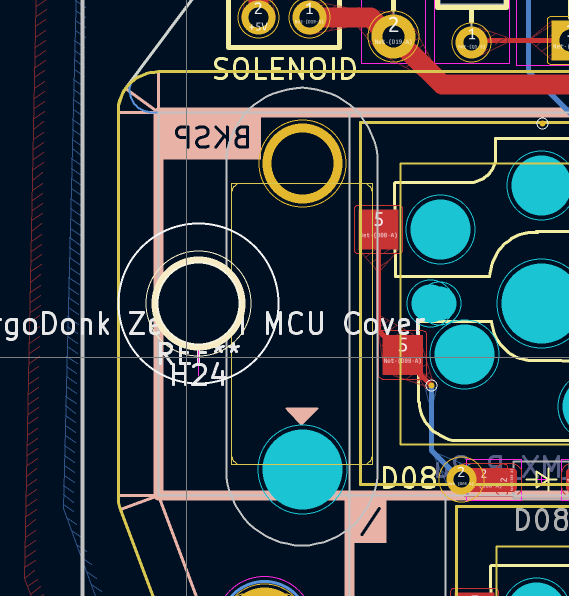
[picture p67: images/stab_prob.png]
post hole intersect

* Tried some alternate Solenoids. [This one from Sparkfun](https://www.sparkfun.com/products/11015) did not work. These [little](https://www.aliexpress.us/item/3256802092636163.html) [3V Solenoids](https://www.aliexpress.us/item/3256801967962531.html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) from Aliexpress did work, but the 'thunk' was not nearly as satisfying. I suspect the solenoid is not actually getting a Solid 5V. The [4.5V Uxcell Solenoid](https://www.amazon.com/gp/product/B013DR655A) initially recommended in the Red Herring seems to be the most forgiving of the under-voltage. Making that my official recommendation. 
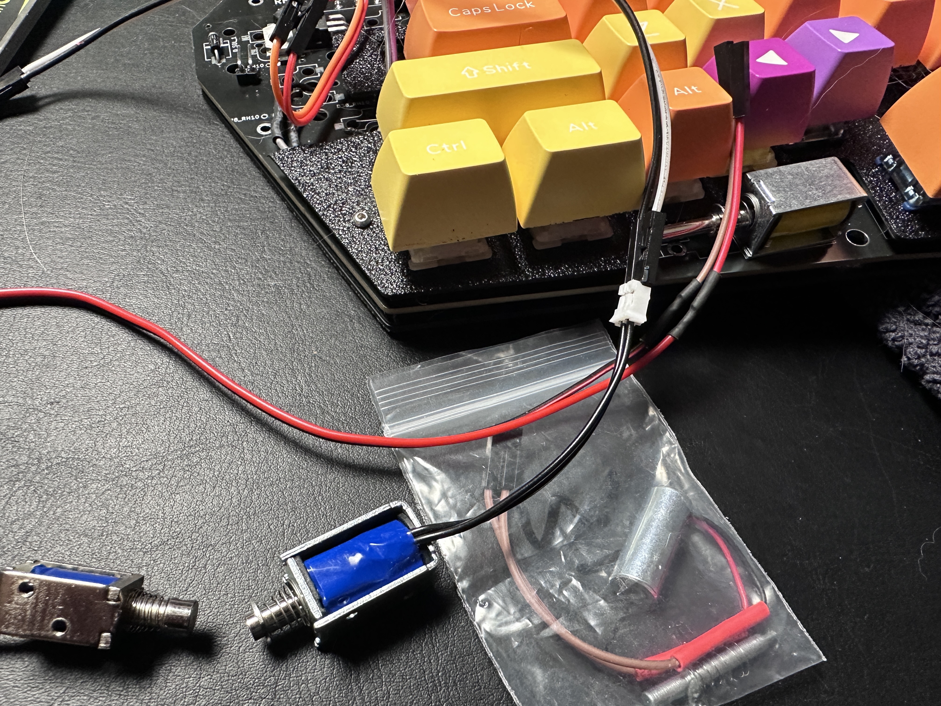
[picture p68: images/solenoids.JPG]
Solenoids

* Found another Soleniod on AliExpress that works, and added it to the BOM.
* The tenting puck did not work with MX footprints - it intersected the switch sockets. I added a second tenting puck, now there's one for choc and one for MX.

## Punch list
* [ ] Validate the new and old tenting puck holes are good.
* [ ] consider a key plate variant that has holes to attach a top plate. 
* [ ] Try putting a smaller 3v Solenoid on each hand.
* [ ] Add notes to the build guide, about how the symbols on the key cap should not correspond to the actual key presses., and the default layout is an adaptation of the ergodox.
* [ ] Add note about how great those magnetic data cables are.
* [ ] Add note in the build guide about the key layout using the ergonomic height of the SA keys and add images demponstrating. 
* [ ] Add a link to make it easy for users to contribute to documentation, like QMK has.
* [ ] Add note about the merits of AliExpress vs other vendors.
* [ ] Consider creating a choc key plate variant with cutouts for the diodes on the front?
* [ ] fix hot swap socket graphic with iconography. (Currently two red arrows - maybe a green check and a red 'no')?
* [ ] Create a tip120 bending jig.
* [ ] Strip GEO metadata from all images.
* [ ] Add diode punch outs for the bending jig
* [ ] Review pitch and tilt angle origion for ergo case. If the origin is the center of the board as opposed to the edge, what does that change?
* [ ] When using PCBA, all the matrix intersections will get a diode. I think this is what's breaking the handedness by matrix intersection setting in QMK. Consider add a jumper for the RH Backspace key, so that even if PCBA is used, the handedness detcetion by matrix intersection will still work.
* [ ] Use the Zero LED as a layer indicator. Example qmk_firmware/keyboards/handwired/alcor_dactyl
* [ ] Update case to include hole above layer indicator LED. 
* [x] Adjust key labels before production. (There are a few under holes)
* [ ] Before submitting QMK PR, update version number in `info.json`
* Add Solenoid installation to the README

## Features to add to future keyboards
* Space 2mm and 4mm case holes evenly around the perimeter for monoblock type cases.
* Consider moving TRS and Zero jack back a bit so they sit flush with the edge of the board. This would make it easier to use 'monoblock' cases.
* Be sure to rotate the thumb cluster keys when building a LED variant.

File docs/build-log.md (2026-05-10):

---
layout: page
title: Build Log
description: Full development history of the ErgoDonk Zero keyboard. Covers design decisions, PCB revisions from v0.1 through v0.2.1, firmware milestones, and lessons learned.
permalink: build-log
nav_order: 9
image: /images/solenoids-1200w.webp
---

{% assign img1 = site.data.image_manifest["images/pad_nub.png"] %}
{% assign img2 = site.data.image_manifest["images/stab_prob.png"] %}
{% assign img3 = site.data.image_manifest["images/solenoids.JPG"] %}
{% assign img4 = site.data.image_manifest["images/build-log/riverbottom_ergodonk_nameshare.png"] %}

# Build log
These are mostly personal notes to keep track of things during the development process.

## v0.1
* 11-20-2023 Sent out v0.1 to JLC for production
* Split off from the main ErgoDonk development repo for easier cleanup/maintenance.

## v0.2
* Confirmed v0.1 works as expected.
* Put a GND plane on both sides, wire VCC directly. (with big fat traces)!
* Added jumper jig to help bend jumper bridges.
* Move all traces from pads to the corners to prevent acid traps.
* Fix jumper bay graphics
* Changing pad connections on Polygons to 'Solid' - might be a bit harder to solder, but leads to better connections.
* Added key cap labels to each key.
* Increased key outlines and solenoid component silks for improved legibility.
* Added key plate layer with stabilizer cutouts.
* **3.7795** is the keyplate multiplier when creating Fusion 360 imports
* Moved rotary encoder column up 2.5mm to avoid hitting encoder with my freakishly long thumbs.
* Added plates for RH/LH MCU Covers
* Moved mounting holes for MCU Covers
* Moved thumb 2u key diodes down to prevent stabilizer interference.
* Added markings to indicate stabilizer holes per side.
* Fixed protruding 'trace nub' on main footprint
<figure>
{% include img_srcset.html src="images/pad_nub.png" alt="pad nub" manifest=img1 %}
</figure>
* Moved all diodes down a bit to make more room for choc keys
* Considered moving TRRS jack below vol buttons. Decided against it, as I like to keep things between the two halves of the keyboard, so keeping the cables higher up is preferred.
* Converted TRRS jack to TRS. 
* Refactored TRRS jack to remove full duplex. Replaced with serial default. Rerouted accordingly - then rolled it all back. I think it's better to leave the config for Full duplex available, but only implement serial communication. The full duplex config will probably be used in other ergodonk variants, and there is no urgent need for freeing up that extra pin.
* Via support added. It's on branch ergodonk_zero: https://github.com/JellyTitan/keyboards/blob/ergodonk_zero/v3/ergodonk_zero/ergodonk_zero.json
* Hid the case mount holes where possible. Where not possible, made them appear balanced & intentional.
* Ordered v0.2 PCB 1-11-2024.
* Ordered v0.2 Acrylic cases 1-12-2024

## v0.2.1
- Created footprints for plates. (key plate, back plate, MCU Covers Left & Right, and Solenoid cover).
- Removed solenoid outline on the LH top silks layer. I like the look better without the outline.
- Fixed unmasked nub on the switch footprint for connecting front/back.
- Added Tip120 bending jig.
- Improved diode markings
- Added additional solenoid connection footprint for solenoids that come with shorter wires.
- Verified the TRRS/TRS jack works as expected.
- Converted QMK config to Serial from full duplex. (Left the circuit in place for future ergodonk variants)
- There may be a problem with the leftmost post hole intersecting the stabilizer. (There's not - stabilizers are dumb and I hate them - also - if there is a key in that hole, there won't be a post - so the binary state makes it fine).
<figure>
{% include img_srcset.html src="images/stab_prob.png" alt="post hole intersect" manifest=img2 %}
</figure>
-  Tried some alternate Solenoids. [This one from Sparkfun](https://www.sparkfun.com/products/11015) did not work. These [little](https://www.aliexpress.us/item/3256802092636163.html) [3V Solenoids](https://www.aliexpress.us/item/3256801967962531.html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) from Aliexpress did work, but the 'thunk' was not nearly as satisfying. I suspect the solenoid is not actually getting a Solid 5V. The [4.5V Uxcell Solenoid](https://www.amazon.com/gp/product/B013DR655A) initially recommended in the Red Herring seems to be the most forgiving of the under-voltage. Making that my official recommendation.
<figure> 
{% include img_srcset.html src="images/solenoids.JPG" alt="Solenoids" manifest=img3 %}
</figure>
- Found another Solenoid on AliExpress that works, and added it to the BOM.
- The tenting puck did not work with MX footprints - it intersected the switch sockets. I added a second tenting puck, now there's one for choc and one for MX.
- Was issued a quasi-official USB-IF VendorID and ProductID through [pid.codes](pid.codes):<br>
[https://github.com/pidcodes/pidcodes.github.com/blob/master/1209/455A/index.md](https://github.com/pidcodes/pidcodes.github.com/blob/master/1209/455A/index.md)<br> 
[https://github.com/pidcodes/pidcodes.github.com/blob/master/org/JellyTitan/index.md](https://github.com/pidcodes/pidcodes.github.com/blob/master/org/JellyTitan/index.md)
- Found [another project](https://kbd.news/Ergodonk-released-792.html) [posted on thingiverse](https://www.thingiverse.com/thing:4892740) that uses the name 'ergodonk'. That project predates [my use of ergodonk](https://www.reddit.com/r/ErgoMechKeyboards/comments/12gs5or/ergodonk_easter_edition/) by a few years. I messaged user [Riverbottom on thingiverse](https://www.thingiverse.com/riverbottom/designs) to apologize. He was totally cool about it, and said I can have the name, but he will be leaving his existing Ergodonk in place. I think it's neat there's an ergodonk lineage, and I'd like to preserve it. I'll avoid using the name `Ergodonk` alone for any future keyboards, and instead use `ergodonk-<suffix>` for the standard naming conventions. 
<figure> 
{% include img_srcset.html src="images/build-log/riverbottom_ergodonk_nameshare.png" alt="conversation screen cap regarding ergodonk name usage" manifest=img4 %}
</figure>
- Ordered an acrylic backplate to validate `Ergodonk_Zero_v0.2.1_bottom_plate.dxf.zip` 7-29-2024. 

## v0.2.2
- The Solenoid circuit Schottky diode reference designator on the PCB was IN4004, it should have been IN4001, as indicated in the BOM. Updated PCB footprint, documentation.
- Picking back up on development after a year away. I can't find a full set of Choc keycaps. The choc layout hasn't been tested with a prototype. I think I validated the circuit with a multimeter - but I'm not 100%. 

May 9th 2026.
- after a few years away, I updated the QMK firmware. A ton of stuff has changed on the QMK side. I set handedness to default to master left, to simplify everything. (IF Rh is master, the solenoid won't work).
- Got a ton of help from Claude to bring everything up to speed.
- config.h: removes SOLENOID_MIN_DWELL (was default value) and NO_HAPTIC_MOD
- keyboard.json: removes redundant command/console false defaults and encoder_map feature (keymap-level only); reformats with qmk format-json
- keymaps/default/config.h: adds NO_HAPTIC_MOD at keymap level (user preference, not hardware requirement)
- keymaps/default/rules.mk: adds ENCODER_MAP_ENABLE (must be keymap-level per QMK guidelines)
- keymaps/default/keymap.c: replaces QK_MAKE/QK_BOOT/QK_RBT with KC_TRNS, DT_UP/DT_DOWN with KC_UP/KC_DOWN for a more pristine default.
- Updated default keymap image and KLE link in readme.md to reflect current layer 1 layout

May 10th 2026.
- Bootmagic keys moved to 'd' for left hand and 'j' for right hand. Now that the default is LH primary, when the RH is plugged in, it is perceived as the left. The asymmetrical key matrix combined with the removal of hand detection require this atypical setup. (Usually it's corner keys, like `del` and `esc`).
- Moving away from using the term `master`, replacing with `primary`.

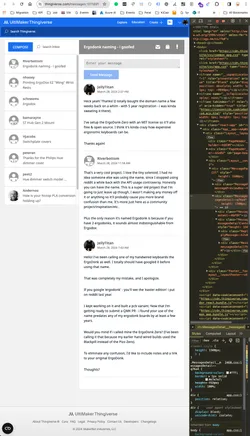
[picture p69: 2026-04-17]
docs/images/build-log/riverbottom_ergodonk_nameshare-250w.webp

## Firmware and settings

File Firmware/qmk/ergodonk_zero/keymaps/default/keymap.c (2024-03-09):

// Copyright 2022 Ryan Neff (@JellyTitan)
// SPDX-License-Identifier: GPL-2.0-or-later

#include QMK_KEYBOARD_H

enum custom_layers {
    _QWERTY,
    _LOWER,
    _RAISE,
    _ADJUST,
    _KEYCAPS,
    _CATSAFE,
};

/* Defines macros for use with the configurators "Any" key. (These are non-standard macros). */
/* Move active application right half. */
#define KC_CSGRA LCTL(LSFT(LGUI(KC_RGHT)))
/* Move active application to left half. */
#define KC_CSGLA LCTL(LSFT(LGUI(KC_LEFT)))
/* Maximize active application. */
#define KC_MAXI LCTL(LSFT(LGUI(KC_UP)))
/* Minimize active application. */
#define KC_MINI LCTL(LSFT(LGUI(KC_DOWN)))

/* Rotary encoder variables used to hold down Command (GUI) key while cycling through open programs. */
bool is_cmd_tab_active = false;
uint16_t cmd_tab_timer = 0;  

enum custom_keycodes {
    QWERTY = SAFE_RANGE,
    LOWER,
    RAISE,
    ADJUST,
    KEYCAPS,
    CATSAFE,
    CMD_TAB_CW,
    CMD_TAB_CCW,
};

/**
 * Tap Dance declarations
 */
enum tapdances {
    _TD_FIVE_ENTER,
    _TD_ESC_CATSAFE,
};

/* Tapdance */
#define TD_ENT5 TD(_TD_FIVE_ENTER)
#define TD_CATS TD(_TD_ESC_CATSAFE)
/**
 * Tap Dance definitions
 *
 * NOTE - if your not using tapdance, comment out:
 * TAP_DANCE_ENABLE = yes in rules.mk
 * define TAPPING_TERM 175 in config.h
 * else you'll get a compile error.
 *
 * To use this in the configurator, enter the name 'TD_ENT5' in the "Any" key.
 */
tap_dance_action_t tap_dance_actions[] = {
    /* Tap once for 5, twice for Enter. */
    [_TD_FIVE_ENTER] = ACTION_TAP_DANCE_DOUBLE(KC_5, KC_ENT),
    /* Tap once for Esc, twice to switch to a non-functional layer. (For cats on the keyboard)*/
    [_TD_ESC_CATSAFE] = ACTION_TAP_DANCE_DOUBLE(KC_ESC, TG(4)),
};

const uint16_t PROGMEM keymaps[][MATRIX_ROWS][MATRIX_COLS] = {
    [_QWERTY] = LAYOUT_split_6x9_6(
                //┌────────┬────────┬────────┬────────┬────────┬────────┬────────┬────────┐  
                  TD_CATS,  KC_F1,   KC_F2,   KC_F3,   KC_F4,  KC_F5,   KC_F6,                                         KC_F7,   KC_F8,   KC_F9  , KC_F10  , KC_F11  , KC_F12  , KC_DEL ,   
                  KC_GRV,   KC_1,    KC_2,    KC_3,    KC_4,   KC_5,    HF_TOGG, KC_VOLU,                      KC_PSCR, KC_INS , KC_6   , KC_7   , KC_8   , KC_9   , KC_0   , KC_MINS, KC_EQL ,KC_BSPC,
                  KC_TAB ,  KC_Q,    KC_W,    KC_E,    KC_R,   KC_T,    HF_DWLD, KC_VOLD,                      KC_SCRL, KC_DEL , KC_Y   , KC_U   , KC_I   , KC_O   , KC_P   , KC_LBRC, KC_RBRC,KC_BSLS, 
                  LT(1,KC_CAPS),LT(2,KC_A),LCTL_T(KC_S),KC_D,LGUI_T(KC_F),KC_G,HF_DWLD,KC_MUTE,                KC_PAUS, KC_5   , KC_H,RGUI_T(KC_J),KC_K,RCTL_T(KC_L),LT(2,KC_SCLN),LT(1,KC_QUOT), KC_ENT,
                  KC_LSFT,  LALT_T(KC_Z), KC_X,KC_C   , KC_V   , KC_B   , KC_MINI,    KC_HOME,                 KC_PGUP, KC_MAXI, KC_N   , KC_M   , KC_COMM, KC_DOT ,RALT_T(KC_SLSH), KC_RSFT, 	
         KC_LCTL, KC_LGUI,  KC_LALT, KC_LEFT, KC_RGHT, KC_SPC, KC_BSPC, KC_END,                                KC_PGDN, KC_TAB , KC_ENT , KC_UP  , KC_DOWN, KC_NO  , KC_RGUI, KC_RCTL,                                                          
                                                       QK_GESC,               KC_ENT,                                   KC_6   ,          KC_DEL   
    ),
    [_LOWER] = LAYOUT_split_6x9_6(
                  QK_BOOT , QK_MAKE , QK_RBT  , KC_TRNS , KC_TRNS , KC_TRNS , KC_TRNS ,                                  KC_TRNS , KC_TRNS, KC_TRNS, KC_TRNS, KC_TRNS, KC_TRNS, KC_TRNS,
		          KC_TRNS , KC_F1   , KC_F2   , KC_F3   , KC_F4   , KC_F5   , KC_TRNS ,  KC_TRNS,               KC_TRNS, KC_TRNS , KC_F6  , KC_F7  , KC_F8  , KC_F9  , KC_F10 , KC_F11 , KC_F12 , KC_TRNS, 
		          KC_TRNS , KC_EXLM , KC_AT   , KC_LCBR , KC_RCBR , KC_PIPE , KC_TRNS , KC_TRNS,                KC_TRNS, KC_TRNS , DT_PRNT, KC_7   , KC_8   , KC_9   , KC_ASTR, KC_TRNS, KC_TRNS, KC_TRNS, 
		          KC_TRNS , KC_HASH , KC_DLR  , KC_LPRN , KC_RPRN , KC_GRV  , KC_TRNS , KC_TRNS,                KC_TRNS, KC_TRNS , DT_UP  , KC_4   , KC_5   , KC_6   , KC_PPLS, KC_TRNS, KC_TRNS, 
		          KC_TRNS , KC_HASH , KC_DLR  , KC_LBRC , KC_RBRC , KC_TILD , KC_TRNS , KC_TRNS,                KC_TRNS, KC_TRNS , DT_DOWN, KC_1   , KC_2   , KC_3   , KC_PSLS, KC_TRNS,
	    KC_TRNS,  KC_TRNS , KC_TRNS , KC_TRNS , KC_TRNS , KC_TRNS , KC_TRNS , KC_TRNS ,                                  KC_TRNS , KC_TRNS, KC_TRNS, KC_0   , KC_0   , KC_TRNS, KC_TRNS, KC_TRNS,        
		                                        KC_TRNS ,                     KC_TRNS ,                                  KC_TRNS ,                   KC_0
    ),
    [_RAISE] = LAYOUT_split_6x9_6(
                  KC_TRNS , KC_TRNS , KC_TRNS , KC_TRNS , KC_TRNS , KC_TRNS , KC_TRNS ,                                 KC_TRNS , KC_TRNS , KC_TRNS , KC_TRNS , KC_TRNS , KC_TRNS , KC_TRNS,
		          RGB_TOG , KC_ACL0 , KC_ACL1 , KC_ACL2 , KC_TRNS , KC_TRNS , KC_TRNS , KC_TRNS,               KC_TRNS, KC_TRNS , KC_TRNS , KC_TRNS , KC_TRNS , KC_TRNS , KC_TRNS , KC_TRNS, KC_TRNS, KC_TRNS, 
		          KC_TRNS , KC_HASH , KC_TRNS , KC_MS_U , KC_TRNS , KC_TRNS , KC_TRNS , KC_TRNS,               KC_TRNS, KC_TRNS , KC_TRNS , KC_BTN1 , KC_UP   , KC_BTN2 , RGB_SAI , RGB_SAD, KC_TRNS, KC_TRNS, 
		          KC_TRNS , KC_TRNS , KC_MS_L , KC_MS_D , KC_MS_R , KC_TRNS , KC_TRNS , KC_TRNS,               KC_TRNS, KC_TRNS , KC_TRNS , KC_LEFT , KC_DOWN , KC_RGHT , RGB_VAI , RGB_VAD, KC_TRNS,
		          KC_TRNS , KC_TRNS , KC_TRNS , KC_TRNS , KC_TRNS , KC_TRNS , KC_CSGLA, KC_TRNS,               KC_TRNS, KC_CSGRA, KC_TRNS , KC_TRNS , KC_TRNS , KC_TRNS , RGB_SPI , RGB_SPD,
	    KC_TRNS,  KC_TRNS , KC_TRNS , KC_TRNS , KC_TRNS , KC_TRNS , KC_TRNS , KC_TRNS ,                                 KC_TRNS , KC_TRNS , KC_TRNS , KC_TRNS , KC_TRNS , KC_TRNS , KC_TRNS, KC_TRNS,     
		                                        KC_TRNS ,                     KC_TRNS ,                                 KC_TRNS ,                     KC_TRNS
    ),
    [_ADJUST] = LAYOUT_split_6x9_6(
                  KC_ESC , KC_F1  , KC_F2  , KC_F3  , KC_F4  , KC_F5  , KC_F6  ,                        KC_F7, KC_F8, KC_F9, KC_F10, KC_F11, KC_F12, KC_DEL,
		          KC_GRV , KC_1   , KC_2   , KC_3   , KC_4   , KC_5   , KC_ASTR, KC_VOLU,                          KC_PSCR, KC_INS, KC_6, KC_7, KC_8, KC_9, KC_0, KC_MINS, KC_EQL, KC_BSPC, 
		          KC_TAB , KC_Q   , KC_W   , KC_E   , KC_R   , KC_T   , KC_PGUP, KC_VOLD,                          KC_SLCT, KC_DEL, KC_Y, KC_U, KC_I, KC_O, KC_P, KC_LBRC, KC_RBRC, KC_BSLS, 
		          KC_CAPS, KC_A   , KC_S   , KC_D   , KC_F   , KC_G   , KC_PGDN, KC_MUTE,                          KC_NO, KC_5, KC_H, KC_J, KC_K, KC_L, KC_SCLN, KC_QUOT, KC_ENT, 
		          KC_LSFT, KC_Z   , KC_X   , KC_C   , KC_V   , KC_B   , KC_NO  , KC_HOME,                          KC_PGUP, KC_NO, KC_N, KC_M, KC_COMM, KC_DOT, KC_SLSH, KC_LSFT,
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

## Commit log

2023-11-21 First commit PCB pulled out of main ergodonk branch for cleanup
    [Ergodonk_simple_zero_BOM.csv, Ergodonk_simple_zero_PNP.csv, JUNCO PCB Assembly - ergodonk_simple_BOM (1) 2.csv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]
2023-11-21 Footprint library cleanup
    [ergodonk_simple_zero.kicad_sch]
2023-12-03 Added jumper jig moved pad connections to corners to minimize acid traps
    [ergodonk_simple_zero.kicad_sch]
2023-12-03 Imported pcb rules from sofle pico started converting power traces to 1mm
2023-12-03 Rewire to prevent acid traps updgrade VCC's to 1mm traces
2023-12-04 Added keycap labels updated RH exclusive component labels improved Solenoid circuit markings
    [ergodonk_simple_zero.kicad_sch]
2023-12-06 Thumb key cluster footprint size change updated keyplate stab holes
    [Ergodonk Zero v0.1 plates v5.stl, Ergodonk Zero v0.1 plates v8.stl, ergodonk_simple_zero.kicad_sch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]
2023-12-07 First draft of build guide Build guide adapted from Sofle Pico Split build log into sepearte file
2023-12-08 Improved MCU markings Added keyplate cutout for solenoid
    [SOL_HOLE.stl, ergodonk_simple_zero.kicad_sch]
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2023-12-09 Added bottom plate
    [Bottom_plate.stl, LH_MCU_PLATE.stl, RH_MCU_PLATE.stl]
2023-12-10 Moved thumb 2u key diodes down to prevent stabilizer interference
    [Glass dome rotary encoder knob v4.stl]
2023-12-10 Fixed protruding 'trace nub' on main footprint
2023-12-10 Moved solenoid circuit to allow for double-sided keyplate
2023-12-29 Moved diodes to make more room for choc switches Improved In4004 markings and changed footprint
    [ergodonk_simple_zero.kicad_sch]
2023-12-29 Added bending jigs Removed pin 1 markings from solenoid footprint
    [ergodonk_simple_zero.kicad_sch]
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2024-01-02 Updated TRRS jack location experimented with collapsing tRRS to TRS. (Decided against it)
    [ergodonk_simple_zero.kicad_sch]
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2024-01-12 Built solenoid plates Revised key plates Moved mounting holes to minimize or showcase THIS VERSION WAS SENT OUT FOR PRODUCTION ON 1-11-2024
    [ergodonk_simple_zero.kicad_sch]
2024-01-12 Updated versioning
    [ergodonk_simple_zero.kicad_sch]
2024-01-12 Added 3d models
    [ergodonk_simple_zero.kicad_sch]
2024-01-12 Added v0.2 acrylic case Cleaned up v0.1 case files
    [Bottom_plate.stl, Ergodonk Zero v0.1 plates v5.stl, Ergodonk Zero v0.1 plates v8.stl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]
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2024-01-13 Fixed key plate hole width bug Updated home position for keyplate footprints Generated bottom plate for acrylic production
    [Ergodonk_Zero_v0.2_bottom_plate.dxf, Ergodonk_Zero_v0.2_keyplate.dxf, ergodonk_simple_zero.kicad_sch]
2024-01-16 Fixed missing tenting puck holes in key plate
    [Ergodonk_Zero_v0.2_keyplate.dxf]
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2024-01-18 Updated diode bending jig distance Updated docs - put diodes on back for easy access
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2024-01-18 Added pcb ordering guide adapted from the Sofle Pico
2024-01-19 Fixed switch footprint double-sided masking 'nubs'
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2024-01-22 Added hotswop socket bom details added clipping jumper image
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2024-01-22 Added jack and MCU images
    [ergodonk_zero_workholding_feet.stl]
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2024-01-22 Fixes inconsitent Solenoid circuit labels
    [ErgoDonk Solering jig v19.f3d]
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2024-01-23 Fixed tip120 sticker images added solenoid pin nipping image
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2024-01-25 Added AliExpress Solenoid to BOM Updated TRS BOM links to specific products i have tried
2024-01-25 Fixed switched thumb keys for SA labels
    [ergodonk_simple_zero.kicad_sch]
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2024-01-27 Added switch notch cutouts to FDM case layer
    [Thickaronie_keyplate.stl]
2024-01-28 Revised bottom plate for additional tenting puck regenerated kicad 3d model regenerated production ready acrylic plate
    [Ergodonk_Zero_v0.2_bottom_plate.dxf]
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2024-02-09 Added alternate solenoid connection point
    [ergodonk_simple_zero.kicad_sch]
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2024-03-09 Adds custom gh workflow for just-the-docs build deploy
    Same config as used on Sofle Pico
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2024-06-03 v0.2.1 sent out to JLCPCB for production
    [Ergodonk_simple_zero_BOM.csv, Ergodonk_simple_zero_PNP.csv, JUNCO PCB Assembly - ergodonk_simple_BOM (1) 2.csv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]
2024-07-01 Fixed malformed Solenoid BOM table
2024-07-03 Changes PCB IN4004 reference designator to IN4001 Updates all documentation referencing IN4004
2024-07-03 Incramented version and updated build log
    [ergodonk_simple_zero.kicad_sch]
2024-07-30 Acrylic case files cleanup Updated acrylic backplate tenting puck cutout for both choc and MX
    [Bottom_plate.stl, Ergodonk Zero v0.1 plates v5.stl, Ergodonk Zero v0.1 plates v8.stl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]
2024-08-12 Updated acrylic case BOM with correct screw and ff standoff counts"
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2026-03-23 Bump activesupport in /docs in the bundler group across 1 directory
    Bumps the bundler group with 1 update in the /docs directory: [activesupport](https://github.com/rails/rails).
    Updates `activesupport` from 7.1.3.2 to 7.2.3.1
    - [Release notes](https://github.com/rails/rails/releases)
    - [Changelog](https://github.com/rails/rails/blob/v8.1.2.1/activesupport/CHANGELOG.md)
    - [Commits](https://github.com/rails/rails/compare/v7.1.3.2...v7.2.3.1)
    ---
    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
2026-04-09 Replaces html comment with liquid filtered comment
2026-04-10 Improves LCP by adding fetchpriority attribute Updates todos for the case section
2026-04-10 Adds fdm case source files
    [lh-ergodonk-monobody.stl, lh_bottom_plate.stl, rh-ergodonk-monobody.stl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]
2026-04-11 Fixes fdm case page and adds mvp case page wip
2026-04-12 Simplifies keyplate mirroring by splitting one file to two
    [Thickaronie_keyplate_LH.stl, Thickaronie_keyplate_RH.stl, thickaronie_keyplate.stl]
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2026-04-20 Fix spelling and grammar across documentation
    Corrects 44 spelling, grammar, and punctuation errors across 15 docs files. Renames 21 misspelled image files (asymetrical→asymmetrical, stabalizer→stabilizer, luxary→luxury) and updates all references.
2026-04-20 Improve SEO page titles across documentation
    Replaces generic titles (Overview, BOM, Flashing, VIA, Acrylic, etc.) with more descriptive ones that perform better in search. Expands BOM acronym, clarifies case page titles, and adds context to tool/process pages.
2026-04-21 Adds missing alt tags to BOM
2026-04-21 Trim build guide meta description to under 160 chars
    Was 174 chars, now 156 — within Google's display limit for SERP snippets.
2026-04-21 Fix cases sub-menu broken by title rename
    Child pages referenced parent: Cases but the parent title was
    renamed to Case Options — updated all four child pages to match.
2026-04-21 Update OG image front matter to webp variants
    Switches all page image: fields from original JPG/PNG/JPEG to
    1200w webp variants for faster social crawler fetches. Fixes a
    broken path on workholding.md (build_guide_pico dir didn't exist).
2026-04-23 Adds HowTo schema.org structured data to flashing, VIA, and PCB ordering guides
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2026-04-23 Converts BOM markdown tables to static HTML
    Prepares image cells for Jekyll includes, which require block-level HTML
    that markdown pipe tables cannot reliably contain.
2026-04-23 Runs image_swapper on non-table BOM images; extends isInTable to handle HTML tables
    Updates image_swapper.js to detect <td> lines in addition to pipe-syntax rows,
    so converted HTML tables are correctly excluded from processing.
2026-04-23 Converts case page markdown tables to HTML; reformats image includes for readability
    Converts acrylic-case.md and mvp-case.md BOM tables from markdown pipe syntax
    to static HTML so Liquid includes render correctly inside table cells. Wraps
    adjacent images in <p> tags for slider lightbox grouping. Reformats all
    slider_img_srcset_thumb includes to multi-line indented style.
2026-04-24 Fixes spelling, grammar, and @todo notes in BOM
    Corrects MCU name from "Raspberry Pi Zero" to "RP2040 Zero", fixes subject-verb
    agreement, comma splices, and missing punctuation throughout. Removes @todo
    annotations from user-facing table cells.
2026-04-24 Replace task list checkboxes with Unicode ballot box for WCAG 4.1.2
    Kramdown renders `[ ]` as unlabeled `<input type="checkbox" disabled>` elements,
    which fail WCAG 4.1.2 (Name, Role, Value). Switching to ☐ removes the unlabeled
    form control entirely, keeping the visual affordance as plain text.
2026-04-26 Fix WCAG 2.1 AA issues: table headers, link text, alt text, new-tab link
    - Add scope="col" to all <th> elements in BOM.md, acrylic-case.md, and
    mvp-case.md so screen readers can associate data cells with headers (1.3.1)
    - Replace ambiguous "here" link text with descriptive labels in acrylic-case.md,
    fdm-case.md, and BOM.md (2.4.4)
    - Deduplicate identical alt text on hero image grids in acrylic-case.md and
    mvp-case.md, and on solenoid cover plate images in acrylic-case.md (1.1.1)
    - Fix duplicate alt text on keyplate image in BOM.md (1.1.1)
    - Add rel="noopener noreferrer" and aria-label with new-tab notice to the
    hardcoded target="_blank" link on index.md (3.2.2)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
2026-04-26 Add HowTo structured data schema to BOM page
    Adds a schema.org HowTo with HowToSupply items covering all required and
    optional parts, wired through the existing schema frontmatter pattern.
2026-04-30 Load lightbox CSS non-blocking to avoid render-blocking request
    Uses the media="print" onload swap trick so the stylesheet does not
    block initial paint. Adds a noscript fallback for JS-disabled browsers.
